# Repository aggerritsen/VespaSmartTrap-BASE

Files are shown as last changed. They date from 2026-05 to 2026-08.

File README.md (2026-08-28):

# VST-BASE

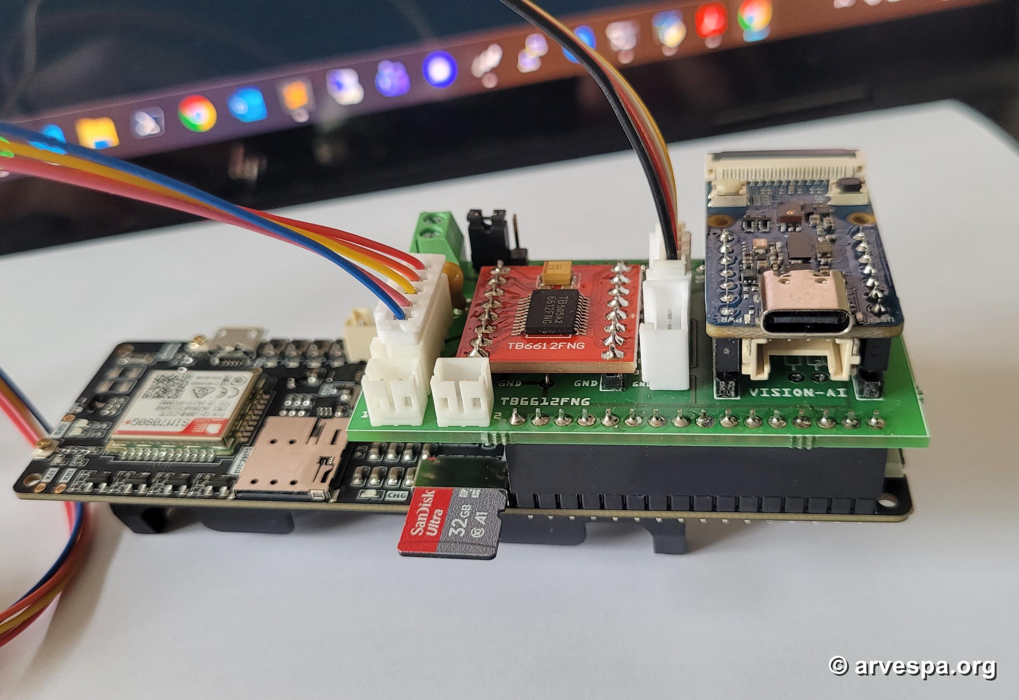
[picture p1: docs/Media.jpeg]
VST-BASE hardware


VST-BASE is the base-unit firmware, hardware integration reference, model tooling, and validation workspace for the Vespa Smart Trap project. The base unit is built around a LilyGO T-SIM7080G-S3 and receives inference metadata and JPEG frames from a Grove Vision AI V2 stick-on module through a custom PCB.

The root project is licensed under the GNU General Public License version 3.0. Keep source, build scripts, technical notes, and hardware references auditable and reproducible so that other developers can inspect, modify, rebuild, and redistribute the work under the repository's GNU license terms.

## Functionality

The current base firmware provides the following operational features:

- Power-on self test (POST) covering CPU, flash, heap, PSRAM, reset reason, SD card, configuration, modem, GNSS command path, UART, power telemetry, and actuator readiness.
- SD-MMC storage for configuration, boot reports, frame logs, power logs, and selected JPEG captures.
- SIM7080 modem initialization using TinyGSM, including AT readiness checks and network-time acquisition.
- Runtime Azure Blob upload of saved positive and configured doubtful detections, with independent cooldown and failure cooldown.
- Runtime SMS notification after positive detections, with provider-aware direct-SMS gating, recipient list, and cooldown.
- GNSS probing through the SIM7080 command interface, with optional GNSS UTC fallback when network time is unavailable and a trusted position is present.
- Binary UART receiver for the Grove Vision AI V2 module using `VSTS` state frames and `VSTJ` JPEG frames with metadata and CRC32 validation.
- Inference filtering by class, positive confidence threshold, doubtful confidence threshold, and occurrence count within a configurable time window before actuation.
- TB6612FNG stepper output for a configurable actuator cycle, including an optional boot-time POST cycle and a detection-triggered cycle.
- Short status LED POST test on GPIO 3 / D0 before runtime health LED policy is applied.
- WiFi web view in access-point or station mode, serving the latest verified frame and inference metadata over HTTP.
- JSON Lines frame logging with timestamp, GNSS data, inference result, bounding box, CRC status, actuator result, SMS/Azure result, saved filename, and firmware identity.
- Power telemetry logging to `/power.log` at a configurable interval.
- Solar auto-optimize mode that forces low-power runtime behavior from config: no WiFi, GNSS sampled once during boot, modem powered down after POST and runtime uploads, longer sleep protection, and reduced optional network checks.
- GV2 power control on the custom PCB: power down before deep sleep, power up after wake, and a short reset cycle before UART receive starts.
- Helper scripts for building and flashing the Grove Vision AI V2 firmware image and model.
- [VSTtool](https://vsttool.org) support for flashing firmware to the MCUs used in the project.
- Desktop image-viewer tooling and sample images for visual validation work.

## System Architecture

```text
T-SIM7080G-S3 base unit
        |
        +-- ESP32-S3 receiver firmware
        +-- SIM7080 modem time and GNSS probe
        +-- SD-MMC configuration, logs, and JPEG storage
        +-- WiFi HTTP image and state view
        +-- TB6612FNG stepper actuator output
        +-- USB serial POST and heartbeat monitor
        |
        +-- custom PCB interconnect
              |
              +-- Grove Vision AI V2 stick-on module
                    +-- camera
                    +-- YOLO11 object-detection model
                    +-- UART inference metadata and JPEG output
```

The T-SIM7080G-S3 is the base controller. The Grove Vision AI V2 is treated as an attached vision module, not as the system broker. The custom PCB provides the electrical and mechanical interface between the base, vision module, and actuator hardware references.

## 3D Housing

The physical camera-trap enclosure is documented in [3D/README.md](3D/README.md). That folder contains the prototype field-test manual, mechanical drawing PDF, STEP assembly, U3D model, DWG drawing views, and prototype photos for the VespaSmartTrap-ONE housing.

| Field prototype | Front/service side | Internal trap path |
| --- | --- | --- |
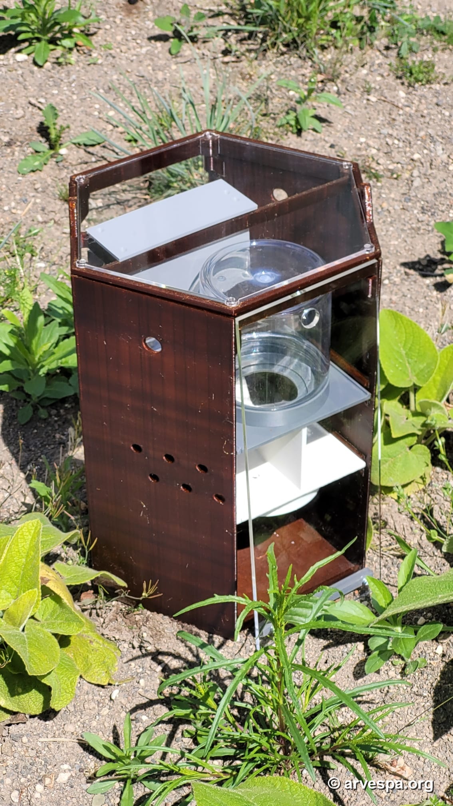
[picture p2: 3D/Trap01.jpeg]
VespaSmartTrap prototype in field conditions
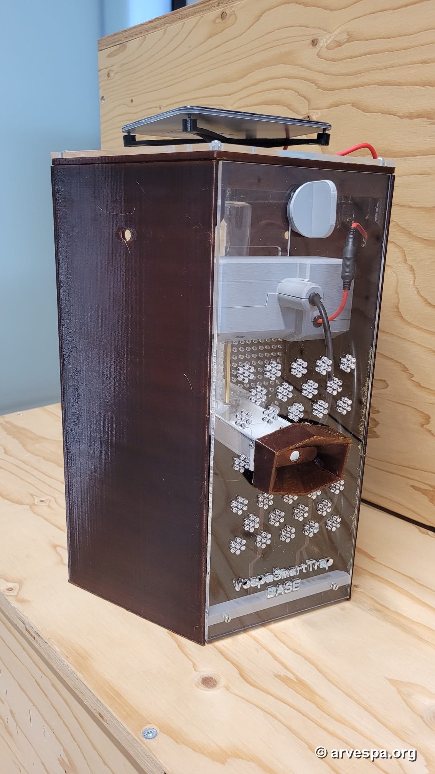
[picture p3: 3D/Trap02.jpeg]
VespaSmartTrap prototype front panel with electronics and actuator housing
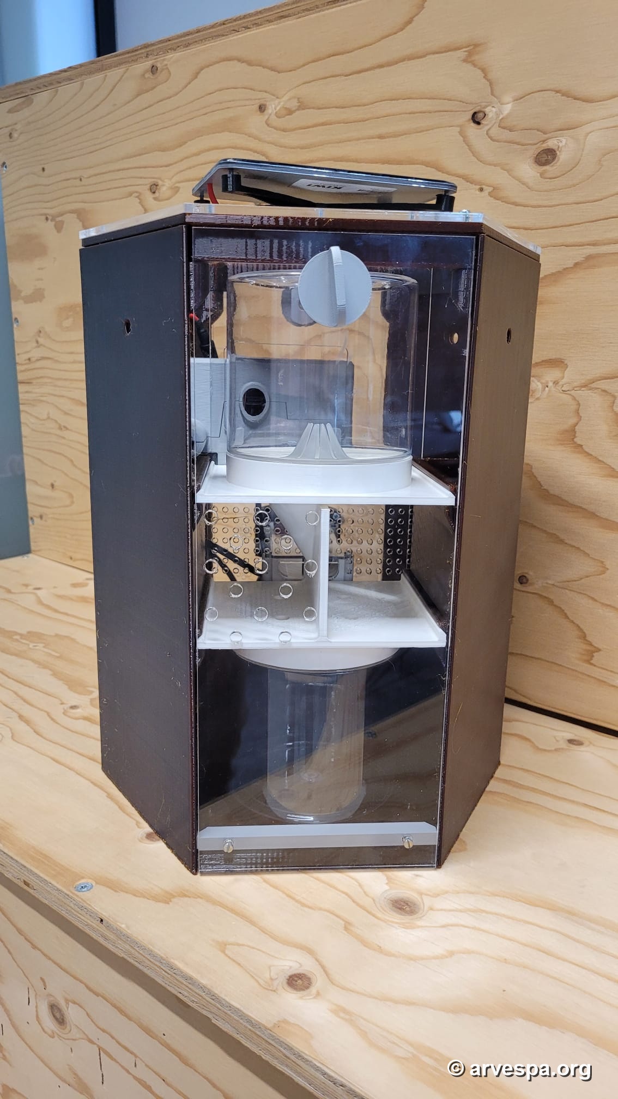
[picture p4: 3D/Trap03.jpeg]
VespaSmartTrap prototype internal funnel and trap jar path
|  |  |  |

## Technical Specifications

| Area | Specification |
| --- | --- |
| Base board | LilyGO T-SIM7080G-S3, built as `esp32-s3-devkitc-1` |
| Framework | PlatformIO, Arduino ESP32 core |
| Firmware version | `0.2.0` in `t-sim/firmware/src/version.h` |
| Flash | 16 MB, `huge_app.csv` partition table |
| PSRAM | Enabled, OPI/QIO memory configuration |
| USB serial | COM5 default, 115200 baud monitor |
| Upload | COM5 default, 921600 baud upload |
| GV2 UART | Serial2, GPIO 16 RX, GPIO 17 TX, 921600 baud default |
| GV2 protocol | `VSTS` state frames, `VSTJ` JPEG frames, CRC32 over JPEG payload |
| GV2 power control | GPIO 43 on the custom PCB, OFF during deep sleep and reset-cycled before UART start |
| Modem UART | Serial1, GPIO 4 RX, GPIO 5 TX |
| Modem power key | GPIO 41 |
| PMU | AXP2101 over I2C, SDA GPIO 15, SCL GPIO 7 |
| SD-MMC | 1-bit mode, CMD GPIO 39, CLK GPIO 38, DATA GPIO 40 |
| Actuator driver | TB6612FNG stepper output |
| Stepper pins | PWMA GPIO 9, AIN2 GPIO 10, AIN1 GPIO 11, BIN2 GPIO 12, BIN1 GPIO 13, PWMB GPIO 14 |
| Status output | Right LED / actuator-active signal on GPIO 3 / D0 |
| Web service | HTTP port 80, endpoints `/`, `/state.json`, `/frame.jpg` |
| Model target | Grove Vision AI V2 |
| Current model path | `gv2/firmware/model_zoo/tflm_yolo11_od/` |
| Current model files | `gv2-yolo11n-vespa-2026-02v1.tflite`, `gv2-yolo11n-vespa-2026-05top.tflite` |
| Model flash offset | `0xB7B000` |
| Model class short names | Configurable, defaults: `amel`, `vcra`, `vesp`, `vvel` |

## Repository Layout

```text
t-sim/firmware/               PlatformIO firmware for the T-SIM7080G-S3 base
t-sim/firmware/src/           Receiver firmware modules
t-sim/firmware/platformio.ini ESP32-S3 build, upload, monitor, and library config
t-sim/firmware/huge_app.csv   16 MB flash partition table
3D/                           Mechanical housing docs, CAD assets, drawing views, and prototype photos
docs/                         Architecture, protocol, hardware, GNSS, SD, and bring-up notes
docs/hardware/                Datasheets, pinouts, photos, and hardware references
gv2/firmware/                 Local isolated Grove Vision AI V2 firmware, image tools, and active model zoo
external/t-sim-motor-shield/  Submodule: custom PCB / motor shield reference
tools/image-viewer/           Desktop random image viewer and sample images
tools/receiver/               Receiver helper scripts
tools/Himax_AI_web_toolkit/   Local copy of the Himax web flashing toolkit
tools/power_uptime_visual.py  Builds the power/autonomy CSV and matplotlib timeline
data/power_uptime_dataset.csv Derived power/autonomy dataset from SD logs
data/power_uptime_plot.png    Power, operating-state, and temperature graph
gv2/build_gv2_image.ps1       GV2 firmware image build helper
gv2/flash_gv2.ps1             GV2 firmware and model flash helper
```

Submodules are intentionally kept under `external/` to make ownership and licensing boundaries clear.

## Firmware Boot Flow

At startup the receiver:

1. Starts USB serial and prints system information.
2. Initializes the SD card, creates `/config.json` when missing, and loads runtime configuration.
3. Enables modem rails and probes SIM7080 AT readiness.
4. Validates LTE-M/APN when modem mode is `2`, using SIM identity profiles first and candidate probing as fallback.
5. Attempts to obtain network time and set system time.
6. Optionally sends a POST SMS probe when `sms.post_test_enabled` is true.
7. Optionally uploads a small POST log probe when `azure.log_post_test_enabled` is true.
8. Powers and probes GNSS, optionally using trusted GNSS UTC as a fallback time source.
9. Powers the modem down after POST unless `modem.keep_alive_after_post` is true.
10. Starts the WiFi web service when enabled.
11. Initializes power telemetry and the stepper actuator.
12. Runs a short status LED POST test on GPIO 3 / D0.
13. Runs the optional stepper POST cycle when `stepper.post_test_enabled` is true.
14. Reset-cycles GV2 power on GPIO 43, starts GV2 UART, writes `/post.log`, and enters receive mode.

## UART Protocol

The base expects binary frames from the current GV2 firmware:

```text
State frame:
VSTS + state_u8

Heartbeat frame:
VSTH + status_u8 + counter_u32_le

JPEG frame:
VSTJ + state_u8 + class_idx_u8 + conf_u8
     + bbox_x_u16_le + bbox_y_u16_le + bbox_w_u16_le + bbox_h_u16_le
     + jpeg_len_u32_le + crc32_u32_le + jpeg_bytes
```

The GV2 heartbeat is an idle keepalive: it is sent after about 10 seconds of no other UART frames from GV2. A state change, JPEG frame, or error frame resets the heartbeat timer.

The JPEG payload length is the trimmed JPEG length through the actual `FFD9` marker. CRC32 is calculated over exactly those JPEG bytes. The receiver only treats a frame as complete after the declared payload has arrived, CRC32 matches, and the JPEG structure is valid.

## Detection And Actuation

The receiver evaluates each valid JPEG frame against the configured inference filter:

- `confidence_threshold`: required confidence as `0.0` to `1.0`.
- `doubtful_confidence_threshold`: lower confidence band used for evidence-only Azure upload.
- `detected_class`: target class index, or `-1` to accept any class.
- `occurrence`: number of matching frames required inside the occurrence window.
- `occurrence_window_seconds`: time window in which the required matches must occur.
- `upload_doubtful_to_azure`: when true, saves and runtime-uploads matching-class frames between the doubtful and positive thresholds.

When the positive threshold and occurrence count are reached inside the configured window, the firmware runs the configured stepper actuator cycle, flushes and resynchronizes the UART receive path after the blocking actuator movement, saves the triggering JPEG when the SD card is available, optionally sends SMS, and attempts runtime Azure upload. The occurrence counter resets after the actuator event.

Doubtful frames do not trigger the stepper and do not send SMS. When enabled, they are saved and sent through the same runtime Azure upload path. With `power.solar_auto_optimize=true`, doubtful-frame upload is disabled at runtime even if the loaded config sets `upload_doubtful_to_azure=true`; positive detections still use runtime photo upload.

## SD Card Files

The firmware creates or writes these files on the SD card:

```text
/config.json                  Runtime configuration, created if missing
/post.log                     Boot POST summary, overwritten each boot
/frames.log                   JSON Lines frame and detection log
/power.log                    JSON Lines power telemetry log
/vvel_0.859_YYYYMMDD_HHMMSS_000123.jpg Saved JPEGs with class short name and confidence
/vvel_0.859_uptime_0000000000_000123.jpg Fallback JPEG naming when time is unavailable
```

`/frames.log` includes device identity, firmware version, GNSS fields, inference state, bounding box, positive/doubtful filter result, CRC result, actuator result, SMS result, Azure result, cooldown status, and saved filename.

The firmware removes legacy Azure queue files (`/azure_queue.log`, `/azure_queue.work`, `/azure_queue.tmp`) on SD mount. New firmware does not use an upload queue.

Log rotation uses the same `logging` settings in VBUS and solar mode. `rotation_interval_minutes` accepts `60`, `360`, `720`, or `1440`, giving one shared rotation cadence for `health`, `power`, and `frames` logs. Closed log files are moved to `/log/archive/YYYYMMDD/` with timestamped names. Existing current logs found after boot are archived as `*_preboot_<timestamp>.jsonl` once valid time is available. Archive day folders older than `retention_days` are removed during rotation.

`upload_interval_minutes`, `upload_max_files_per_run`, and `upload_min_battery_percent` control scheduled upload of rotated log archives. The firmware scans `/log/archive/YYYYMMDD/` for the oldest `.jsonl` files, uploads at most `upload_max_files_per_run` per cycle to the Azure `logs` prefix, and deletes each local archive only after a successful upload. Failed uploads remain on SD and are retried during the next cycle. The upload policy is intentionally separate from `power.solar_auto_optimize`; solar mode must not silently change log retention or upload cadence.

## Power Autonomy Analysis

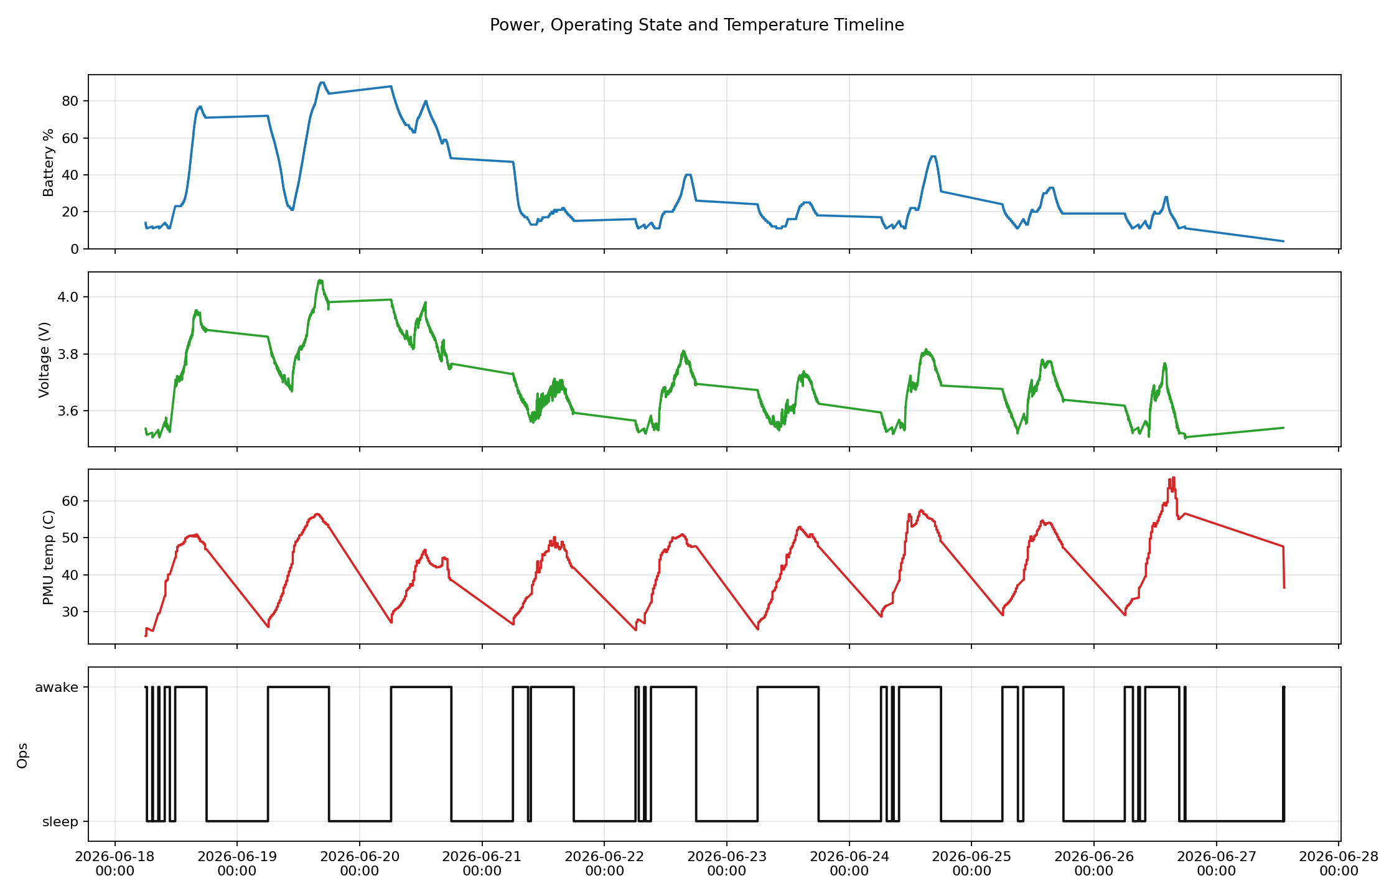
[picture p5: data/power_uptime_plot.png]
Power autonomy graph


The graph above is generated from the SD-card `health.log` and `power.log` files with:

```powershell
python tools\power_uptime_visual.py
```

The derived CSV is written to `data/power_uptime_dataset.csv`. The plotted operating-state line uses `awake` for normal logging/operation and `sleep` for inferred deep-sleep or offline gaps between health records.

From June 18 onward, the logs show a clear low-battery recovery followed by stable solar-supported operation. On June 18, the system clearly entered the 10% battery-protection region: the operating-state line shows repeated sleep/wake behavior, and the battery percentage and voltage start near the low-protection range. Later that day the battery recovers strongly.

On the following sunny days, June 19 and June 20, the system reaches almost full daytime realization, around 99% of the intended active window. The charge and discharge curves are smooth and plausible: the battery charges during sunny periods, discharges under load and overnight, and the PMU temperature follows the expected daytime thermal rise and nighttime cooldown.

This indicates that the 6 W solar panel is likely sufficient for this setup under the measured sunny conditions. The system can recover from low battery, sustain normal daytime operation, and retain enough charge margin across subsequent days.

## Configuration

Configuration is read from `/config.json` on the SD card. If it does not exist, the firmware writes a default file. Key fields include:

```json
{
  "schema_version": 1,
  "device_name": "VST-BASE",
  "uart": {
    "rx_gpio": 16,
    "tx_gpio": 17,
    "baud": 921600
  },
  "logging": {
    "post_log": "/post.log",
    "image_prefix": "/frame_",
    "rotation_interval_minutes": 60,
    "retention_days": 7,
    "upload_enabled": true,
    "upload_interval_minutes": 180,
    "upload_max_files_per_run": 4,
    "upload_min_battery_percent": 35
  },
  "features": {
    "gnss_probe": true,
    "ack_frames": true
  },
  "time": {
    "network_timeout_seconds": 60,
    "allow_gnss_fallback": true
  },
  "modem": {
    "mode": 2,
    "apn": "onomondo",
    "apn_autodetect": true,
    "apn_test_all": false,
    "validate_http_egress": false,
    "operator_auto_select": true,
    "keep_alive_after_post": false,
    "wake_for_runtime_sms": true,
    "apn_candidates": [
      { "supplier": "Onomondo", "apn": "onomondo" },
      { "supplier": "KPNThings", "apn": "internet.m2m" },
      { "supplier": "Wireless Logic Benelux", "apn": "" },
      { "supplier": "ThingsData/Tele2 2G-4G", "apn": "m2m.tele2.com" },
      { "supplier": "ThingsData/Tele2 5G", "apn": "iot.tele2.com" }
    ],
    "sim_profiles": [
      {
        "supplier": "Onomondo",
        "apn": "onomondo",
        "direct_sms": false,
        "imsi_prefixes": ["23450", "23873"],
        "iccid_prefixes": ["894573"]
      },
      {
        "supplier": "Wireless Logic Benelux",
        "apn": "internet.m2m",
        "direct_sms": true,
        "imsi_prefixes": ["20408"],
        "iccid_prefixes": []
      },
      {
        "supplier": "KPNThings",
        "apn": "internet.m2m",
        "direct_sms": true,
        "imsi_prefixes": ["20408"],
        "iccid_prefixes": []
      },
      {
        "supplier": "ThingsData/Tele2 2G-4G",
        "apn": "m2m.tele2.com",
        "direct_sms": true,
        "imsi_prefixes": ["20402", "24007"],
        "iccid_prefixes": ["894620"]
      }
    ],
    "lookup_primary": "1.1.1.1",
    "lookup_secondary": "8.8.8.8"
  },
  "stepper": {
    "speed_steps_per_second": 400,
    "rotation_degrees": 90,
    "steps_per_revolution": 2048,
    "reverse_wait_ms": 1000,
    "start_direction": "cw",
    "post_test_enabled": true
  },
  "inference": {
    "confidence_threshold": 0.80,
    "doubtful_confidence_threshold": 0.70,
    "upload_doubtful_to_azure": true,
    "detected_class": 3,
    "occurrence": 3,
    "occurrence_window_seconds": 30,
    "class_names": [
      { "class": 0, "short": "amel", "name": "Apis mellifera" },
      { "class": 1, "short": "vcra", "name": "Vespa crabro" },
      { "class": 2, "short": "vesp", "name": "Vespula sp." },
      { "class": 3, "short": "vvel", "name": "Vespa velutina" }
    ]
  },
  "power": {
    "log_interval_seconds": 900,
    "solar_auto_optimize": true,
    "deep_sleep": 2,
    "deep_sleep_start_hour": 18,
    "deep_sleep_end_hour": 6,
    "low_battery_sleep_percent": 10,
    "low_battery_wake_interval_minutes": 60,
    "reboot_cron": "",
    "reboot_after_deep_sleep_wakeup": false
  },
  "health": {
    "led": 1
  },
  "azure": {
    "cooldown_minutes": 15,
    "failure_cooldown_seconds": 120,
    "runtime_connect_timeout_seconds": 20,
    "photos_prefix": "photos",
    "logs_prefix": "logs",
    "log_post_test_enabled": true
  },
  "sms": {
    "enabled": false,
    "post_test_enabled": false,
    "runtime_settle_ms": 2000,
    "runtime_delay_after_detection_seconds": 0,
    "runtime_submit_timeout_ms": 60000,
    "cooldown_minutes": 15,
    "failure_cooldown_seconds": 900,
    "recipients": []
  },
  "web": {
    "mode": 2,
    "ssid": "VST-BASE",
    "password": "",
    "append_mac": true
  }
}
```

The default file deliberately keeps ordinary VBUS-friendly values such as `web.mode=2`, `health.led=1`, and `inference.upload_doubtful_to_azure=true`, but `power.solar_auto_optimize` is `true` by default. On boot, that flag converts some loaded configuration values to the lower-power effective runtime settings listed below. Set `power.solar_auto_optimize=false` to use the explicit values as-is, for example in VBUS/debug mode.

### Power Profiles

Use `power.solar_auto_optimize` as the profile switch. When it is `false`, the firmware follows the explicit values in `/config.json`. When it is `true`, the firmware keeps the configured identity, APN, inference class, thresholds, actuator settings, and upload credentials, but applies the lowest-power runtime policy after config parsing.

Solar auto-optimize forces these effective settings at runtime:

```json
{
  "features": {
    "gnss_probe": true
  },
  "time": {
    "network_timeout_seconds": 30,
    "allow_gnss_fallback": true
  },
  "modem": {
    "keep_alive_after_post": false,
    "wake_for_runtime_sms": true,
    "apn_test_all": false,
    "validate_http_egress": false
  },
  "inference": {
    "upload_doubtful_to_azure": false
  },
  "power": {
    "deep_sleep": 2,
    "deep_sleep_start_hour": 18,
    "deep_sleep_end_hour": 8,
    "low_battery_sleep_percent": 25,
    "low_battery_wake_interval_minutes": 120
  },
  "azure": {
    "cooldown_minutes": 60,
    "failure_cooldown_seconds": 1800,
    "runtime_connect_timeout_seconds": 20,
    "photos_prefix": "photos",
    "logs_prefix": "logs",
    "log_post_test_enabled": true
  },
  "sms": {
    "post_test_enabled": false
  },
  "web": {
    "mode": 0
  }
}
```

Recommended Solar profile:

```json
{
  "features": {
    "gnss_probe": true,
    "ack_frames": true
  },
  "time": {
    "network_timeout_seconds": 30,
    "allow_gnss_fallback": true
  },
  "modem": {
    "mode": 2,
    "apn": "onomondo",
    "apn_autodetect": true,
    "apn_test_all": false,
    "validate_http_egress": false,
    "operator_auto_select": true,
    "keep_alive_after_post": false,
    "wake_for_runtime_sms": true
  },
  "inference": {
    "confidence_threshold": 0.80,
    "doubtful_confidence_threshold": 0.70,
    "upload_doubtful_to_azure": false,
    "detected_class": 3,
    "occurrence": 3,
    "occurrence_window_seconds": 30
  },
  "power": {
    "log_interval_seconds": 900,
    "solar_auto_optimize": true,
    "deep_sleep": 2,
    "deep_sleep_start_hour": 18,
    "deep_sleep_end_hour": 8,
    "low_battery_sleep_percent": 25,
    "low_battery_wake_interval_minutes": 120,
    "reboot_cron": "",
    "reboot_after_deep_sleep_wakeup": false
  },
  "health": {
    "led": 1
  },
  "azure": {
    "cooldown_minutes": 60,
    "failure_cooldown_seconds": 1800,
    "runtime_connect_timeout_seconds": 20,
    "photos_prefix": "photos",
    "logs_prefix": "logs",
    "log_post_test_enabled": true
  },
  "sms": {
    "enabled": false,
    "post_test_enabled": false
  },
  "web": {
    "mode": 0
  }
}
```

In this profile GNSS is sampled once during boot with `AT+CGNSPWR=1`, the resulting trusted location/time is kept in memory and logs, and the modem is powered down after POST. Runtime Azure/SMS paths wake LTE only for the transfer window and power it down again. `power.solar_auto_optimize` does not override `health.led`; health-status blinking runs only when `health.led=1` and USB/VBUS power is present. The status LED is also driven on while an actuator cycle is running in any power mode.

The measured solar logs support stopping at `18:00`: it avoids evening discharge and preserves battery for the next boot. Starting at `08:00` is practical, but `09:00` or `10:00` is safer for maximum autonomy. For a harsher winter or cloudy profile, use `deep_sleep_start_hour=17` and `deep_sleep_end_hour=10`.

Recommended VBUS profile:

```json
{
  "features": {
    "gnss_probe": true,
    "ack_frames": true
  },
  "time": {
    "network_timeout_seconds": 60,
    "allow_gnss_fallback": true
  },
  "modem": {
    "mode": 2,
    "apn": "onomondo",
    "apn_autodetect": true,
    "apn_test_all": false,
    "validate_http_egress": false,
    "operator_auto_select": true,
    "keep_alive_after_post": false,
    "wake_for_runtime_sms": true
  },
  "inference": {
    "confidence_threshold": 0.80,
    "doubtful_confidence_threshold": 0.70,
    "upload_doubtful_to_azure": true,
    "detected_class": 3,
    "occurrence": 3,
    "occurrence_window_seconds": 30
  },
  "power": {
    "log_interval_seconds": 900,
    "solar_auto_optimize": false,
    "deep_sleep": 0,
    "deep_sleep_start_hour": 18,
    "deep_sleep_end_hour": 6,
    "low_battery_sleep_percent": 10,
    "low_battery_wake_interval_minutes": 60,
    "reboot_cron": "",
    "reboot_after_deep_sleep_wakeup": false
  },
  "health": {
    "led": 1
  },
  "azure": {
    "cooldown_minutes": 15,
    "failure_cooldown_seconds": 120,
    "runtime_connect_timeout_seconds": 20,
    "photos_prefix": "photos",
    "logs_prefix": "logs",
    "log_post_test_enabled": true
  },
  "web": {
    "mode": 2,
    "ssid": "VST-BASE",
    "password": "",
    "append_mac": true
  }
}
```

VBUS mode can keep the health LED and web AP enabled for field inspection. Keep `modem.keep_alive_after_post=false` unless you are actively debugging LTE behavior; runtime upload and SMS already wake the modem when needed.

`device_name` is suffixed at runtime with the WiFi MAC suffix, matching the web SSID style, for example `VST-BASE-A62E94`. `web.mode` values are `0` for disabled, `1` for WiFi station mode, and `2` for access-point mode. `stepper.start_direction` accepts common clockwise and counter-clockwise forms such as `cw`, `clockwise`, `ccw`, and `anti-clockwise`.

Azure image upload is runtime-only. A saved positive or configured doubtful image is uploaded immediately when the Azure cooldown allows. If cooldown is active the image remains saved on SD but is not queued. If upload fails, the failure cooldown is applied and the image is not queued.

Azure uploads use one configured container and separate blob prefixes inside it. Photos default to `photos/...`; the optional POST log-upload probe defaults to `logs/...`. Set `azure.log_post_test_enabled=true` to write and upload a small JSON Lines test file during POST after LTE-M validation and before the modem is powered down. Rotated log archives upload to `logs/<device_name>/<YYYYMMDD>/<filename>.jsonl` and are removed from SD after successful upload.

SMS is runtime-only unless `sms.post_test_enabled` is explicitly true. `sms.enabled` is authoritative: recipients may be present while SMS remains disabled. SMS is skipped for providers whose selected SIM profile has `direct_sms=false`, such as Onomondo in the default profile set.

The modem APN is selected from SIM identity first (`sim_profiles` by IMSI/ICCID prefixes), then by configured APN candidate probing. Known default profiles cover Onomondo, Wireless Logic Benelux, KPNThings, and ThingsData/Tele2 2G-4G.

`power.reboot_cron` uses a five-field cron-like schedule after valid system time is available. For example, `0 12 * * *` reboots daily at noon. Leave it empty to disable scheduled reboot.

Low-battery protection is separate from the scheduled sleep window. With `power.solar_auto_optimize=true`, a battery-powered unit sleeps when the PMU reports `25%` or lower and wakes every `120` minutes to re-check the battery. If solar has recovered the battery above the configured threshold, normal startup continues; otherwise it returns to deep sleep before modem, web, stepper, or GV2 runtime work starts. If the unit is inside the programmed sleep window, or the next low-battery check would wake inside that window, the firmware sleeps through to the configured wake hour. With `power.solar_auto_optimize=false`, the explicit configured low-battery threshold and wake interval are used.

## Build And Flash The Base Firmware

Install PlatformIO, connect the T-SIM7080G-S3, then run:

```powershell
cd firmware
.\run.ps1
```

The helper uploads to COM5 and opens the serial monitor on COM5 at 115200 baud by default. Override the ports when needed:

```powershell
.\run.ps1 -UploadPort COM5 -MonitorPort COM5
```

The underlying PlatformIO environment is `t-sim7080g-s3`.

[VSTtool](https://vsttool.org) also exists as a dedicated flashing utility for firmware updates on the MCUs used by VST-BASE. Use it when you need a single tool-oriented flashing workflow instead of the board-specific helper scripts above and below.

## Build And Flash The GV2 Firmware

Initialize submodules before building GV2 assets:

```powershell
git submodule update --init --recursive
```

Build the GV2 firmware image:

```powershell
.\gv2\build_gv2_image.ps1
```

Flash the GV2 firmware image and model:

```powershell
.\gv2\flash_gv2.ps1 -Port COM7
```

The flash helper uses `gv2/firmware/xmodem/xmodem_send.py` and expects the generated image at:

```text
gv2/firmware/we2_image_gen_local/output_case1_sec_wlcsp/output.img
```

The active GV2 model binaries are intentionally kept in the local GV2 firmware copy for reproducible release builds.

## Dependencies

Base firmware dependencies are declared in `t-sim/firmware/platformio.ini`:

- Arduino ESP32 core through PlatformIO `espressif32`.
- TinyGSM from `https://github.com/vshymanskyy/TinyGSM.git`.
- XPowersLib by `lewisxhe` for AXP2101 PMU support.
- ArduinoJson `^7.0.0`.
- ESP32 Arduino built-ins such as `SD_MMC`, `WiFi`, and `WebServer`.

GV2 firmware dependencies are isolated inside `gv2/firmware`.

## External Repositories

```text
gv2/firmware
  source: isolated local copy of the Grove Vision AI V2 firmware fork

external/t-sim-motor-shield
  url:    https://github.com/aggerritsen/T-SIMMotorShield.git
  branch: master
```

Clone with submodules:

```powershell
git clone --recurse-submodules <repo-url>
```

Or initialize them after cloning:

```powershell
git submodule update --init --recursive
```

## Public Development And GNU Licensing

This repository is licensed under the GNU General Public License version 3.0. See `LICENSE` for the full license text. For public releases, keep these practices in place:

- Preserve license notices in source files and third-party materials.
- Keep submodules and bundled tools in clearly separated directories so their upstream licenses remain identifiable.
- Document generated firmware, model binaries, and hardware artifacts well enough that users can rebuild or replace them.
- Avoid committing private credentials, SIM/APN secrets, WiFi passwords, certificates, or personal device identifiers.
- Prefer reproducible build commands and versioned configuration over local-only IDE state.

Third-party submodules and bundled tools may have their own licenses. Review those license files before redistributing combined firmware images, model packages, or hardware packages.

## Documentation Index

- `t-sim/firmware/README.md`: detailed receiver firmware behavior, pins, protocol, validation, and source-file map.
- `3D/README.md`: physical housing, CAD assets, mechanical drawing views, and prototype photos.
- `docs/architecture.md`: high-level hardware and firmware architecture.
- `docs/receiver-post.md`: POST behavior.
- `docs/sd-card-layout.md`: SD output notes.
- `docs/gv2-model-flashing.md`: GV2 firmware and model flashing notes.
- `docs/custom-pcb-bringup.md`: custom PCB bring-up guidance.
- `docs/gnss.md`: GNSS notes.
- `docs/hardware/`: pinouts, datasheets, board photos, and hardware references.

## Development Notes

- Keep base application changes in `t-sim/firmware/`.
- Keep GV2 firmware and model work in `gv2/firmware/`.
- Keep custom PCB and motor shield reference work in `external/t-sim-motor-shield/`.
- Update this README and the relevant detailed docs when changing public behavior, binary protocols, default pins, SD file formats, model names, or license posture.

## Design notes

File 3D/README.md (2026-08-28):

# 3D Housing and Mechanical Prototype

This folder contains the mechanical documentation for the physical camera-trap housing used by the Vespa Smart Trap prototype. It covers the enclosure, removable panels, bait/trap access, service checks, and CAD source files for the current prototype body.

## Prototype Photos

| Field prototype | Front/service side | Internal trap path |
| --- | --- | --- |
| VespaSmartTrap prototype in field conditions | VespaSmartTrap prototype front panel with electronics and actuator housing | VespaSmartTrap prototype internal funnel and trap jar path |

The prototype uses a smoked/transparent outer housing with internal printed parts for the bait area, funnel/trap path, service access, and electronics/camera mounting. The photos also show the top-mounted solar panel and external charging/data access.

## Primary Documents

- [Prototype field test manual](Concept_VespaSmartTrap-ONE_InstuctionMAnual_v02.pdf)  
  Field-test user manual for VespaSmartTrap-ONE. It includes setup, startup indicators, panel removal, bait replacement, trapped hornet removal, health checks, charging/data access, and daily test logging.
- [Prototype drawing PDF](ixid00000p5000_proto.pdf)  
  Mechanical drawing pack with front/back views, isometric views, exploded views, removal steps, plug access, and setup check drawings.

## CAD Assets

- [Assembly STEP model](ixid00000p5000_proto_asm.stp)  
  Main CAD interchange file for the prototype assembly. Use this as the source for CAD inspection, modification, and exporting derived print/manufacturing files.
- [U3D model](ixid00000p5000_proto.u3d)  
  3D model asset used for interactive/embedded 3D PDF workflows.
- [DWG drawing views](260622_isoviews_pdf_dwg/)  
  AutoCAD drawing files for each documented view and service step.

## DWG View Set

The `260622_isoviews_pdf_dwg` folder contains the drawing source for the PDF view sequence:

1. [Front/back views](260622_isoviews_pdf_dwg/ixid00000p5000_proto_1_views.dwg)
2. [Isometric view](260622_isoviews_pdf_dwg/ixid00000p5000_proto_2_iso.dwg)
3. [Front exploded view](260622_isoviews_pdf_dwg/ixid00000p5000_proto_3_explode_front.dwg)
4. [Back exploded view](260622_isoviews_pdf_dwg/ixid00000p5000_proto_4_explode_back.dwg)
5. [Explanation view](260622_isoviews_pdf_dwg/ixid00000p5000_proto_5_explain.dwg)
6. [Remove back panel](260622_isoviews_pdf_dwg/ixid00000p5000_proto_6_remove_backpanel.dwg)
7. [Remove trap](260622_isoviews_pdf_dwg/ixid00000p5000_proto_7_remove_trap.dwg)
8. [Remove bait](260622_isoviews_pdf_dwg/ixid00000p5000_proto_8_remove_bait.dwg)
9. [Remove front panel](260622_isoviews_pdf_dwg/ixid00000p5000_proto_9_remove_front_panel.dwg)
10. [Open plug](260622_isoviews_pdf_dwg/ixid00000p5000_proto_10_open_plug.dwg)
11. [Setup check](260622_isoviews_pdf_dwg/ixid00000p5000_proto_11_setup_check.dwg)

## Relationship to the Electronics

The housing is the mechanical counterpart to the VST-BASE electronics and firmware:

- [Project overview](../README.md)
- [System architecture](../docs/architecture.md)
- [T-SIM receiver firmware](../t-sim/README.md)
- [GV2 camera/inference module](../gv2/README.md)
- [Direct GV2 to T-SIM protocol](../docs/direct-gv2-to-t-sim.md)
- [Custom PCB bring-up](../docs/custom-pcb-bringup.md)

The firmware-side actuation cycle is driven by the configured stepper motor behavior after a matching Vespa velutina detection. The mechanical model here documents the trap body and access flow around that actuator-driven path.

## Notes

- No standalone `.stl` files are currently present in this folder. The available manufacturing source is the STEP assembly plus DWG drawing set.
- Print settings, material choice, nozzle size, layer height, supports, and orientation are not specified in the checked-in files yet.
- The field-test manual is the best source for operational handling: cleaning, bait replacement, trap removal, charging, data access, and daily inspection.

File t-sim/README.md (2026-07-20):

# T-SIM7080G-S3 Base Firmware

This PlatformIO project contains the owned receiver firmware for the VST-BASE T-SIM7080G-S3 base unit.

The firmware receives binary inference state and JPEG frames from the Grove Vision AI V2 stick-on module over the custom PCB UART link. It performs boot diagnostics, initializes the modem and SD card, writes POST/frame logs, validates inference/JPEG frames, runs the configured stepper actuator cycle after enough matching detections within the configured occurrence window, and saves matching JPEGs to SD.

## Hardware Role

```text
Grove Vision AI V2 stick-on module
        |
        | T-SIM Serial2, 921600 baud, custom PCB
        v
T-SIM7080G-S3 base firmware
        |
        +-- SIM7080 modem time
        +-- SIM7080 GNSS probe
        +-- SD-MMC image and POST logging
        +-- Optional WiFi HTTP image and inference view
        +-- TB6612FNG stepper actuator output
        +-- USB serial POST/heartbeat monitor
```

## Board Pinout

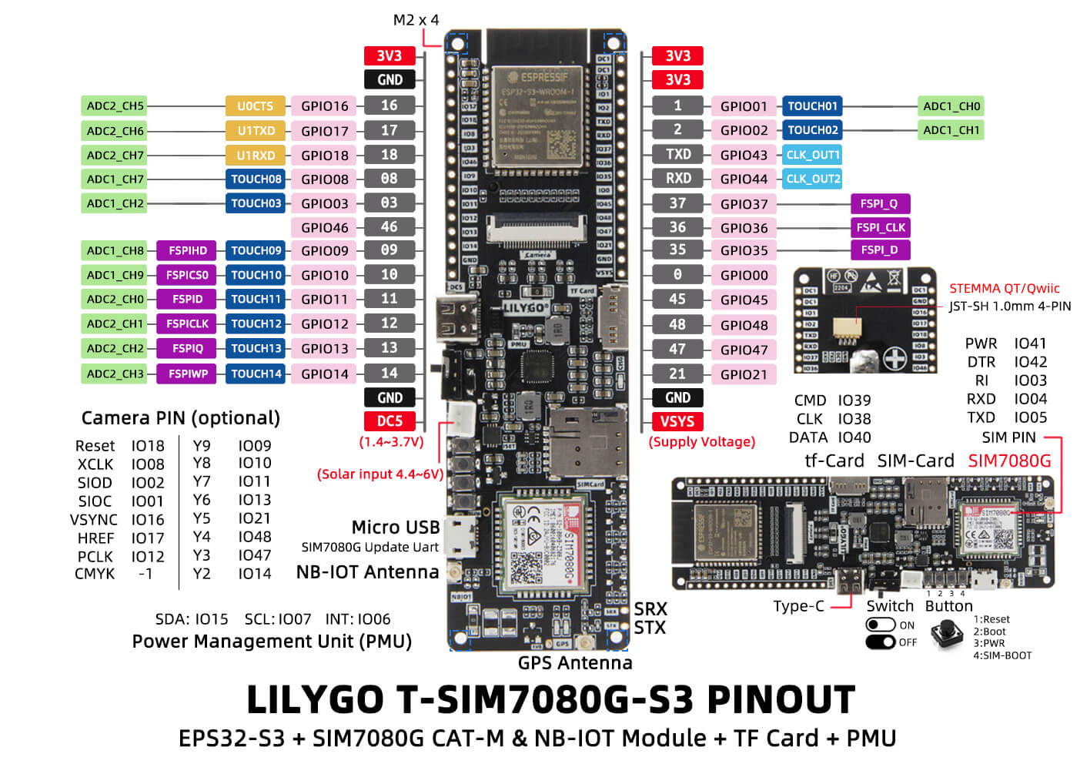
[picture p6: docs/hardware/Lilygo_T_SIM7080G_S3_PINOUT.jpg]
LILYGO T-SIM7080G-S3 Pinout


For more board details, see the [LilyGO T-SIM7080G repository](https://github.com/Xinyuan-LilyGO/LilyGo-T-SIM7080G).

## Pins And Ports

| Function | Pin / Port | Notes |
| --- | --- | --- |
| USB serial monitor | COM5, 115200 baud | POST and heartbeat output |
| PlatformIO monitor | COM5, 115200 baud | Configured in `platformio.ini` |
| GV2 UART RX | GPIO 16 default, Serial2 RX | Configurable via `/config.json` |
| GV2 UART TX | GPIO 17 default, Serial2 TX | Configurable via `/config.json` |
| GV2 UART baud | 921600 | 32 KB RX buffer for larger 4X JPEG bursts |
| GV2 power enable | GPIO 43 default | Drives the external BC337 low-side switch control: HIGH while awake, LOW before deep sleep |
| Modem RX | GPIO 4, Serial1 RX | SIM7080 AT interface |
| Modem TX | GPIO 5, Serial1 TX | SIM7080 AT interface |
| Modem PWRKEY | GPIO 41 | Pulsed if AT does not respond |
| PMU SDA | GPIO 15 | AXP2101 I2C |
| PMU SCL | GPIO 7 | AXP2101 I2C |
| SD CMD | GPIO 39 | SD-MMC 1-bit mode |
| SD CLK | GPIO 38 | SD-MMC 1-bit mode |
| SD DATA | GPIO 40 | SD-MMC 1-bit mode |
| D0 / actuator active | GPIO 3 / D0 | Custom PCB exposed output; HIGH while the configured stepper actuator cycle is in progress, including POST test |
| D1 / reserved input | GPIO 46 / D1 | Custom PCB exposed input-only line; reserved, not usable as a driven output |
| Stepper PWMA | GPIO 9 | TB6612FNG channel A PWM |
| Stepper AIN2 | GPIO 10 | TB6612FNG channel A input |
| Stepper AIN1 | GPIO 11 | TB6612FNG channel A input |
| Stepper BIN2 | GPIO 12 | TB6612FNG channel B input |
| Stepper BIN1 | GPIO 13 | TB6612FNG channel B input |
| Stepper PWMB | GPIO 14 | TB6612FNG channel B PWM |

## Boot Flow

On startup, `setup()` performs:

1. Starts USB serial, prints system information, and flashes the D0/status LED three times to mark POST start.
2. Initializes SD-MMC with custom T-SIM7080G-S3 pins.
3. Ensures `/config.json` exists, adds any missing default fields, and loads config.
4. Enables modem rails through the AXP2101 PMU.
5. Probes the SIM7080 with AT commands.
6. Runs the configured modem mode.
7. Reads `AT+CCLK?` into `YYYYMMDD_HHMMSS` format and sets system time if valid when modem time is enabled.
8. Powers GNSS with `AT+CGNSPWR=1` and samples `AT+CGNSINF` for up to 10 seconds when GNSS probing or fallback is enabled.
9. If configured local time is inside the deep-sleep window, stops the GV2 UART, sets the GV2 UART pins high-Z, drives the GV2 power-enable GPIO LOW, shuts down modem/GNSS rails, and enters ESP32 deep sleep until the configured wake hour.
10. Starts the WiFi web service when enabled in config.
11. Initializes power telemetry.
12. Initializes the TB6612FNG stepper output.
13. Runs one stepper POST test cycle: configured `start_direction`, waits `reverse_wait_ms`, configured return rotation.
14. Initializes `Serial2` for the GV2 link after the blocking POST test, so stale GV2 bytes cannot accumulate in the UART buffer during actuator movement.
15. Writes `/post.log` to the SD card when the card is available.
16. Prints a POST summary.
17. Enters receive mode.

The loop prints a diagnostic heartbeat with heap, modem, time, GNSS, UART, SD, and receive counters at the same cadence as `power.log_interval_seconds`. Power telemetry is queried and appended to `/power.log` only at that same interval. GV2 receive output is event-driven: the important line is printed when a JPEG frame has fully arrived and has been validated, filtered, optionally actuated, and optionally saved.

## UART Protocol

The receiver expects binary frames from the current GV2 firmware.

```text
State frame:
VSTS + state_u8

Heartbeat frame:
VSTH + status_u8 + counter_u32_le

JPEG frame:
VSTJ + state_u8 + class_idx_u8 + conf_u8 + bbox_x_u16_le + bbox_y_u16_le + bbox_w_u16_le + bbox_h_u16_le + jpeg_len_u32_le + crc32_u32_le + jpeg_bytes
```

The heartbeat is expected only as an idle keepalive, about every 10 seconds when GV2 has not sent a state change, JPEG frame, or error frame.

The JPEG header contains the best detection box from the GV2 inference result as `x,y,w,h` coordinates. The length is the trimmed JPEG payload length through the real `FFD9` marker. CRC32 is computed over exactly those JPEG bytes. The receiver prints completion output only after all `jpeg_len_u32_le` payload bytes are received, the CRC matches, and the configured inference filter has been evaluated.

## Receive State Machine

| State | Responsibility |
| --- | --- |
| Magic scan | Wait for `VSTS`, `VSTH`, `VSTE`, or `VSTJ` |
| State frame | Read one state byte and update diagnostics |
| Heartbeat frame | Read status and counter so health checks can distinguish "GV2 alive, no JPEG yet" from a dead camera path |
| JPEG header | Read state, class, confidence, bounding box, payload length, and CRC32 |
| JPEG payload | Read exactly the declared JPEG bytes into RAM, validate CRC32/JPEG structure, update the detection occurrence count, actuate and save only on a configured detection match, and append `/frames.log` |

The parser continuously scans for magic bytes when idle, so it can resynchronize after noise or a discarded invalid frame.

## Validation

Before saving an image, the firmware checks:

- The binary frame has a valid non-zero JPEG length.
- The declared length does not exceed the receiver maximum.
- CRC32 over the received JPEG bytes matches the sender header.
- Inference confidence is equal to or greater than `inference.confidence_threshold`.
- Inference class equals `inference.detected_class`, unless the configured class is `-1`.
- The class/confidence filter has matched for `inference.occurrence` valid frames within `inference.occurrence_window_seconds`.
- SD card availability.

Invalid frames and non-matching detections are logged but not saved. Once the configured occurrence count is reached inside the configured time window, the receiver runs the configured stepper actuator cycle first, flushes and resynchronizes the GV2 UART stream after the blocking actuator cycle, then saves the triggering JPEG. The detection occurrence counter is reset after a completed actuator event so a fresh set of matches is required before the next cycle.

## SD Card Output

The firmware writes:

```text
/config.json
/post.log
/frames.log
/power.log
/health.log
/log/archive/<YYYYMMDD>/*.jsonl
/vvel_0.859_20260716_225523_000004.jpg
```

`/config.json` is created with default future settings if it does not exist yet. `/post.log` is overwritten at boot and includes the software version from `firmware/src/version.h`. `/frames.log`, `/health.log`, and `/power.log` are appended as JSON Lines and rotated into `/log/archive/<YYYYMMDD>/` according to the logging policy. JPEG filenames include the configured class short name, confidence, known system timestamp, and local receive counter. If system time is not available, the firmware falls back to an uptime-based name.

The repository includes `config.example.json` as a clean, human-readable baseline for validating SD card configs. It intentionally contains no comment helper fields and no legacy GV2 reset settings.

Each `/frames.log` line records timestamp, GNSS coordinates, inference state/class/confidence, configured inference filter, occurrence count, detection match result, bounding box, JPEG length, CRC, saved filename, current actuator settings, actuator activation result, device name, CPU make/model, and software version.

The stepper settings currently used are:

```json
{
  "stepper": {
    "speed_steps_per_second": 400,
    "rotation_degrees": 90,
    "steps_per_revolution": 2048,
    "reverse_wait_ms": 1000,
    "start_direction": "cw",
    "post_test_enabled": true
  },
  "inference": {
    "confidence_threshold": 0.745,
    "doubtful_confidence_threshold": 0.70,
    "upload_doubtful_to_azure": true,
    "detected_class": 3,
    "occurrence": 2,
    "occurrence_window_seconds": 5
  }
}
```

UART pins can also be changed without rebuilding:

```json
{
  "uart": {
    "rx_gpio": 16,
    "tx_gpio": 17,
    "baud": 921600
  }
}
```

GV2 power switching is controlled at build time with `GV2_POWER_GPIO_CFG`, defaulting to GPIO 43 in `firmware/platformio.ini`. The pin is driven HIGH during boot/wake before the GV2 UART starts, and driven LOW immediately before deep sleep after the UART is stopped and its RX/TX pins are set to input/high-Z.

The modem mode controls how much of the SIM7080 is required for health:

```json
{
  "modem": {
    "mode": 2,
    "apn": "onomondo",
    "apn_autodetect": true,
    "apn_test_all": false,
    "operator_auto_select": false,
    "apn_candidates": [
      { "supplier": "Onomondo", "apn": "onomondo" },
      { "supplier": "KPNThings", "apn": "internet.m2m" },
      { "supplier": "Wireless Logic Benelux", "apn": "" },
      { "supplier": "ThingsData/Tele2 2G-4G", "apn": "m2m.tele2.com" },
      { "supplier": "ThingsData/Tele2 5G", "apn": "iot.tele2.com" }
    ],
    "lookup_primary": "1.1.1.1",
    "lookup_secondary": "8.8.8.8"
  }
}
```

| `modem.mode` | Behavior |
| --- | --- |
| `0` | No modem/SIM expected. Modem init, modem time, LTE-M validation, and GNSS probing through the modem are skipped. Modem health is ignored. |
| `1` | Time-only modem mode. The modem must answer AT commands, register on the network, provide valid `AT+CCLK?` time, and set system time. LTE-M bearer validation is skipped. |
| `2` | LTE-M validation mode. The modem must answer AT commands, register, attach with the configured APN, and obtain a bearer IP address. Modem time and GNSS probing are also attempted. |

When `apn_autodetect` is `true`, mode `2` tries each non-empty `apn_candidates` entry until LTE-M bearer/IP validation succeeds. By default validation stops at bearer/IP because SIM7080 TLS response timing is too variable for a reliable POST egress check. Set `validate_http_egress` to `true` only during modem diagnostics if a TinyGSM TLS connection to KPN Things should also be attempted. Each APN attempt is printed to serial and appended to `/health.log` as `modem_apn_probe` JSON Lines. The selected APN is kept in RAM as `modem.apn` for later health retries. Leave a supplier APN empty when it is not known yet; the firmware logs that candidate as skipped.

Set `apn_test_all` to `true` during supplier comparison tests to continue through every configured APN even after one APN passes. The first passing APN remains selected for later health retries.

For SIM supplier testing, use a longer `time.network_timeout_seconds` value such as `60` so roaming SIMs have enough time to leave `searching` registration states like `+CEREG: 2,2` before APN attach is declared failed.

When a positive detection match is saved to SD, the firmware can immediately upload that saved JPEG to Azure Blob Storage using the credentials compiled in `firmware/src/config_secrets.h`. During the upload it pauses the GV2 UART, wakes or reconnects the SIM7080 data bearer as needed, performs an HTTPS PUT, then resumes GV2 UART reception and applies `azure.cooldown_minutes`. Failed uploads apply `azure.failure_cooldown_seconds`. Set `azure.cooldown_minutes` high enough to avoid repeated modem wake/upload cycles during dense detections.

Doubtful frames, with confidence between `inference.doubtful_confidence_threshold` and `inference.confidence_threshold`, can also be saved and uploaded when `inference.upload_doubtful_to_azure` is true. They do not trigger the actuator unless they also satisfy the positive detection filter and occurrence count.

`time.allow_gnss_fallback=true` lets mode `1` or `2` try GNSS time when modem network time is unavailable. GNSS time is only trusted from a valid GNSS position fix or from a plausible UTC value that advances during the probe.

The web service is enabled as an access point by default. `mode` is `0` off, `1` WiFi station, or `2` access point:

```json
{
  "web": {
    "mode": 2,
    "ssid": "VST-BASE",
    "password": "",
    "append_mac": true
  }
}
```

Power telemetry is logged to `/power.log`. The interval is configured in seconds and also controls the heartbeat cadence:

```json
{
  "power": {
    "log_interval_seconds": 900,
    "deep_sleep": 2,
    "deep_sleep_start_hour": 18,
    "deep_sleep_end_hour": 6,
    "low_battery_sleep_percent": 10,
    "low_battery_wake_interval_minutes": 60,
    "reboot_cron": "0 12 * * *",
    "reboot_after_deep_sleep_wakeup": false
  },
  "health": {
    "led": 1
  },
  "azure": {
    "cooldown_minutes": 15,
    "failure_cooldown_seconds": 120,
    "runtime_connect_timeout_seconds": 20,
    "photos_prefix": "photos",
    "logs_prefix": "logs",
    "log_post_test_enabled": true
  }
}
```

`health.led` is `1` to blink the status LED with the health state while USB/VBUS power is present, or `0` to keep that runtime health blink off. The same status LED is driven on while the configured actuator cycle is running in any power mode.

`deep_sleep` is a mode value:

| Mode | Behavior |
| --- | --- |
| `0` | Deep sleep disabled |
| `1` | Sleep during the configured local-time window |
| `2` | Sleep during the configured local-time window only when running from battery |

Mode `2` requires the PMU to report that a battery is present, the battery is discharging, and no external VBUS input is detected. This is intended for overnight saving while still keeping the unit awake when 5V or solar input is available. The default window is `18:00-06:00`, so after a valid modem or GNSS time sync, a unit booting during the night can go back to sleep immediately when the mode allows it. Before sleeping, the firmware logs a `deep_sleep_enter` event to `/power.log`, stops the GV2 UART, drives the GV2 power-control signal on GPIO 43 LOW, shuts down GNSS/modem rails where possible, and arms the ESP32 timer wakeup.

Low-battery protection is independent of the night window. When a battery is present, no mains/VBUS input is detected, and `battery_percent` is less than or equal to `power.low_battery_sleep_percent`, the firmware enters deep sleep for `power.low_battery_wake_interval_minutes`. This check runs immediately after SD config and PMU init, before modem, web, stepper, or GV2 startup work, and it also runs during normal runtime. The default policy is to sleep at `10%` or lower and wake every `60` minutes to check whether solar charging has recovered the battery enough to continue. If the unit is already inside the programmed sleep window, or if the next low-battery check would land inside that window, the sleep is extended to the configured wake hour instead of doing hourly wakeups overnight.

`power.reboot_cron` is a five-field cron-like schedule checked once per loop minute after valid system time is available. It supports `*`, single values, comma lists, ranges, and `*/step`. For example, `"0 12 * * *"` reboots daily at noon. Leave it empty to disable scheduled reboot. `power.reboot_after_deep_sleep_wakeup=true` performs one immediate restart after waking from a firmware-entered deep sleep, then clears the RTC marker to avoid a reboot loop.

Rotated log uploads are controlled separately by `logging.upload_enabled`, `logging.upload_interval_minutes`, `logging.upload_max_files_per_run`, and `logging.upload_min_battery_percent`. They use `azure.logs_prefix` and delete local archive files after a successful upload. Each upload run first tries to upload one `frames`, one `health`, and one `power` archive before using remaining slots for the oldest pending archives.

During POST, missing `/config.json` fields are added back to the SD card from `config.example.json` without overwriting existing values. Existing values and extra user fields are preserved.

When enabled, open the IP printed as `WEB: ... ip=...` in the serial monitor. The page polls `/state.json` for inference metadata and fetches `/frame.jpg` only when a new verified frame id arrives, keeping the display path binary JPEG instead of base64. CRC-bad or structurally invalid JPEGs are logged but do not replace the last good web frame.

The default `steps_per_revolution` is `2048` for a 28BYJ-48 in full-step mode. `stepper.start_direction` accepts `clockwise`/`cw` or `anti-clockwise`/`ccw` and controls the first rotation of each POST or detection actuator cycle; the return rotation always runs in the opposite direction by the same amount. `inference.confidence_threshold` is a `0.0` to `1.0` threshold, `inference.detected_class` is the target class index, `inference.occurrence` is the number of matching detections required, and `inference.occurrence_window_seconds` is the time window for those matches. Use `-1` for `detected_class` to accept any class.

## Build And Flash

```powershell
cd firmware
.\run.ps1
```

`run.ps1` uploads to COM5 by default, then opens the serial monitor on COM5 at 115200 baud unless different ports are passed:

```powershell
.\run.ps1 -UploadPort COM5 -MonitorPort COM5
```

## Source Files

| File | Responsibility |
| --- | --- |
| `firmware/src/main.cpp` | POST reporting, setup orchestration, heartbeat |
| `firmware/src/modem.cpp` | AXP2101 rails, SIM7080 AT readiness, network time, GNSS probe |
| `firmware/src/modem.h` | Modem API and GNSS data structure |
| `firmware/src/sdcard.cpp` | SD-MMC custom pin setup, `/config.json`, `/post.log`, JPEG writing |
| `firmware/src/sdcard.h` | SD card API |
| `firmware/src/stepper.cpp` | TB6612FNG full-step actuator drive using config speed/rotation |
| `firmware/src/stepper.h` | Stepper API |
| `firmware/src/uart.cpp` | GV2 power control, Serial2 binary `VSTS`/`VSTJ` receiver, and JPEG streaming |
| `firmware/src/uart.h` | GV2 power/UART API and receive statistics |
| `firmware/src/web.cpp` | WiFi HTTP service serving latest JPEG, overlay page, and inference JSON |
| `firmware/src/web.h` | Web service API and published frame metadata |
| `firmware/src/version.h` | Software name and version used in POST and frame logs |
| `firmware/platformio.ini` | ESP32-S3 build, serial ports, PSRAM, 16 MB flash, dependencies |
| `firmware/huge_app.csv` | Partition table |

## Dependencies

- Arduino ESP32 core
- TinyGSM for SIM7080 AT support
- XPowersLib for AXP2101 PMU control
- SD_MMC from the ESP32 Arduino core
- WiFi and WebServer from the ESP32 Arduino core
- ArduinoJson for `/config.json`
- ESP-IDF helpers through the Arduino build

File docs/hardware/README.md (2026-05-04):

## 📝 README: AXP2101 PMIC Troubleshooting & Final Required Settings (ESP-IDF)

This document summarizes the final, working configuration settings and critical code adjustments needed to reliably initialize the **AXP2101 Power Management IC (PMIC)** on the **LILYGO T-SIM7080G-S3** board, enabling both the SD card and the Camera.

The minimal working code successfully loads the model from the SD card, unmounts it, and then initializes the camera for capture.

---

## 📌 1. Required ESP32-S3 GPIO Pin Definitions

The following GPIOs are required for I2C communication with the AXP2101 PMIC and the standard 1-bit SDMMC interface.

| Peripheral | Function | GPIO Pin | Constant | Notes |
| :--- | :--- | :--- | :--- | :--- |
| **PMIC (AXP2101)** | I2C Data (SDA) | **GPIO15** | `I2C_MASTER_SDA_IO` | Used for configuring AXP2101. |
| | I2C Clock (SCL) | **GPIO7** | `I2C_MASTER_SCL_IO` | Used for configuring AXP2101. |
| **SD Card** | Command (CMD) | **GPIO39** | `SDMMC_CMD_GPIO` | **Shared with Camera D5.** Requires unmount/reset before camera init. |
| | Clock (CLK) | **GPIO38** | `SDMMC_CLK_GPIO` | |
| | Data 0 (D0) | **GPIO40** | `SDMMC_D0_GPIO` | |

---

## ⚡ 2. AXP2101 PMIC Rail Settings (AXP2101 Register Map)

The following table details the necessary voltage and control register values programmed into the AXP2101 to support the ESP32-S3, SD card, and OV Camera.

| Rail | Purpose | Voltage Setting | AXP2101 Register | Value Written | Register Address (Hex) |
| :--- | :--- | :--- | :--- | :--- | :--- |
| **DCDC1** | **System/VBUS ($3.3\text{V}$)** | **$3.30\text{V}$** | `DCDC1_VSET` | `0x39` | `0x80` |
| **DCDC3** | **SD Card VCC** | **$3.40\text{V}$** | `DCDC3_VSET` | `0x2A` | `0x82` |
| **ALDO1** | **Camera Core** | **$1.80\text{V}$** | `ALDO1_VSET` | `0x0D` | `0x92` |
| **ALDO2** | **Camera I/O** | **$2.80\text{V}$** | `ALDO2_VSET` | `0x17` | `0x93` |
| **ALDO4** | **Camera Analog** | **$3.00\text{V}$** | `ALDO4_VSET` | `0x19` | `0x95` |
| **Enable All** | Global Control | N/A | `LDO_EN_CTRL` | **`0xFF`** | `0x90` |
| **DCDC Enable** | DCDC Control | N/A | `DCDC_EN_CTRL` | **`0x07`** (DCDC1,2,3 ON) | `0x21` |

### Key Voltage Differences (The Fixes)

* **SD Card (DCDC3):** Explicitly set to **$3.4\text{V}$** (`0x2A`) to ensure the SD card receives stable operating voltage, preventing the previous issue where it ran at the default, non-functional $0.9\text{V}$.
* **Camera Rails (ALDOs):** Explicitly set to $1.8\text{V}$, $2.8\text{V}$, and $3.0\text{V}$ to provide the exact voltage levels required by the OV camera sensor (e.g., OV2640).

---

## ⏱️ 3. Required Timing and Delay Settings

Proper timing is crucial for I2C stability and power rail stabilization.

| Action | Delay Value (ms) | Code Context | Rationale |
| :--- | :--- | :--- | :--- |
| **Post-Register Write** | **$5\text{ms}$** | `vTaskDelay(pdMS_TO_TICKS(5));` inside `axp2101_write_reg()` | Prevents I2C transaction errors and gives the PMIC internal logic time to execute the command. |
| **Post-Rail Setup** | **$100\text{ms}$** | `vTaskDelay(pdMS_TO_TICKS(100));` | Allows the DCDC3/SD card power rail to fully stabilize before SDMMC initialization begins. |
| **After SD Unmount** | **$100\text{ms}$** | `vTaskDelay(pdMS_TO_TICKS(100));` | Allows the system to release the SDMMC peripherals, including the shared GPIO39, before camera initialization. |

---

## 🧠 4. Summary of Lessons Learned

| Key Lesson | Description |
| :--- | :--- |
| **Register Map:** | Must use the **correct AXP2101 datasheet register addresses** (e.g., DCDC1 voltage is `0x80`), as they differ from derived or older PMIC libraries. |
| **I2C Stability:** | An aggressive **$5\text{ms}$ delay after every I2C write** is mandatory for stability on this hardware platform. |
| **Explicit Enable:** | Voltage registers must be written **first**, followed by explicit writes to the LDO Enable (`0x90`) and DCDC Enable (`0x21`) registers to bring the rails online. |
| **Hardware Conflict:** | The program successfully loads the model from the SD card and then uses the camera. If GPIO39 is shared (CMD/D5), the **SD card must be explicitly unmounted and its GPIO reset** before the camera is initialized. |

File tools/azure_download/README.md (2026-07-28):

# T-SIM Azure Downloader

Downloads T-SIM uploads from Azure Blob Storage using AzCopy and the local
firmware secrets in `t-sim/firmware/src/config_secrets.h`.

By default it downloads the active firmware prefixes:

- `photos`
- `logs`

Already downloaded files are not fetched again unless the Azure blob has a newer
timestamp. This is handled by AzCopy with `--overwrite=ifSourceNewer`.

## Usage

From the repo root:

```powershell
python .\tools\azure_download\download_azure_blobs.py
```

Dry run:

```powershell
python .\tools\azure_download\download_azure_blobs.py --dry-run
```

Download only one prefix:

```powershell
python .\tools\azure_download\download_azure_blobs.py --prefix photos
```

Download everything in the container:

```powershell
python .\tools\azure_download\download_azure_blobs.py --all
```

The default local output folder is `tools/azure_download/downloads/`.

## Analyze

Summarize downloaded logs and photos:

```powershell
python .\tools\azure_download\analyze_downloads.py
```

Plot confidence over time with simulated detection events:

```powershell
python .\tools\azure_download\plot_detection_timeline.py --threshold 0.70 --occurrence 2 --window-seconds 5
```

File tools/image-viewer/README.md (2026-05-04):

# Image Viewer Tool

Random desktop image viewer for quick visual checks of datasets and field captures.

By default it scans `tools/image-viewer/images`.

```powershell
pip install -r requirements.txt
.\run.ps1
```

Custom base folder:

```powershell
python .\random_viewer.py --base C:\path\to\images --seconds 5
```

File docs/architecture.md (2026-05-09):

# Architecture

VST-BASE is organized around the T-SIM7080G-S3 base unit. Grove Vision AI V2 is a stick-on vision module connected through the custom PCB.

```text
T-SIM7080G-S3
  - UART receive path
  - SD logging
  - modem network time
  - GNSS
  - future uplink

Custom PCB
  - T-SIM7080G-S3 interface
  - GV2 XIAO-slot style connector
  - D0 / GPIO03 exposed as the actuator-active output
  - D1 / GPIO46 exposed as a reserved input-only line
  - optional motor / actuator hardware references

Grove Vision AI V2 stick-on module
  - camera
  - YOLO11 model
  - inference metadata / image output
```

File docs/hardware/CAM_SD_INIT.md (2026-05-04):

## Camera + SD Card Initialization (ESP32-S3 / LILYGO T-SIM7080G-S3)

### Camera (OV2640) – Critical Settings
- **Peripheral**: I2S_CAM (independent from SDMMC)
- **Pixel format**: JPEG  
- **Frame size**: QVGA (320×240)  
- **JPEG quality**: 10  
- **Frame buffers**: 1 (prevents DMA/PSRAM pressure)
- **Frame buffer location**: PSRAM  
- **XCLK**: 20 MHz  
- **Grab mode**: `CAMERA_GRAB_WHEN_EMPTY`
- **I2C (SCCB)**: Port 1
- **Reset sequence**:
  - Hardware reset via RESET pin
  - Software reset / wakeup (OV2640 DSP PWDN toggle)
- **Power rails (AXP2101)**:
  - ALDO1: 1.8 V (core)
  - ALDO2: 2.8 V (I/O)
  - ALDO4: 3.0 V (analog)

### SD Card – Critical Settings
- **Interface**: SDMMC (native, not SPI)
- **Bus width**: 1-bit (maximum pin compatibility)
- **Pins**:
  - CMD → GPIO39
  - CLK → GPIO38
  - D0  → GPIO40
- **Slot flags**: `SDMMC_SLOT_FLAG_INTERNAL_PULLUP`
- **Host flags**: `SDMMC_HOST_FLAG_1BIT` (OR’ed with defaults)
- **Mount point**: `/sdcard`
- **Filesystem**: FATFS
- **Long File Names (LFN)**: Enabled (heap-based, max 255)
- **External RAM**: Preferred for FATFS buffers

### Concurrency Model
- **Camera capture**: Dedicated FreeRTOS task
- **SD writes**: Separate FreeRTOS task
- **Buffer handoff**: Queue of `camera_fb_t*`
- **DMA isolation**:
  - Camera → I2S_CAM → PSRAM
  - SD → SDMMC → separate DMA engine

### Key Design Constraints (Why This Works)
- No GPIO overlap between camera and SD
- ESP32-S3 allows GPIO39 as SD CMD (not input-only)
- SDMMC + Camera use independent peripherals
- PSRAM prevents internal RAM exhaustion
- 1-bit SD avoids pin and timing conflicts

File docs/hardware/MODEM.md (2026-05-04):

# Modem Power-Up, Initialization & Timestamp Collection

This document describes, step by step, how the cellular modem is powered, initialized, brought online, and used to obtain a reliable timestamp in this project.  
It is intended as a concise technical reference for maintainers and reviewers.

---

## 1. Modem Power-Up (PMIC stage)

The modem is powered **before any UART or AT communication** via the **AXP2101 PMIC**.

Key points:

- Power rails for the modem and GPS are enabled by the PMIC:
  - `DCDC3` → Modem / GNSS (3.0 V)
  - `BLDO2` → Modem I/O (3.3 V)
- All voltages are explicitly verified by reading back PMIC registers.
- Power-good is confirmed *before* continuing.

This ensures:
- The modem never sees UART traffic while unpowered
- Brown-out and partial boot states are avoided

---

## 2. UART Initialization (`modem_init_uart()`)

Once power is stable, the modem UART is initialized.

Configuration:
- UART: `UART_NUM_1`
- Baud rate: `115200`
- Data format: `8N1`
- Flow control: disabled
- RX/TX pins: fixed board wiring

The UART driver is installed with sufficiently large RX/TX buffers to handle bursty AT responses.

No AT commands are sent at this stage.

---

## 3. Modem Readiness Check (`wait_for_modem()`)

The system waits until the modem is responsive at the AT level.

Process:
1. Periodically send `AT`
2. Wait for a clean `OK` response
3. Retry until timeout (30 s)

Once the modem responds:
- Network time updates are enabled:
  - `AT+CLTS=1` (network time sync)
  - `AT+CTZR=1` (timezone reporting)

This confirms:
- The modem firmware is running
- UART communication is reliable

---

## 4. Network Registration Wait

After AT readiness, the modem is **not yet trusted for time**.

The system explicitly waits for cellular registration:

- `AT+CEREG?` (LTE registration)
- `AT+CREG?`  (CS fallback)

Accepted states:
- `,1` → Registered (home)
- `,5` → Registered (roaming)

This step is critical because:
- Network time (NITZ) is only provided after registration
- The modem RTC often contains invalid default dates at boot

---

## 5. Timestamp Collection (`modem_get_timestamp()`)

The modem clock is queried using:

```text
AT+CCLK?

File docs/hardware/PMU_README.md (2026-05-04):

# ⚡ AXP2101 PMIC Configuration for LILYGO_ESP32S3_CAM_SIM7080G (Updated)

This document details the critical register settings, voltage configurations, and sequencing logic for the AXP2101 Power Management IC (PMIC) used on the LilyGO T-Camera S3/SIM7080G platform.

The primary goal is to provide the correct power rails for the ESP32-S3, the OV2640 camera module, and the SIM7080G cellular/GPS modem.

## 1. ⚙️ Hardware & I2C Interface

| Parameter | Value | Notes |
| :--- | :--- | :--- |
| **PMIC Chip** | AXP2101 (X-Powers) | Used for multi-rail power management. |
| **I2C Address** | `0x34` (7-bit) | Standard slave address for AXP2101. |
| **I2C Port** | `I2C_NUM_0` | ESP32-S3 I2C peripheral port. |
| **SDA Pin** | `GPIO_15` | I2C Data line. |
| **SCL Pin** | `GPIO_7` | I2C Clock line. |
| **Clock Freq** | `400 kHz` | Standard Fast-mode I2C frequency. |
| **Timing** | `vTaskDelay(pdMS_TO_TICKS(5));` | Mandatory 5ms delay after I2C write for PMIC stability. |
| **Stabilization** | `vTaskDelay(pdMS_TO_TICKS(100));` | 100ms delay after all rails enabled for system stability. |

## 2. ⚡ Power Rail Requirements & Settings

This table maps the required voltages to their corresponding AXP2101 register addresses and the final hexadecimal write value (`VSET`). **These settings are validated by the diagnostic log.**

| Rail Name | Register (Addr) | Target Voltage | Type | Description / Load | **VSET Value (Hex)** | VSET (Decimal) |
| :--- | :---: | :---: | :---: | :--- | :---: | :---: |
| **DCDC1** | `0x82` | **3.30V** | DCDC | ESP32-S3 Core/Main Power | `0x12` | 18 |
| **DCDC3** | `0x84` | **3.00V** | DCDC | **SIM7080G Modem/GPS VCC** (Verified working) | `0x66` | 102 |
| **ALDO1** | `0x92` | **1.80V** | LDO | Camera (OV2640) DVDD Core | `0x0D` | 13 |
| **ALDO2** | `0x93` | **2.80V** | LDO | Camera (OV2640) I/O | `0x17` | 23 |
| **ALDO3** | `0x94` | **3.30V** | LDO | SD Card Power | `0x1C` | 28 |
| **ALDO4** | `0x95` | **3.00V** | LDO | Camera (OV2640) AVDD Analog | `0x19` | 25 |
| **BLDO1** | `0x96` | **1.80V** | LDO | Level Shifter/External IO | `0x0D` | 13 |
| **BLDO2** | `0x97` | **3.30V** | LDO | **Modem/GPS Peripherals** (Verified working) | `0x1C` | 28 |
| **DLDO1** | `0x99` | **3.30V** | LDO | General Purpose LDO 1 | `0x1C` | 28 |
| **DLDO2** | `0x9A` | **2.30V** | LDO | General Purpose LDO 2 | `0x12` | 18 |

### 3. 📐 Voltage Step Configuration

The register values are calculated based on the following step configurations:

| Rail Type | Voltage Range | Step Size (mV) | Base Voltage | Calculation Formula |
| :--- | :--- | :---: | :---: | :--- |
| **DCDC1** | 1.5V to 3.4V | 100 mV | 1.5V | $(V_{target} - 1.5\text{V}) / 0.1\text{V}$ |
| **DCDC3** | 1.6V to 3.4V | 100 mV | 1.6V | $(V_{target} - 1.6\text{V}) / 0.1\text{V} + \mathbf{0\text{x}58}$ |
| **LDOs** | 0.5V to 3.5V | 100 mV | 0.5V | $(V_{target} - 0.5\text{V}) / 0.1\text{V}$ |

### 4. 🛑 Master Enablement Registers

These registers control the on/off state of the power rails. Proper sequencing is crucial.

| Register (Addr) | Control | Required Value (Hex) | Enabled Outputs | Notes |
| :--- | :--- | :---: | :--- | :--- |
| `0x80` | **DCDC Enable/Status** | `0x05` | DCDC1, DCDC3 | **CRITICAL FIX:** Correct control register for DCDC Enable. **DCDC3 is Modem Power.** |
| `0x90` | **LDO (ALDO/BLDO) Enable** | `0xFF` | ALDO1-4, BLDO1-2 | Enables all ALDO/BLDO outputs. |
| `0x98` | **DLDO Enable** | `0x03` | DLDO1, DLDO2 | Only enables the two DLDOs used. |
| `0x01`, `0x48`| **Fault Clear** | `0xFF` | N/A | Clears latched faults before attempting to enable DCDCs. |

### 5. 🧑‍💻 Operational Sequence (`axp2101_init_pmic`)

The initialization function executes in a specific order to ensure stable power delivery and clear any potential latched fault conditions.

1.  **Fault Clearance:** Clear all general, power-off, and DCDC overcurrent faults (`0x01` and `0x48`).
2.  **Voltage Configuration:** Write the specific **VSET** values (from Section 2) to all 10 voltage registers (`0x82`, `0x84`, `0x92` through `0x9A`).
3.  **LDO Enable:** Enable all necessary LDO/ALDO/BLDO/DLDO outputs (`0x90` and `0x98`).
4.  **DCDC Enable (Critical Step):** Enable DCDC outputs by writing `0x05` to the master control register `0x80`. This activates DCDC1 (ESP) and DCDC3 (Modem).
5.  **Stabilization:** Wait 100ms for all rails to stabilize before the application proceeds.

### 6. ✅ Verification (`axp2101_verify_settings`)

The verification function reads back all configured registers to confirm the desired settings successfully stick.

| Check | Register (Addr) | Success Condition | Failure Implication |
| :--- | :---: | :--- | :--- |
| **Fault Status** | `0x48` (DCDC OC) | Read value must be `0x00`. | Indicates a hardware short or sustained over-current on a DCDC rail. |
| **DCDC Master** | `0x80` | Read value must be `0x05`. | Critical failure; DCDC3 (Modem) will be off, leading to "Modem failed to respond." |
| **LDO Master** | `0x90` | Read value must be `0xFF`. | Failure to enable ALDO/BLDO rails (e.g., Camera power). |
| **DLDO Master** | `0x98` | Read value must be `0x03`. | Failure to enable specific DLDO rails. |
| **Voltage Config** | `0x82`, `0x84`, `0x92-0x9A` | Read value must match the expected VSET (Hex) and calculated voltage (Volts). | Incorrect component voltage, leading to component malfunction. |

# Modem Initialization & Timestamp Retrieval  
**SIM7070 / SIM7080 / SIM7090 on ESP32-S3 with AXP2101 (Auto-Boot Design)**

This document serves as a **definitive reference** for how modem initialization and timestamp retrieval are implemented in this project, **why** it is done this way, and **what assumptions are intentionally made**.

It is written both for **future you** and for **future me**, so decisions, trade-offs, and SIMCom quirks are explicitly documented.

---

# Modem Initialization & Timestamp Retrieval  
**ESP32-S3 + SIM7070 / SIM7080 / SIM7090 (AXP2101 auto-boot boards)**

### Board Characteristics
- **ESP32-S3**
- **SIM7070 / SIM7080 / SIM7090 modem**
- **AXP2101 PMIC**
- Modem power rails:
  - `DCDC3` (3.0 V) → modem core
  - `BLDO2` (3.3 V) → modem I/O

### Critical Hardware Property
> **The modem auto-boots when power rails are enabled.**

This means:
- No manual `PWRKEY` pulse is required
- No GPIO-based modem power sequencing should be performed

### Flow

**PMIC powers modem → UART initialized → AT wake-up & autobaud → Enable network time sync → Modem ready → Timestamp retrieval**

| Step | AT Command | Purpose | Expected Response | Notes |
|-----:|---|---|---|---|
| 1 | `AT` | Wake AT parser and lock autobaud | `AT` → `OK` | Echo is normal; first successful `OK` marks modem ready |
| 2 | `AT+CLTS=1` | Enable network-provided local time (NITZ) | `AT+CLTS=1` → `OK` | Persistent setting; required for `AT+CCLK?` to work |
| 3 | `AT+CTZR=1` | Enable timezone offset reporting | `AT+CTZR=1` → `OK` | Allows `+CCLK:` to include `±ZZ` timezone |
| 4 | `AT+CCLK?` | Query modem real-time clock | `+CCLK: "YY/MM/DD,HH:MM:SS±ZZ"` → `OK` | May initially return only `OK` until RTC is synced |
| 5 | *(retry)* | Allow time for network registration | `+CCLK:` appears | Retried several times with delay if time not yet available |

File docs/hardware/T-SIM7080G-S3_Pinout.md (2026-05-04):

# T-SIM7080G-S3 Pin Layout (ESP32-S3)

| Header | Pin | GPIO | Function | Additional Notes |
|---:|----:|---|---|---|
| P1.1 | 3V3 | | Power | |
| P1.2 | GND | | Ground | |
| P1.3 | SDA | GPIO16  | U0CTS | ADC2_CH5 |
| P1.4 | SCL | GPIO17  | U1TXD | ADC2_CH6 |
| P1.5 | | GPIO18  | U1RXD | ADC2_CH7 |
| P1.6 | | GPIO08  | TOUCH08 | ADC1_CH7 |
| P1.7 | | GPIO03  | TOUCH03 | ADC1_CH2 |
| P1.8 | | GPIO46  | | |
| P1.9 |  A1 | GPIO09  | TOUCH09 / FSPIHD | ADC1_CH8 |
| P1.10  |  A2 | GPIO10  | TOUCH10 / FSPICS0| ADC1_CH9 |
| P1.11  |  A3 | GPIO11  | TOUCH11 / FSPID  | ADC1_CH10 |
| P1.12  |  A4 | GPIO12  | TOUCH12 / FSPICLK| ADC1_CH1 |
| P1.13  |  A5 | GPIO13  | TOUCH13 / FSPIQ  | ADC1_CH2 |
| P1.14  |  A6 | GPIO14  | TOUCH14 / FSPIWP | ADC1_CH3 |
| P1.15  | GND | | Ground | |
| P1.16  | DC5 | | 1.4–3.7V Input | |

| Header | Pin | GPIO | Function | Additional Notes |
|---:|----:|---|---|---|
| P2.1 | 3V3 | | Power | |
| P2.2 | 3V3 | | Power | |
| P2.3 | | GPIO01  | TOUCH01 | ADC1_CH0 |
| P2.4 | | GPIO02  | TOUCH02 | ADC1_CH1 |
| P2.5 | CLK | GPIO43  | CLK_OUT1 | |
| P2.6 | | GPIO44  | CLK_OUT2 | |
| P2.7 | | GPIO37  | FSPI_Q | |
| P2.8 | | GPIO36  | FSPI_CLK | |
| P2.9 | | GPIO35  | FSPI_D | |
| P2.10  | | GPIO00  | | |
| P2.11  | | GPIO45  | | |
| P2.12  | | GPIO48  | | |
| P2.13  | | GPIO47  | | |
| P2.14  | | GPIO21  | | |
| P2.15  | GND | | Ground | |
| P2.16  | VSYS| | 5V 0.5A Output | |

## SPI (FSPI) Mapping
| Signal | GPIO |
|---|---|
| MOSI (FSPID) | GPIO11 |
| MISO (FSPIQ) | GPIO13 |
| SCK  (FSPICLK) | GPIO12 |
| CS (FSPICS0) | GPIO10 |

## PMU (Power Management Unit)
| Signal | GPIO |
|-----|---|
| SDA | GPIO15 |
| SCL | GPIO07 |
| INT | GPIO06 |

## Camera
| Signal | GPIO |
|---|---|
| Reset | GPIO18 |
| XCLK  | GPIO08 |
| SIOD  | GPIO02 |
| SIOC  | GPIO01 |
| VSYNC | GPIO16 |
| HREF  | GPIO17 |
| PCLK  | GPIO12 |
| CMYK  | -1 |
|  Y9 | GPIO09 |
|  Y8 | GPIO10 |
|  Y7 | GPIO11 |
|  Y6 | GPIO13 |
|  Y5 | GPIO21 |
|  Y4 | GPIO48 |
|  Y3 | GPIO47 |
|  Y2 | GPIO14 |

## Modem
| Signal |  GPIO  |
|---|---|
|  PWR  | GPIO41 |
|  DTR  | GPIO42 |
|  RI | GPIO03 |
|  RXD  | GPIO04 |
|  TXD  | GPIO05 |

## SD Card
| Signal |  GPIO  |
|---|---|
|  CMD  | GPIO39 |
|  CLK  | GPIO38 |
|  DATA | GPIO40 |

## 6️⃣ Power domain

| Modem | Camera | ESP32S3 | SDCard | Level conversion |
| --- | --- | --- | --- | --- |
| DC3/BLDO2(GPS) | ALDO1/ALDO2/ALDO4 | DC1 | ALDO3  | BLDO1 |

#define PMU_I2C_SDA_GPIO GPIO_NUM_7
#define PMU_I2C_SCL_GPIO GPIO_NUM_6

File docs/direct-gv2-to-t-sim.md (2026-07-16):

# Direct GV2 To T-SIM

This project no longer uses a XIAO broker. The T-SIM7080G-S3 is the base unit, and Grove Vision AI V2 attaches as a stick-on module through the custom PCB documented in:

```text
external/t-sim-motor-shield/
```

The firmware-side receive path belongs in:

```text
t-sim/firmware/src/
```

## UART Framing

GV2 sends framed messages over UART1 to the T-SIM receiver:

```text
VSTS + state
VSTH + status + counter_u32_le
VSTJ + inference metadata + jpeg length + crc32 + jpeg payload
VSTE + error_code + detail + counter_u32_le
```

`VSTH` is an idle keepalive. The GV2 firmware sends it after roughly 10 seconds without any other GV2 UART frame.

Error frames currently use:

```text
code=3 detail=1  camera missing / sensor init failed
code=3 detail=2  camera datapath init failed
```

The T-SIM logs these as `GV2: error ...` on serial and appends a `gv2_error` JSON event to `/frames.log`.

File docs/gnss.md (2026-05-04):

# GNSS

The receiver enables GNSS with:

```text
AT+CGNSPWR=1
```

and samples position data with:

```text
AT+CGNSINF
```

POST samples for up to 10 seconds and exits early when a fix is available. No fix is a warning, not a boot failure.

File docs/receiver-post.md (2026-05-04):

# Receiver POST

The T-SIM7080G-S3 firmware performs a Power-On Self Test covering:

- CPU, flash, heap and PSRAM dimensions
- SIM7080 AT readiness
- network timestamp
- system time setup
- GNSS command path and optional position fix
- broker/GV2 UART configuration
- SD card mount
- `/post.log` overwrite on boot

The serial monitor prints one delayed POST copy so COM5 can attach after flashing.

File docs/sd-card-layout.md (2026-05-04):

# SD Card Layout

Current receiver output:

```text
/post.log              overwritten at boot
/frame_000001.jpg      future received image frames
```

`/post.log` contains the latest boot summary, modem time, GNSS status, memory dimensions and SD status.

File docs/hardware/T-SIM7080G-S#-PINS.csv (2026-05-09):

GPIO | Header | Primary Function / Label | Status | Notes
0 | P2.10 | BOOT / RESET | RESERVED | Boot/strapping pin – do not use
1 | P2.3 | TOUCH01 / ADC1_CH0 | FREE_OUTPUT | Safe GPIO output
2 | P2.4 | TOUCH02 / ADC1_CH1 | FREE_OUTPUT | Safe GPIO output
3 | P1.7 | D0 / ACTUATOR_ACTIVE | USED | Actuator active output exposed on custom PCB
4 |  | MODEM_RXD | USED | Modem UART RX
5 |  | MODEM_TXD | USED | Modem UART TX
7 |  | PMU_I2C_SCL | USED | PMU I2C
8 | P1.6 | I2C SCL (Vision AI) | USED | Locked I2C bus
9 | P1.9 | TOUCH09 / FSPIHD | FREE_OUTPUT | Safe if not used for SPI
10 | P1.10 | TOUCH10 / FSPICS0 | FREE_OUTPUT | Safe if not used for SPI
11 | P1.11 | TOUCH11 / FSPID | FREE_OUTPUT | Safe if not used for SPI
12 | P1.12 | TOUCH12 / FSPICLK | FREE_OUTPUT | Safe if not used for SPI
13 | P1.13 | TOUCH13 / FSPIQ | FREE_OUTPUT | Safe if not used for SPI
14 | P1.14 | TOUCH14 / FSPIWP | FREE_OUTPUT | Safe if not used for SPI
15 |  | PMU_I2C_SDA | USED | PMU I2C
16 | P1.3 | U0CTS / ADC2_CH5 | FREE_OUTPUT | Safe GPIO output
17 | P1.4 | BROKER_TX (UART2) | USED | High-speed UART
18 | P1.5 | BROKER_RX (UART2) | USED | High-speed UART
21 | P2.14 | GPIO | FREE_OUTPUT | Safe GPIO output
35 | P2.9 | FSPI_D | CONDITIONAL | Only if FSPI unused
36 | P2.8 | FSPI_CLK | CONDITIONAL | Only if FSPI unused
37 | P2.7 | FSPI_Q | CONDITIONAL | Only if FSPI unused
38 |  | SD_CLK | USED | SD_MMC
39 |  | SD_CMD | USED | SD_MMC
40 |  | SD_DATA | USED | SD_MMC
41 |  | MODEM_PWR | USED | Modem power control
43 | P2.5 | CLK_OUT1 | CONDITIONAL | Clock output capable
44 | P2.6 | CLK_OUT2 | CONDITIONAL | Clock output capable
45 | P2.11 | STRAP_PIN | AVOID | Strapping pin – risky for output
46 | P1.8 | D1 / INPUT_ONLY | RESERVED_INPUT | Input-only on ESP32-S3; exposed on custom PCB but not usable as driven output
47 | P2.13 | GPIO | FREE_OUTPUT | Safe GPIO output
48 | P2.12 | GPIO | FREE_OUTPUT | Safe GPIO output

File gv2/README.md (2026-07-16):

# Himax yolo11n examples for Seeed Grove Vision AI Module V2

2026-04-27: image with uart1 communication of class, conf and jpg

## VST-BASE local layout

This folder is the VST-BASE-local GV2 package. The upstream firmware tree and image generator live under `firmware/`, while the helper scripts live next to this README:

```text
build_gv2_image.ps1
flash_gv2.ps1
firmware/
```

From the VST-BASE repository root, build and flash with:

```powershell
.\gv2\build_gv2_image.ps1
.\gv2\flash_gv2.ps1 -Port COM7
```

## In short

This repo helps you get YOLO11 object detection running on the board: you can flash a ready-made image that detects hornets or build and flash your own. The [Grove Vision AI Module V2 (GV2)](https://www.kiwi-electronics.com/nl/grove-vision-ai-module-v2-20039) is a tiny onboard computer (MCU) connected to a [small camera](https://www.tinytronics.nl/en/sensors/optical/cameras-and-scanners/raspberry-pi-compatible-camera-5mp-v1.3), and it runs AI on the device; **output.img** is a ready-made software image for it that detects Yellow-legged hornets, European hornets, wasps and bees. It can be **flashed** (= copying that image onto the board) so it runs the hornet detection AI.

## Contents

- [Quick start: flash the ready-made image](#quick-start-flash-the-ready-made-image)
- [Build and flash your own YOLO11 image](#build-and-flash-your-own-yolo11-image)
- [Outline](#outline) (detailed build, flash, restore, and more)

---

## Quick start: flash the ready-made image

Use this path if you want to flash the device with a pre-built YOLO11 image and do not need to build from source.

1. **Clone this repository** and switch to the branch that provides the image:
  ```
  git clone --recursive --branch yolo11-vespa https://github.com/marcory-hub/Seeed_Grove_Vision_AI_Module_V2.git
  cd Seeed_Grove_Vision_AI_Module_V2
  ```
2. **Get the ready-made image.**
  If `we2_image_gen_local/output_case1_sec_wlcsp/output.img` is not in your clone, download it and place it there:
  - [output.img](https://github.com/marcory-hub/Seeed_Grove_Vision_AI_Module_V2/raw/yolo11-vespa/we2_image_gen_local/output_case1_sec_wlcsp/output.img)
3. **Prepare your system.**
  If the device is not recognised, install the driver (see [System Requirement](#system-requirement) below. Connect the Grove Vision AI Module V2 via USB. Install the xmodem helper (as in the original [Flash Image Update by python code](#flash-image-update-at-linux-environment-by-python-code) section):
4. **Flash the image.**
  Use the COM port assigned to your device (e.g. `/dev/ttyACM0` on Linux or `COM3` on Windows). Example (Linux/macOS):
   On Windows, use `python` and backslashes, e.g. `--file=we2_image_gen_local\output_case1_sec_wlcsp\output.img`.  
   When prompted, press the **reset** button on the module (as in the original flash section). More options (serial setup, COM port tips, minicom/teraterm) are under [How to flash the firmware?](#how-to-flash-the-firmware) and [System Requirement](#system-requirement) below.

---

## Build and flash your own YOLO11 image

If you have trained, quantized, and converted your own YOLO11n model (see instructions and Colab notebooks [here](https://github.com/marcory-hub/yolo11n-on-grove-vision-ai-v2)), ensure your `.tflite` file meets the following specifications:
- **Model Input Shape:** Use Netron to open the YOLO11n model file and check that the structure matches the following:
  YOLO11n Vespa Model (224x224, int8, Vela, no-post)
 
1. **Put your model in the model zoo.**
  Place your `.tflite` file in the appropriate folder under `model_zoo` (same path convention as in the original; see scenario [tflm_yolo11_od](https://github.com/HimaxWiseEyePlus/Seeed_Grove_Vision_AI_Module_V2/blob/main/EPII_CM55M_APP_S/app/scenario_app/tflm_yolo11_od/README.md) in the Outline table below).
2. **Build and flash.**
  Follow [How to build the firmware?](#how-to-build-the-firmware) (original section below) for your OS, then [How to flash the firmware?](#how-to-flash-the-firmware). The flash section describes the optional `--model` argument (model path and flash addresses) when burning a custom model (see original lines 247–253 Linux, 280–286 Windows).

---

# Himax examples for Seeed Grove Vision AI Module V2

## Outline

This is a repository which step by step teaches you how to build your own examples and run on Seeed Grove Vision AI Module V2.
Finally, teach you how to restore to the original factory settings and run [SenseCraft AI](https://wiki.seeedstudio.com/grove_vision_ai_v2_software_support/#-no-code-getting-started-with-sensecraft-ai-) from [Seeed Studio](https://wiki.seeedstudio.com/grove_vision_ai_v2/).

# Himax examples for Seeed Grove Vision AI Module V2

## Outline

- How to build the firmware?
  - [Build the firmware at Linux environment](https://github.com/HimaxWiseEyePlus/Seeed_Grove_Vision_AI_Module_V2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)
  - [Build the firmware at MacOS environment](https://github.com/HimaxWiseEyePlus/Seeed_Grove_Vision_AI_Module_V2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)
  - [Build the firmware at Windows environment](https://github.com/HimaxWiseEyePlus/Seeed_Grove_Vision_AI_Module_V2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)
- How to flash the firmware?
  - [System Requirement](https://github.com/HimaxWiseEyePlus/Seeed_Grove_Vision_AI_Module_V2?tab=readme-ov-file#system-requirement)
  - [Flash Image Update at Linux Environment by python code](https://github.com/HimaxWiseEyePlus/Seeed_Grove_Vision_AI_Module_V2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)
  - [Flash Image Update at Windows Environment by python code](https://github.com/HimaxWiseEyePlus/Seeed_Grove_Vision_AI_Module_V2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)
  - [Flash Image Update at Linux Environment](https://github.com/HimaxWiseEyePlus/Seeed_Grove_Vision_AI_Module_V2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)
  - [Flash Image Update at Windows Environment](https://github.com/HimaxWiseEyePlus/Seeed_Grove_Vision_AI_Module_V2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)
  - [Flash using Edge Impulse CLI tools](https://github.com/HimaxWiseEyePlus/Seeed_Grove_Vision_AI_Module_V2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)
- How to restore to the original factory settings?
  - [Linux Environment](https://github.com/HimaxWiseEyePlus/Seeed_Grove_Vision_AI_Module_V2?tab=readme-ov-file#linux-environment)
  - [Windows Environment](https://github.com/HimaxWiseEyePlus/Seeed_Grove_Vision_AI_Module_V2?tab=readme-ov-file#windows-environment)

| scenario_app | project name |
| --- | --- |
| face mesh | [tflm_fd_fm](https://github.com/HimaxWiseEyePlus/Seeed_Grove_Vision_AI_Module_V2/blob/main/EPII_CM55M_APP_S/app/scenario_app/tflm_fd_fm/README.md) |
| yolov8n object detection | [tflm_yolov8_od](https://github.com/HimaxWiseEyePlus/Seeed_Grove_Vision_AI_Module_V2/blob/main/EPII_CM55M_APP_S/app/scenario_app/tflm_yolov8_od/README.md) |
| yolov8n pose | [tflm_yolov8_pose](https://github.com/HimaxWiseEyePlus/Seeed_Grove_Vision_AI_Module_V2/blob/main/EPII_CM55M_APP_S/app/scenario_app/tflm_yolov8_pose/README.md) |
| yolov8n gender classification | [tflm_yolov8_gender_cls](https://github.com/HimaxWiseEyePlus/Seeed_Grove_Vision_AI_Module_V2/blob/main/EPII_CM55M_APP_S/app/scenario_app/tflm_yolov8_gender_cls/README.md) |
| pdm mic record | [pdm_record](https://github.com/HimaxWiseEyePlus/Seeed_Grove_Vision_AI_Module_V2/blob/main/EPII_CM55M_APP_S/app/scenario_app/pdm_record/README.md) |
| KeyWord Spotting using Transformers | [kws_pdm_record](https://github.com/HimaxWiseEyePlus/Seeed_Grove_Vision_AI_Module_V2/blob/main/EPII_CM55M_APP_S/app/scenario_app/kws_pdm_record/README.md) |
| imu read | [imu_read](https://github.com/HimaxWiseEyePlus/Seeed_Grove_Vision_AI_Module_V2/blob/main/EPII_CM55M_APP_S/app/scenario_app/imu_read/README.md) |
| peoplenet from TAO | [tflm_peoplenet](https://github.com/HimaxWiseEyePlus/Seeed_Grove_Vision_AI_Module_V2/blob/main/EPII_CM55M_APP_S/app/scenario_app/tflm_peoplenet/README.md) |
| yolo11n object detection | [tflm_yolo11_od](https://github.com/HimaxWiseEyePlus/Seeed_Grove_Vision_AI_Module_V2/blob/main/EPII_CM55M_APP_S/app/scenario_app/tflm_yolo11_od/README.md) |
| mobilenet classification converted by TinyNN | [tflm_mb_cls](https://github.com/HimaxWiseEyePlus/Seeed_Grove_Vision_AI_Module_V2/blob/main/EPII_CM55M_APP_S/app/scenario_app/tflm_mb_cls/README.md) |
| mobilenetV2 classification using ExecuTorch  | [torch_mb_cls](https://github.com/HimaxWiseEyePlus/Seeed_Grove_Vision_AI_Module_V2/blob/main/EPII_CM55M_APP_S/app/scenario_app/torch_mb_cls/README.md) |

- [How to add support for raspberry pi camera?](https://github.com/HimaxWiseEyePlus/Seeed_Grove_Vision_AI_Module_V2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)
- [How to use CMSIS-NN at the project?](https://github.com/HimaxWiseEyePlus/Seeed_Grove_Vision_AI_Module_V2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)
- [How to use CMSIS-DSP at the project?](https://github.com/HimaxWiseEyePlus/Seeed_Grove_Vision_AI_Module_V2/blob/main/EPII_CM55M_APP_S/app/scenario_app/hello_world_cmsis_dsp/README.md)
- [How to use CMSIS-CV at the project?](https://github.com/HimaxWiseEyePlus/Seeed_Grove_Vision_AI_Module_V2/blob/main/EPII_CM55M_APP_S/app/scenario_app/hello_world_cmsis_cv/README.md)
  - please clone the project by following command to download CMSIS-CV library
- How to run Edge Impulse Example: standalone inferencing using Grove Vision AI Module V2 (Himax WiseEye2)? 
  - [ei_standalone_inferencing](https://github.com/HimaxWiseEyePlus/Seeed_Grove_Vision_AI_Module_V2/tree/main/EPII_CM55M_APP_S/app/scenario_app/ei_standalone_inferencing)
  - [ei_standalone_inferencing_camera](https://github.com/HimaxWiseEyePlus/Seeed_Grove_Vision_AI_Module_V2/tree/main/EPII_CM55M_APP_S/app/scenario_app/ei_standalone_inferencing_camera)
- [FAQ](https://github.com/HimaxWiseEyePlus/Seeed_Grove_Vision_AI_Module_V2/blob/main/FAQ.md)

## How to build the firmware?

This part explains how you can build the firmware for Grove Vision AI Module V2.

### Build the firmware at Linux environment

Note: The following has been tested to work on Ubuntu 20.04 PC

- Step 1: Install the following prerequisites
- Step 2: Download Arm GNU Toolchain (arm-gnu-toolchain-13.2.rel1-x86_64-arm-none-eabi.tar.xz)
- Step 3: Extract the file
- Step 4: Add arm-gnu-toolchain-13.2.Rel1-x86_64-arm-none-eabi/bin/: to PATH  
  (hint: the path about [$HOME/arm-gnu-toolchain-13.2.Rel1-x86_64-arm-none-eabi/bin/] should set your own path, you can not just copy and paste)
- Step 5: Clone the following repository and go into Seeed_Grove_Vision_AI_Module_V2 folder
- Step 6: Compile the firmware
- Output elf file: `./obj_epii_evb_icv30_bdv10/gnu_epii_evb_WLCSP65/EPII_CM55M_gnu_epii_evb_WLCSP65_s.elf`
  alt text
- Step 7: Generate firmware image file
- Output firmware image: `./output_case1_sec_wlcsp/output.img`
  alt text

[Back to Outline](https://github.com/HimaxWiseEyePlus/Seeed_Grove_Vision_AI_Module_V2?tab=readme-ov-file#outline)

### Build the firmware at MacOS environment

Note: The steps are almost the same as the [Linux environment](https://github.com/HimaxWiseEyePlus/Seeed_Grove_Vision_AI_Module_V2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) except `Step 1` and `Step 7`.

- Step 1: 
  - You should make sure your `make` is using `GNU version make` not `BSD version make`.
      
  - If it is not `GNU make` , you should download it by following command.
  - After installation, you can access it with the command gmake to avoid conflicts with the default make.
  - So, you should create an alias in your shell configuration file (like .bash_profile or .zshrc):
- Step 7: Generate firmware image file (using `./we2_local_image_gen_macOS_arm64` for MacOS)
  [Back to Outline](https://github.com/HimaxWiseEyePlus/Seeed_Grove_Vision_AI_Module_V2?tab=readme-ov-file#outline)

### Build the firmware at Windows environment

- Step 1: Install the `make` command for prerequisites , you can reference [here](https://github.com/xpack-dev-tools/windows-build-tools-xpack/releases)
- Step 2: Download Arm GNU Toolchain [arm-gnu-toolchain-13.2.rel1-mingw-w64-i686-arm-none-eabi.zip](https://developer.arm.com/-/media/Files/downloads/gnu/13.2.rel1/binrel/arm-gnu-toolchain-13.2.rel1-mingw-w64-i686-arm-none-eabi.zip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)
- Step 3: Extract the file
- Step 4: Add arm-gnu-toolchain-13.2.rel1-mingw-w64-i686-arm-none-eabi/bin/ to your environment variables 
  - option1: add the gnu-toolchain to your environment variables manually
  - option2: add the gnu-toolchain by command
  (hint: the path about [location of your gnu-toolchain-13.2 ROOT] should set your own path, you can not just copy and paste)
- Step 5: Clone the following repository and go into Seeed_Grove_Vision_AI_Module_V2 folder
- Step 6: Compile the firmware
- Output elf file: `./obj_epii_evb_icv30_bdv10/gnu_epii_evb_WLCSP65/EPII_CM55M_gnu_epii_evb_WLCSP65_s.elf`
  alt text
- Step 7: Generate firmware image file
- Output firmware image: `./output_case1_sec_wlcsp/output.img`
  alt text

[Back to Outline](https://github.com/HimaxWiseEyePlus/Seeed_Grove_Vision_AI_Module_V2?tab=readme-ov-file#outline)

## How to flash the firmware?

This part explains how you can flash the firmware to Grove Vision AI Module V2.

### System Requirement

- Driver
  - If you find that the Grove Vision AI V2 is not recognised after connecting it to your computer, you should install the driver which can reference [here](https://wiki.seeedstudio.com/grove_vision_ai_v2/#driver).

1. Grove Vision AI Module V2
2. Connection cable
  - Micro usb cable: connect to EVB (as Power/UART)
3. Software Tools
  Serial terminal emulation application
  - In the following description, `TeraTerm` and `Minicom` will be used.
    - Serial terminal emulation application Setting
      - Baud Rate 921600 bps
      - Data        8 bit
      - Parity        none
      - Stop        1 bit
      - Flow control    none
      - please check xmodem protocol is supported.
    - Minicom (for Linux PC)
      - Install minicom command
      - Burn application to flash by using xmodem send application binary.
        - Minicom will extra install "lrzsz" package to support xmodem protocol
          alt text
        - If you did not have “lrzsz” instruction, please install by following instruction.
      - Open the permissions to access the device
          
      - Open minicom
          
      - Setup serial port and COM Port name
        alt text
        - Tips for finding the COM Port name.
          - You can use google chrome to connect to [Seeed SenseCraft AI](https://seeed-studio.github.io/SenseCraft-Web-Toolkit/#/setup/process), select `Grove Vision(V2)` and press `Connect`.
          alt text
          - Then, you would get the COM Port name.
          alt text
    - TeraTerm (for Windows PC)
      - Setup serial port 
        alt text
        alt text

[Back to Outline](https://github.com/HimaxWiseEyePlus/Seeed_Grove_Vision_AI_Module_V2?tab=readme-ov-file#outline)

### Flash Image Update at Linux Environment by python code

- Prerequisites for xmodem
  - Please install the package at [xmodem/requirements.txt](https://github.com/HimaxWiseEyePlus/Seeed_Grove_Vision_AI_Module_V2/tree/main/xmodem/requirements.txt) 
- Disconnect `Minicom`
- Make sure your `Seeed Grove Vision AI Module V2` is connect to PC.
- Open the permissions to acceess the deivce

```
sudo setfacl -m u:[USERNAME]:rw /dev/ttyUSB0
# in my case
# sudo setfacl -m u:kris:rw /dev/ttyACM0
```

alt text

- Open `Terminal` and key-in following command
- port: the COM number of your `Seeed Grove Vision AI Module V2`, for example,`/dev/ttyACM0`
- baudrate: 921600
- file: your firmware image [maximum size is 1MB]
- model(optional): you can burn multiple models "[model tflite] [position of model on flash] [offset]"
  - Position of model on flash is defined at the code [~/tflm_yolov8_od/common_config.h](https://github.com/HimaxWiseEyePlus/Seeed_Grove_Vision_AI_Module_V2/blob/main/EPII_CM55M_APP_S/app/scenario_app/tflm_yolov8_od/common_config.h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) (take [tflm_yolov8_od](https://github.com/HimaxWiseEyePlus/Seeed_Grove_Vision_AI_Module_V2/blob/main/EPII_CM55M_APP_S/app/scenario_app/tflm_yolov8_od/README.md) for example)
- It will start to burn firmware image.
  alt text
- Please press `reset` buttun on `Seeed Grove Vision AI Module V2`.
  alt text
- It will success to run the algorithm.

[Back to Outline](https://github.com/HimaxWiseEyePlus/Seeed_Grove_Vision_AI_Module_V2?tab=readme-ov-file#outline)

### Flash Image Update at Windows Environment by python code

- Prerequisites for xmodem
  - Please install the package at [xmodem/requirements.txt](https://github.com/HimaxWiseEyePlus/Seeed_Grove_Vision_AI_Module_V2/tree/main/xmodem/requirements.txt) 
- Disconnect `Tera Term`
- Make sure your `Seeed Grove Vision AI Module V2` is connect to PC.
- Open `CMD` and key-in following command
- port: the COM number of your `Seeed Grove Vision AI Module V2` 
- baudrate: 921600
- file: your firmware image [maximum size is 1MB]
- model: you can burn multiple models "[model tflite] [position of model on flash] [offset]"
  - Position of model on flash is defined at the code [~/tflm_yolov8_od/common_config.h](https://github.com/HimaxWiseEyePlus/Seeed_Grove_Vision_AI_Module_V2/blob/main/EPII_CM55M_APP_S/app/scenario_app/tflm_yolov8_od/common_config.h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) (take [tflm_yolov8_od](https://github.com/HimaxWiseEyePlus/Seeed_Grove_Vision_AI_Module_V2/blob/main/EPII_CM55M_APP_S/app/scenario_app/tflm_yolov8_od/README.md) for example)
- It will start to burn firmware image automatically.
  alt text
- Please press `reset` buttun on `Seeed Grove Vision AI Module V2`.
alt text  
- It will success to run the algorithm.

[Back to Outline](https://github.com/HimaxWiseEyePlus/Seeed_Grove_Vision_AI_Module_V2?tab=readme-ov-file#outline)

### Flash Image Update at Linux Environment

Following steps update application in the flash.

- Step 1: Open `Minicom`, setup serial port and COM Port name-> connect to Grove Vision AI Module V2. (Please reference the minicom part of [System Requirement](https://github.com/HimaxWiseEyePlus/Seeed_Grove_Vision_AI_Module_V2?tab=readme-ov-file#system-requirement))
  alt text
- Step 2: Hold down any key on the keyboard (except the Enter key) and press the reset button to reset Grove Vision AI Module V2 and the startup options will be displayed.
  alt text
- Step 3: Press button “1” and Grove Vision AI Module V2 will enter receiving mode after then.  
  alt text
- Step 4: Press `Ctrl+A` on keyboard to enter minicom menu, and then press `s` on keyboard to upload file and select `xmodem`. 
  alt text
- Step 5: Select the firmware image at `Seeed_Grove_Vision_AI_Module_V2\we2_image_gen_local\output_case1_sec_wlcsp\output.img` and press `enter` to burn. 
  alt text
- Step 6: After burning is compelete, press any key to be continue. 
  alt text
- Step 7: Then, you will see the message "Do you want to end file transmission and reboot system? (y)" is displayed. Press button `y` to restart.
  alt text
- Step 8: You will see the uart on `minicom` which is runing your algorithm.
  alt text

[Back to Outline](https://github.com/HimaxWiseEyePlus/Seeed_Grove_Vision_AI_Module_V2?tab=readme-ov-file#outline)

### Flash Image Update at Windows Environment

Following steps update application in the flash.

- Step 1: Open `TeraTerm` and select File -> New connection, connect to Grove Vision AI Module V2.
  alt text
- Step 2: Hold down any key on the keyboard (except the Enter key) and press the reset button to reset Grove Vision AI Module V2 and the startup options will be displayed.
  alt text
- Step 3: Press button “1” and Grove Vision AI Module V2 will enter receiving mode after then. Select target flash image(output.img) by File->Transfer->XMODEM->Send. 
  alt text
- Step 4: After the firmware image burning is completed, the message "Do you want to end file transmission and reboot system? (y)" is displayed. Press button `y` to restart.
  alt text
- Step 5: You will see the uart on `TeraTerm` which is runing your algorithm.
  alt text

[Back to Outline](https://github.com/HimaxWiseEyePlus/Seeed_Grove_Vision_AI_Module_V2?tab=readme-ov-file#outline)

### Flash using Edge Impulse CLI tools

This method works on all supported operating systems (Windows/Linux/MacOS...)

- Step 1: [Install the Edge Impulse CLI tools](https://docs.edgeimpulse.com/docs/tools/edge-impulse-cli/cli-installation)
- Step 2: Open any system terminal and run the following command
  ```
  himax-flash-tool -d WiseEye2 -f <path_to_four_firmware_img_file>
  ```
- Step 3: Wait until you see the following message:
  ```
  [HMX] Press **RESET** to start the application...
  [HMX] Firmware update completed
  ```

Note: if the flashing process hangs, just cancel it (Ctrl+C) and start once again.

[Back to Outline](#outline)

## How to restore to the original factory settings

### Linux Environment

- Update the flash image `Seeed_SenseCraft_AI*.img` to Grove Vision AI Module V2 and press `reset` buttun.
  alt text
- Disconnect the `Minicom`:
  - Please press `Ctrl+A` on keyboard and press `z` on keyboard to go to the menu of `minicom`.
    alt text
  - Then, press `q` on keyboard to quit with no reset `minicom`, and press `yes` to leave.
    alt text
- Open the permissions to acceess the deivce
  ```
  sudo setfacl -m u:[USERNAME]:rw /dev/ttyUSB0
  # in my case
  # sudo setfacl -m u:kris:rw /dev/ttyACM0
  ```
  
- After doing the above steps, you can run the [SenseCraft AI](https://wiki.seeedstudio.com/grove_vision_ai_v2_software_support/#-no-code-getting-started-with-sensecraft-ai-) on Grove Vision AI Module V2.
  1. Introduction : [https://wiki.seeedstudio.com/grove_vision_ai_v2/](https://wiki.seeedstudio.com/grove_vision_ai_v2/)
  2. Connect Grove Vision AI Module to NB USB port
  3. Open "Google Chrome" browser
  4. Open [SenseCraft Homepage](https://seeed-studio.github.io/SenseCraft-Web-Toolkit/#/setup/process)
  5. Select "Grove Vision AI(WE2)" and connect (serial port)
    alt text
    alt text
    alt text

[Back to Outline](https://github.com/HimaxWiseEyePlus/Seeed_Grove_Vision_AI_Module_V2?tab=readme-ov-file#outline)

### Windows Environment

- Update the flash image `Seeed_SenseCraft AI*.img` to Grove Vision AI Module V2 and press `reset` buttun.
  alt text
- Disconnect the `TeraTerm`.
  alt text
- After doing the above steps, you can run the [SenseCraft AI](https://wiki.seeedstudio.com/grove_vision_ai_v2_software_support/#-no-code-getting-started-with-sensecraft-ai-) on Grove Vision AI Module V2.
  1. Introduction : [https://wiki.seeedstudio.com/grove_vision_ai_v2/](https://wiki.seeedstudio.com/grove_vision_ai_v2/)
  2. Install CH343 UART driver (CH343SER.ZIP) (Optional)
  3. Connect Grove Vision AI Module to NB USB port
  4. Open "Microsoft Edge" browser
  5. Open [SenseCraft Homepage](https://seeed-studio.github.io/SenseCraft-Web-Toolkit/#/setup/process)
  6. Select "Grove Vision AI(WE2)" and connect (serial port)

[Back to Outline](https://github.com/HimaxWiseEyePlus/Seeed_Grove_Vision_AI_Module_V2?tab=readme-ov-file#outline)

## How to add support for raspberry pi camera?

You can reference the scenario app [allon_sensor_tflm](https://github.com/HimaxWiseEyePlus/Seeed_Grove_Vision_AI_Module_V2/tree/main/EPII_CM55M_APP_S/app/scenario_app/allon_sensor_tflm) , [allon_sensor_tflm_freertos](https://github.com/HimaxWiseEyePlus/Seeed_Grove_Vision_AI_Module_V2/tree/main/EPII_CM55M_APP_S/app/scenario_app/allon_sensor_tflm_freertos) and [tflm_fd_fm](https://github.com/HimaxWiseEyePlus/Seeed_Grove_Vision_AI_Module_V2/tree/main/EPII_CM55M_APP_S/app/scenario_app/tflm_fd_fm).
Take allon_sensor_tflm for example, you should only modify the [allon_sensor_tflm.mk](https://github.com/HimaxWiseEyePlus/Seeed_Grove_Vision_AI_Module_V2/blob/main/EPII_CM55M_APP_S/app/scenario_app/allon_sensor_tflm/allon_sensor_tflm.mk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) from cis_ov5647 to cis_imx219 or cis_imx477.

```
#CIS_SUPPORT_INAPP_MODEL = cis_ov5647
CIS_SUPPORT_INAPP_MODEL = cis_imx219
#CIS_SUPPORT_INAPP_MODEL = cis_imx477
```

So that, it can support cis_imx219 or cis_imx477 camera.

[Back to Outline](https://github.com/HimaxWiseEyePlus/Seeed_Grove_Vision_AI_Module_V2?tab=readme-ov-file#outline)

## How to use CMSIS-NN at the project?

- Modify the setting at the [makefile](https://github.com/HimaxWiseEyePlus/Seeed_Grove_Vision_AI_Module_V2/blob/main/EPII_CM55M_APP_S/makefile)
  - Enable the flag `LIB_CMSIS_NN_ENALBE` to build CMSIS-NN library 
  - You can reference the scenario app example about [allon_sensor_tflm_cmsis_nn](https://github.com/HimaxWiseEyePlus/Seeed_Grove_Vision_AI_Module_V2/tree/main/EPII_CM55M_APP_S/app/scenario_app/allon_sensor_tflm_cmsis_nn) which is the example running the model without passing vela and using the CMSIS-NN library.
    - Change the `APP_TYPE` to `allon_sensor_tflm_cmsis_nn` at the [makefile](https://github.com/HimaxWiseEyePlus/Seeed_Grove_Vision_AI_Module_V2/blob/main/EPII_CM55M_APP_S/makefile)

**YOLO11n Model Specifications:**  
- Input resolution: 224x224  
- Quantization: Vela, no_post-activation quantization applied

[Back to Outline](https://github.com/HimaxWiseEyePlus/Seeed_Grove_Vision_AI_Module_V2?tab=readme-ov-file#outline)

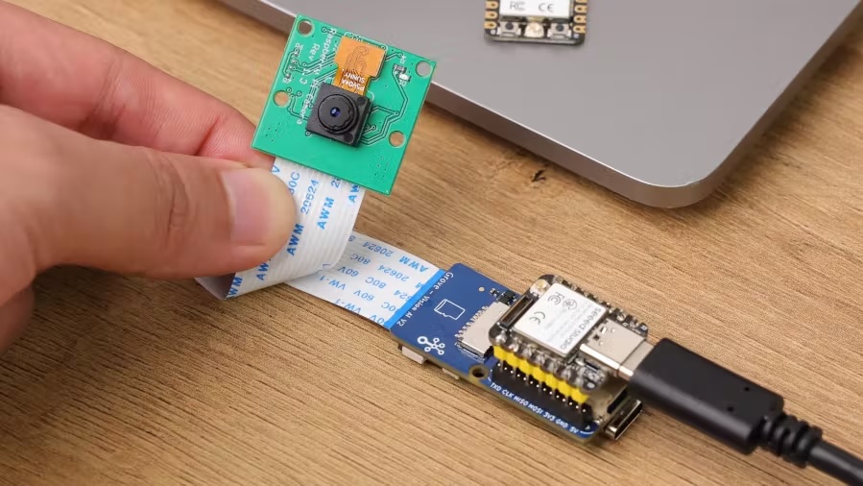
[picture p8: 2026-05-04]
docs/hardware/Grove-Vision-AI-Module-V2.jpg

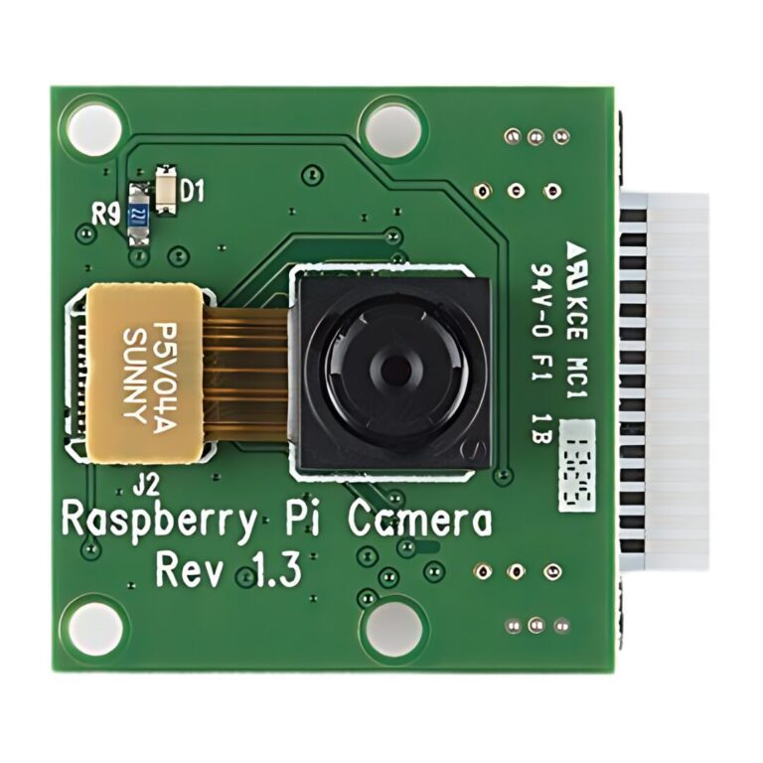
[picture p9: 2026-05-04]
docs/hardware/raspberry-pi-camera-rev-1.3.jpg

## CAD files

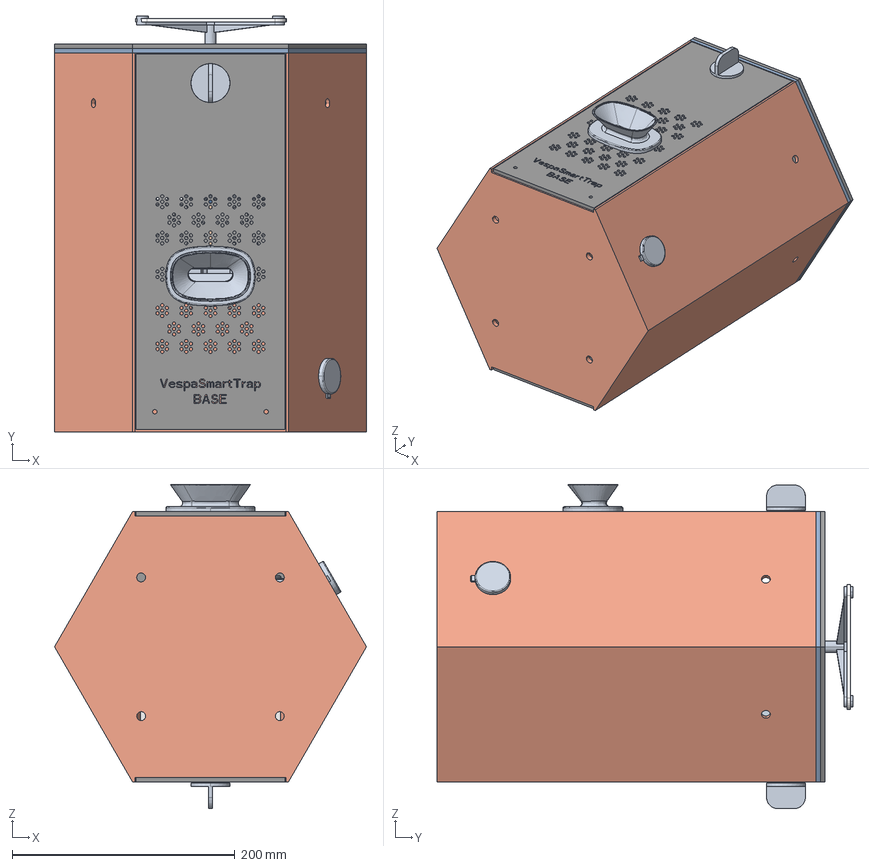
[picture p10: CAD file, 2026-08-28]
3D/ixid00000p5000_proto_asm.stp
280.0 x 373.0 x 291.0 mm
IXID00000P5011_PROTO_PANEL1
IXID00000P5013_PROTO_LOCK x 2
IXID00000P5012_PROTO_LOCK x 2
2026-06-22_CONE-ENTRANCE
IXID00000P5025_PROTO_PANEL5
IXID00000P5041_PROTO_BAIT_PANEL
SP-100-400-BOTTLE x 2
COTTON_STICK x 4
IXID00000P5041_PROTO_TRAP_PANEL
CONE_RETURN
IXID00000P5011_PROTO_PANEL3
IXID00000P5014_PROTO_PANELRIDGE
IXID00000P5021_PROTO_TOP
IXID00000P5011_PROTO_BTMFRAME
IXID00000P5012_PROTO_TOPFRAME
IXID00000P5001_PROTO_ENTRANCE
RPI_CAM_REV_1_3
MOTOR
IXID00000P5052_CASE_TOP
IXID00000P5053_CASE_BTM
MOTORADAPTER_
VERPAS_AFDICHTDOP-24-5-X-17-X-6
TULE_HV1201B-PVC-BK-N1 x 3
IXID00000P5001_PROTO_ENT_COVER
IXID00000P5001_PROTO_DOOR x 2
IXID00000P5013_PROTO_SOLARFRAME
KW-3001_SOLAR_PANEL
ROD
SWITCHPLUG
WATERPROOF_CAP

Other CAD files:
3D/260622_isoviews_pdf_dwg/ixid00000p5000_proto_1_views.dwg
3D/260622_isoviews_pdf_dwg/ixid00000p5000_proto_9_remove_front_panel.dwg
3D/260622_isoviews_pdf_dwg/ixid00000p5000_proto_6_remove_backpanel.dwg
3D/260622_isoviews_pdf_dwg/ixid00000p5000_proto_2_iso.dwg
3D/260622_isoviews_pdf_dwg/ixid00000p5000_proto_3_explode_front.dwg
3D/260622_isoviews_pdf_dwg/ixid00000p5000_proto_10_open_plug.dwg
3D/260622_isoviews_pdf_dwg/ixid00000p5000_proto_5_explain.dwg
3D/260622_isoviews_pdf_dwg/ixid00000p5000_proto_8_remove_bait.dwg
3D/260622_isoviews_pdf_dwg/ixid00000p5000_proto_7_remove_trap.dwg
3D/260622_isoviews_pdf_dwg/ixid00000p5000_proto_11_setup_check.dwg
3D/260622_isoviews_pdf_dwg/ixid00000p5000_proto_4_explode_back.dwg

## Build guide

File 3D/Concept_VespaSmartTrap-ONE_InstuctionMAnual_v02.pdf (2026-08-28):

# VespaSmartTrap-ONE

# Prototype Field Test Manual

# PLUG & PLAY AI DETECTION SYSTEM FOR VESPA VELUTINA HORNETS

Thank you for being part of the first VespaSmartTrap-ONE test group.

This prototype is an important step toward a selective, affordable and open-source smart trap for the Asian hornet. Your role is not only to test whether the device works, but also to help us understand how it behaves in real conditions: near hives, in gardens, in changing light, with changing bait, and with real insects passing through the trap.

The VST-ONE is not yet the final product. It is a test platform. Some parts may still feel technical.
Some procedures may still require manual steps. That is exactly why this test matters.

Version: Prototype Test Edition

Status: Working proof of concept

For: Selected test users, project partners and early field evaluators

Project: Vespa Smart Trap

Contact: ah-val@imkersleiden.nl

Repository: github.com/aggerritsen/ VespaSmartTrap-ONE

Copyright © 2026 Accenture & Imkers Leiden. All rights reserved.

# Manual Index

00 / Cover
VespaSmartTrap-ONE — Prototype Field Test Manual | 01

01 / Welcome to the field test
Why you are testing this prototype and how your feedback will be used | 04

02 / How the trap works
Attract / Detect / Actuate : explained with the expanded view | 04

03 / Before you start
Box contents, tools needed and safety notes | 06

04 / Setup overview
Field intelligence built into the trap — complete setup, cleaning and reset flow | 07

04.1 / Startup sequence indicators
LED behaviour, door movement and first startup check | 08

04.2 / Remove back panel
How to unlock and remove the back panel safely | 08

04.3 / Replacing the bait
Removing the bait jar, replacing cotton sticks and refilling bait fluid | 09

04.4 / Removing a trapped hornet
How to remove and inspect the trap jar safely | 10

04.5 / Remove front panel for health check
How to open the front panel for visibility and cleaning access | 10

04.6/ Setup / health check
Daily system check, reset plug procedure and door movement confirmation | 11

04.7 / Charging and data connection
Charging, firmware log access and camera/video connection | 12

04.8 / Daily test log
Daily inspection tasks and how to complete the test log sheet | 12

04.8 / Test log sheet
Daily checklist table for device status, bait, trap contents, hornets and comments | 13

04.9 / Field Notes
General observations, conditions and things noticed during testing | 14

04.10 / Feedback & ideas
User experiences, improvement ideas and suggestions for future versions | 15

05/ Questions, issues or test feedback
Contact email and GitHub repository | 16
2 | Copyright © 2026 Accenture & Imkers Leiden. All rights reserved. | Copyright © 2026 Accenture & Imkers Leiden. All rights reserved.

3

PROTOTYPE FIELD TEST MANUAL | PLUG & PLAY AI DETECTION SYSTEM FOR ASIAN HORNETS

Vespa VespaSmartTrap-ONE SmartTrap-ONE

# 01 | Welcome to the field test

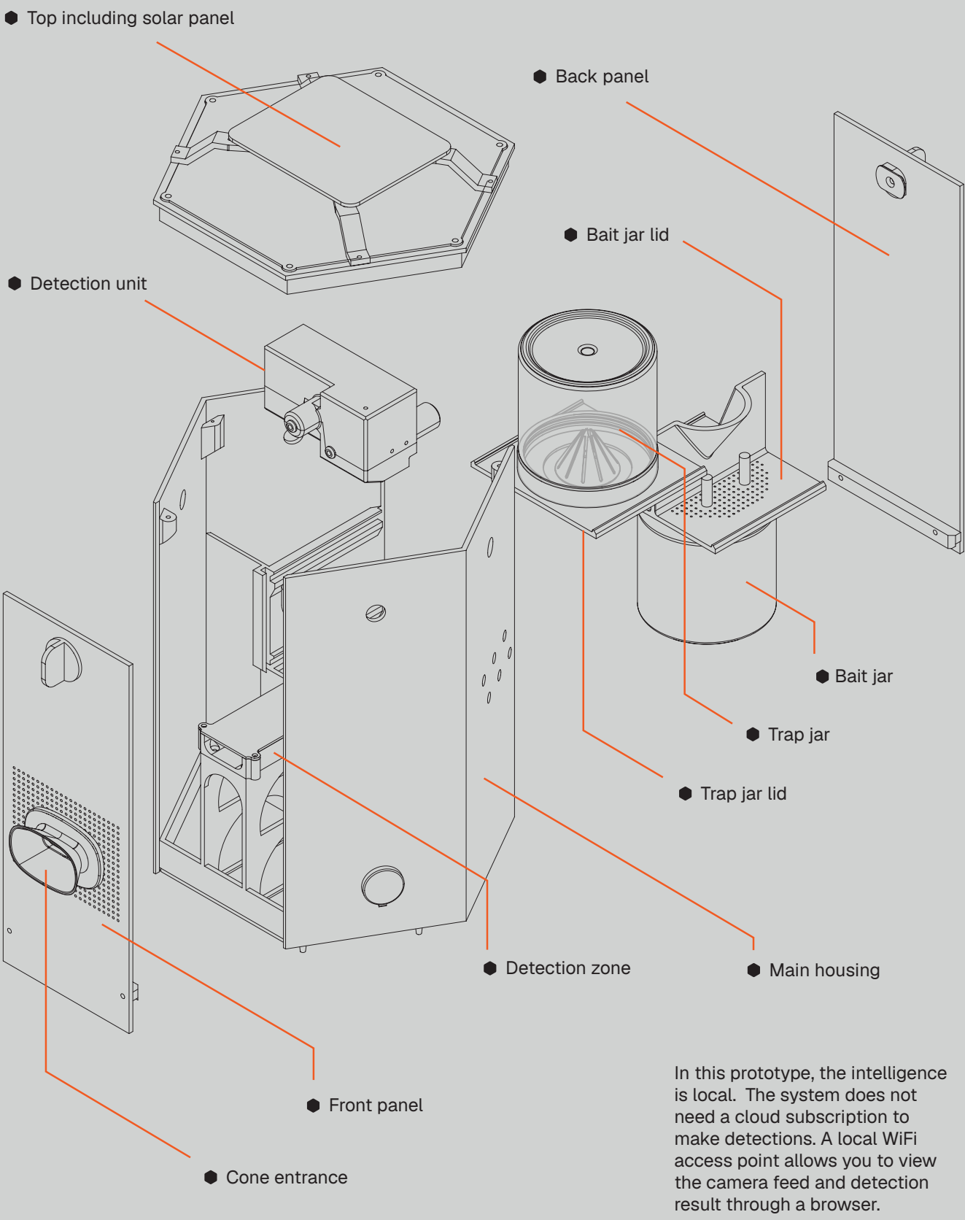
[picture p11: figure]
In this prototype, the intelligence is local. The system does not need a cloud subscription to make detections. A local WiFi access point allows you to view the camera feed and detection result through a browser.; Detection unit; Back panel; Top including solar panel; Detection zone; Main housing; Front panel; Cone entrance; Trap jar; Trap jar lid; Bait jar; Bait jar lid

# 02 | How the trap works

# Attract

# Detect

# Actuate

### Your observations will help improve:

### - the reliability of the AI detection - the physical trap design - the reset and maintenance procedure - the user instructions - the safety and usability of future versions - the open-source documentation

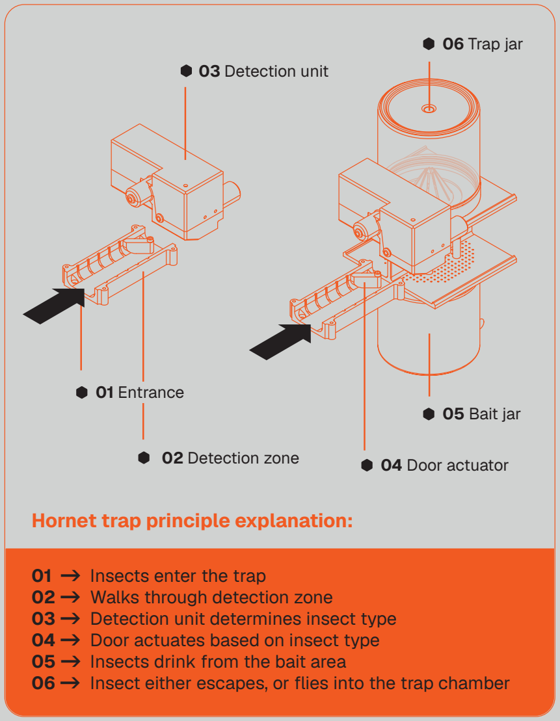
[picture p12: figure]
01 -> Insects enter the trap 02 -> Walks through detection zone; 05 -> Insects drink from the bait area; Hornet trap principle explanation:; 01 Entrance; 02 Detection zone; 03 Detection unit; 06 Trap jar; 05 Bait jar; 04 Door actuator

03 -> Detection unit determines insect type
04 -> Door actuates based on insect type

06 -> Insect either escapes, or flies into the trap chamber

The bait area attracts insects into the observation zone.

A camera observes the insect. The AI module compares the image with its trained model.

If the system recognizes the target species above the
configured confidence threshold, the controller sends a signal to the connected output.

### Three main functions:

### Main elements:

4 | Copyright © 2026 Accenture & Imkers Leiden. All rights reserved. | Copyright © 2026 Accenture & Imkers Leiden. All rights reserved. | 5

03 | Before you start | 04 | Set up overview

Field intelligence,
built into the trap.

### In the box you will find:

- VespaSmartTrap-BASE prototype trap
- USB-C power cable
- USB-C reset plug
- Premixed bait
- Test log sheet

### You will need:

- A stable outdoor location

## IMPORTANT

Do not modify wiring, firmware, or mechanical parts unless the project team asks you to. This prototype is intended to be tested as supplied.

## VespaSmartTrap-ONE uses local AI vision to recognize target species before the mechanism

responds.

## The next steps will guide you through the full process: setting up the trap, cleaning it, and

resetting it for the next use.

6 | Copyright © 2026 Accenture & Imkers Leiden. All rights reserved. | Copyright © 2026 Accenture & Imkers Leiden. All rights reserved. | 7

Slide the bait jar and lod holder outward by grabbing the plastic part (highlighted orange).

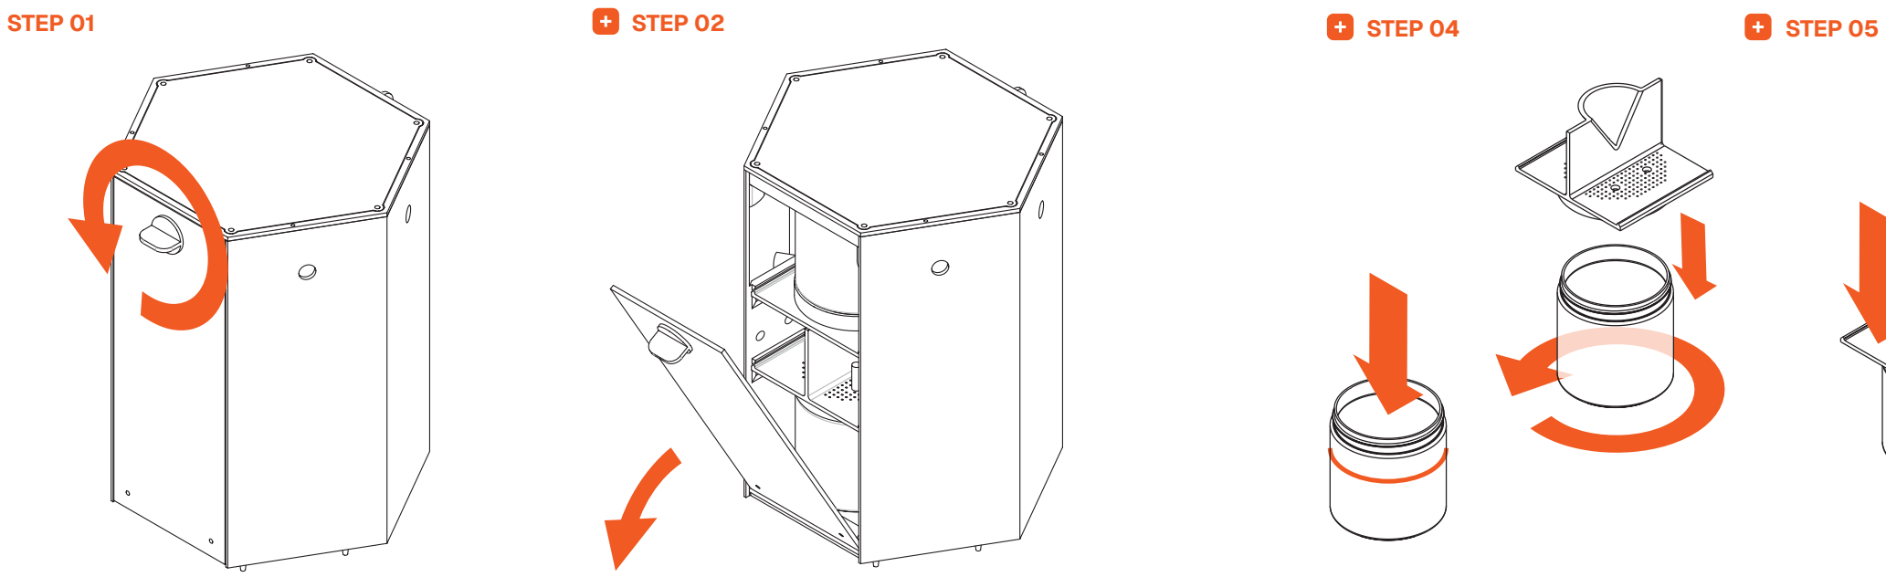
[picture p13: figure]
STEP 01 STEP 04; STEP 02 STEP 05

Fill the bait jar with provided bait fluid. Don’t exceed fill line. Twist the bait jar lid back onto the holder.

Remove the cotton sticks (4x) by sliding them upward.

Put new cotton sticks (4x) in the bait jar by sliding them through the holes.

Twist the bait jar to loosen and remove it from the holder.

Slide bait holder back into the product and close the backpanel again.

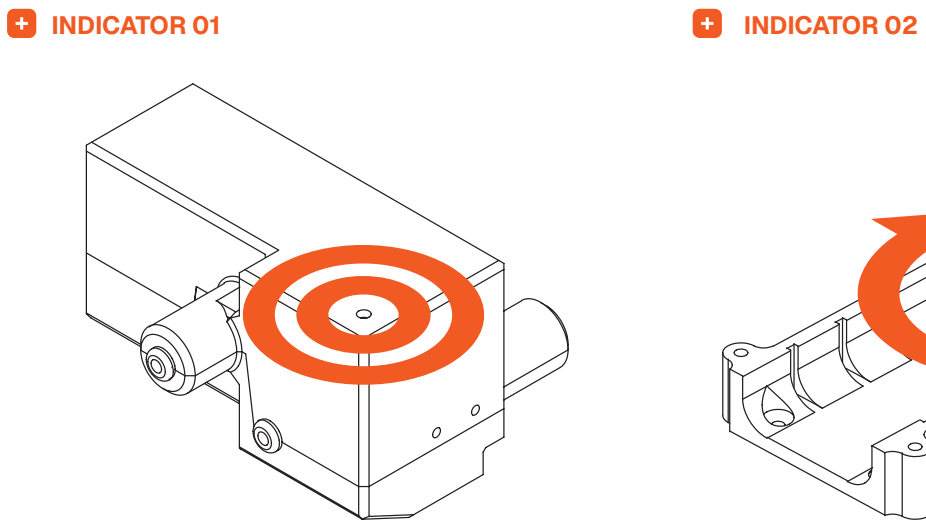
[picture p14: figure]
INDICATOR 01; INDICATOR 02

## 02 | Remove backpanel

## 03 | Replacing the bait

STEP 01

4x

4x

STEP 06
STEP 02 STEP 03
Twist the button counter clockwise to unlock the back panel. | Hinge the panel outward, then remove it.

## 01 | Startup sequence indicators

A green LED on top of the detection unit should illuminate.

These indicate that the startup sequence has been completed successfully.. if not please reach out to ...

The door should automatically open and close once.

8 | Copyright © 2026 Accenture & Imkers Leiden. All rights reserved. | Copyright © 2026 Accenture & Imkers Leiden. All rights reserved. | 9

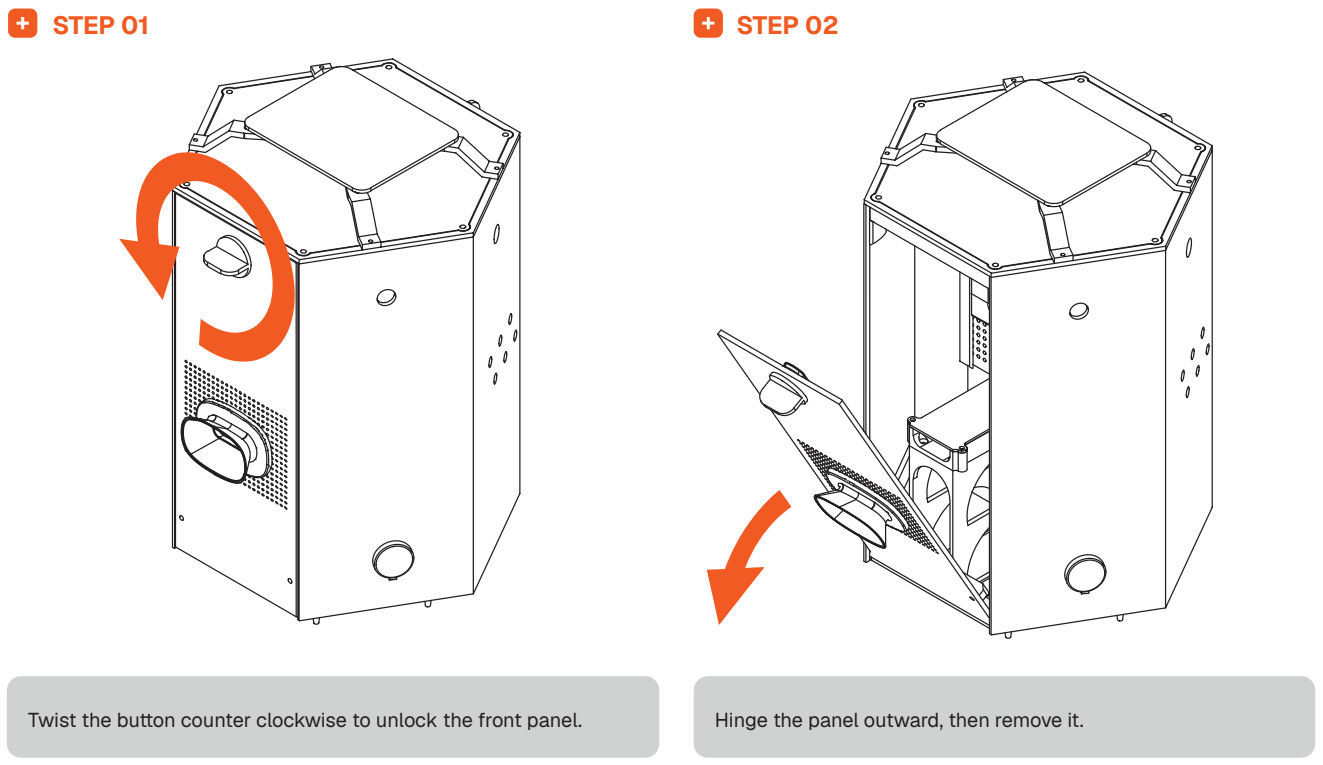
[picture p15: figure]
STEP 01; STEP 02

The health check can be performed without opening the product, by looking through the clear panels. If desired, the front panel can be removed to increase visibility, or for cleaning purposes

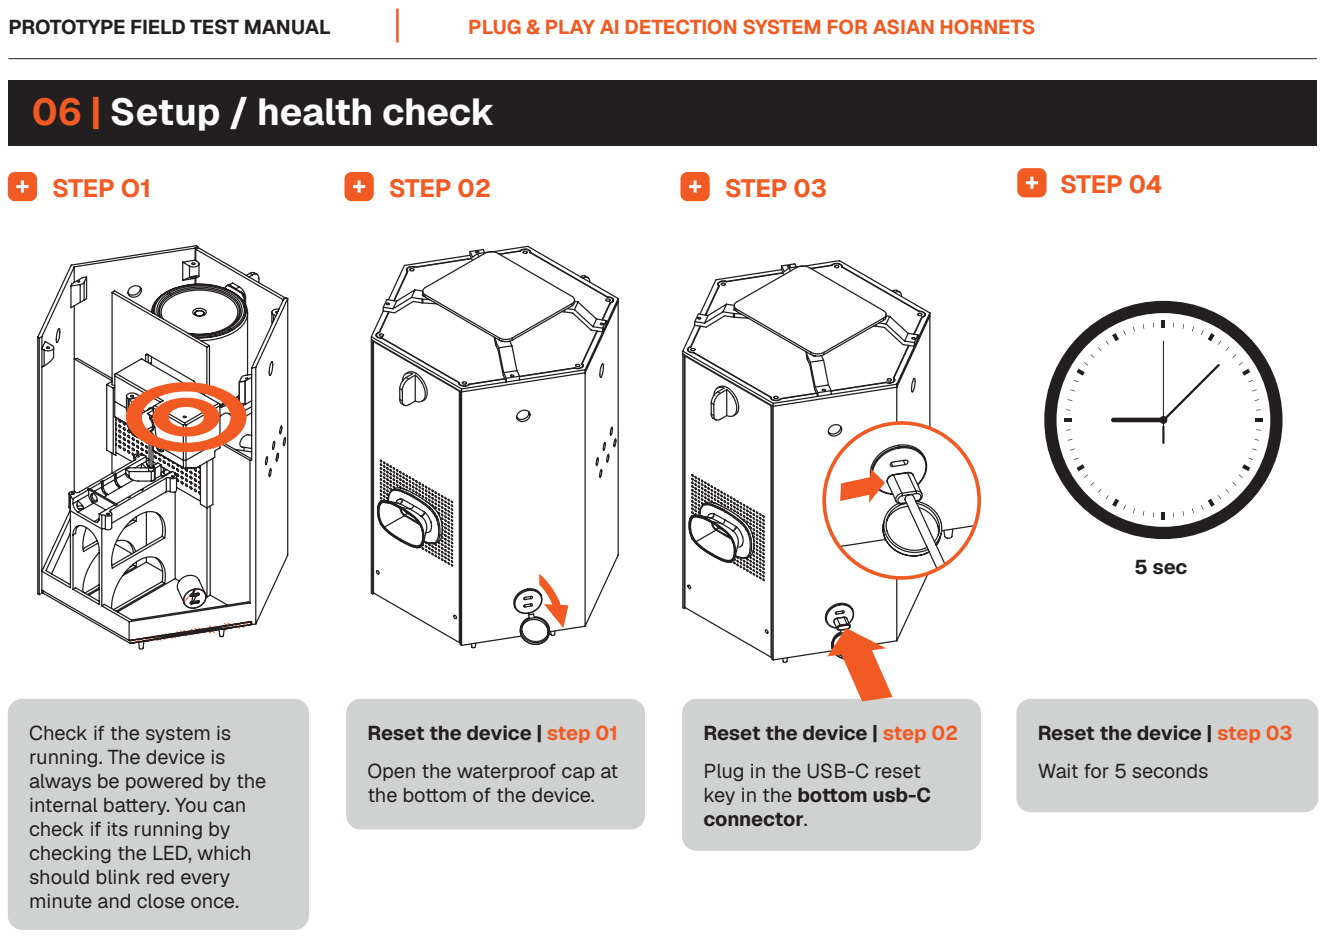
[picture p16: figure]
06 | Setup / health check; Check if the system is running. The device is always be powered by the internal battery. You can check if its running by checking the LED, which should blink red every minute and close once.; Reset the device | step 01 Open the waterproof cap at the bottom of the device.; Reset the device | step 03 Wait for 5 seconds; Reset the device | step 02 Plug in the USB-C reset key in the bottom usb-C connector.; STEP O1; STEP 02; STEP 03; STEP 04; 5 sec

Reset the device | step 04
Remove the USB-C reset
key from the bottom usb-C
connector

## 05 | Remove front panel for healh check

STEP 05 | STEP 06 | STEP 07 | STEP 08
Twist the button counter clockwise to unlock the front panel. | Hinge the panel outward, then remove it.
Reset the device | step 05
2 seconds after removing
the connector from step 4, LED should blink red.
Reset the device | step 06
The door should switch
position, Then, after another 10 seconds, the door should switch back
Reset the device | step 07
Fix the waterproof cap back onto the connection plug
2 sec | 10 sec

Slide the trap jar holder outward by grabbing the trap jar lid and pulling it out (highlighted orange).

## 04 | Removing a trapped hornet

STEP 01 | STEP 02 | STEP 03
Twist the trap jar to loosen. | Remove it from the trap jar lid.
10 | Copyright © 2026 Accenture & Imkers Leiden. All rights reserved. | Copyright © 2026 Accenture & Imkers Leiden. All rights reserved. | 11

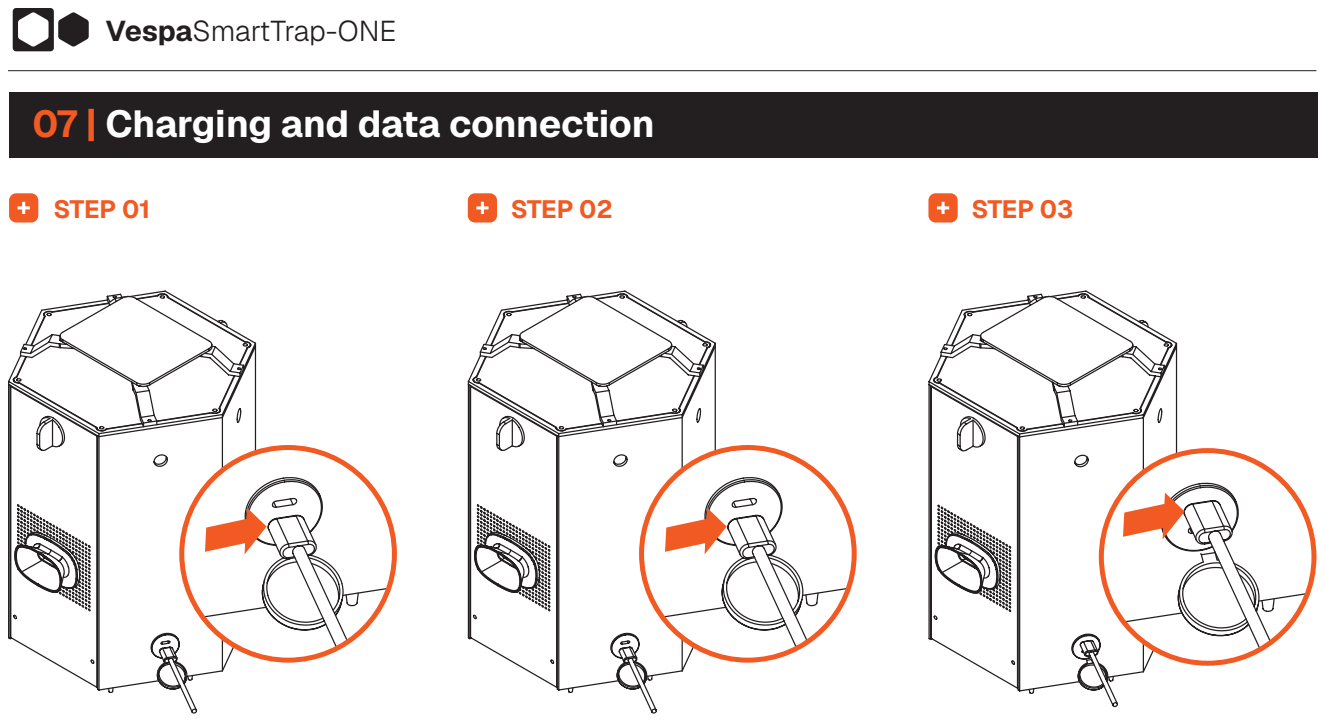
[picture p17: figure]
07 | Charging and data connection; STEP 01; STEP 02; STEP 03

### In order to get the right insights from the test, the following tasks need to be

performed daily. Use the provided sheet to log.
01 -> Check wether the device is running
02 -> Perform a health check (refer to page x)
03 -> Inspect the bait area; is there still plenty of bait in the pot?
If there is less than 30% inside, please refill the bait according to instructions on page x 04 -> Inspect the trap container
If a hornet is present in the chamber, you can let it stay there until it dies?
Are there othere animals present inside the chamber
05 -> Inspect the cotton sticks
Are they still sticking out into the chamber?
If not, replace the cotton sticks

## 08 | Daily test log

To charge the device, plug the provided USB-C cable in the bottom connector and connect it to a power sourceunit should illuminate.

To read out the firmware log,
or flash new firmware, plug the provided USB-C cable in the bottom connector and connect it to a laptop.

To read out the Groove vision video directly, plug the provided USB-C cable in the top connector and connect it to a laptop.

To get reliable insights from the test,
complete the tasks in the table on the next page every day.

### -> Use one row per day: tick each task once done, note how many hornets you saw, and add

anything notable in the comments.

### What each column means:

01 -> DEVICE RUNNING: Check whether the device is running.
02 -> HEALTH CHECK: Perform a health check (see manual).
03 -> BAIT >30% : Inspect bait area : tick if pot is still over 30% full.
04 -> BAIT REFILLED: If bait is below 30%, refill it (see manual) and tick.
05 -> TRAP CHECKED: Inspect the trap container : tick when checked.
A trapped hornet may be left until it dies; note other findings under Comments.
06 -> OTHER ANIMALS:Tick if other (non-hornet) animals were present in the chamber.
07 -> COTTON STICKS OK?: Cotton sticks still poking into the chamber? Tick if OK; if not, replace them. (see manual)
Date | 01 | 02 | 03 | 04 | 05 | 06 | 07 | Hornets | Comments
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
12 | Copyright © 2026 Accenture & Imkers Leiden. All rights reserved. | Copyright © 2026 Accenture & Imkers Leiden. All rights reserved. | 13

09 | Field notes | 10 | Feedback & ideas
Use this space to write down anything you notice during testing: trap location, weather condi- tions, insect behaviour, bait condition, or changes around the trap. Small observations can be useful later when comparing test results. | Use this space to share your experience with the prototype. Note what worked well, what was unclear, what could be improved, and any ideas that may help make the next version better.
14 | Copyright © 2026 Accenture & Imkers Leiden. All rights reserved. | Copyright © 2026 Accenture & Imkers Leiden. All rights reserved. | 15

### QUESTIONS, ISSUES OR TEST FEEDBACK?

### Email ah-val@imkersleiden.nl

### GitHub repository github.com/aggerritsen/VespaSmartTrap-ONE

16 | Copyright © 2026 Accenture & Imkers Leiden. All rights reserved.

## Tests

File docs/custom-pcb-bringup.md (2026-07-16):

# Custom PCB Bring-Up

The custom PCB provides the mechanical and electrical attachment between the T-SIM7080G-S3 base and the Grove Vision AI V2 stick-on module. Its source is included as an external submodule:

```text
external/t-sim-motor-shield/
```

Use that repo for PCB source, documentation, and motor shield validation firmware. Keep base application firmware in `t-sim/firmware/`.

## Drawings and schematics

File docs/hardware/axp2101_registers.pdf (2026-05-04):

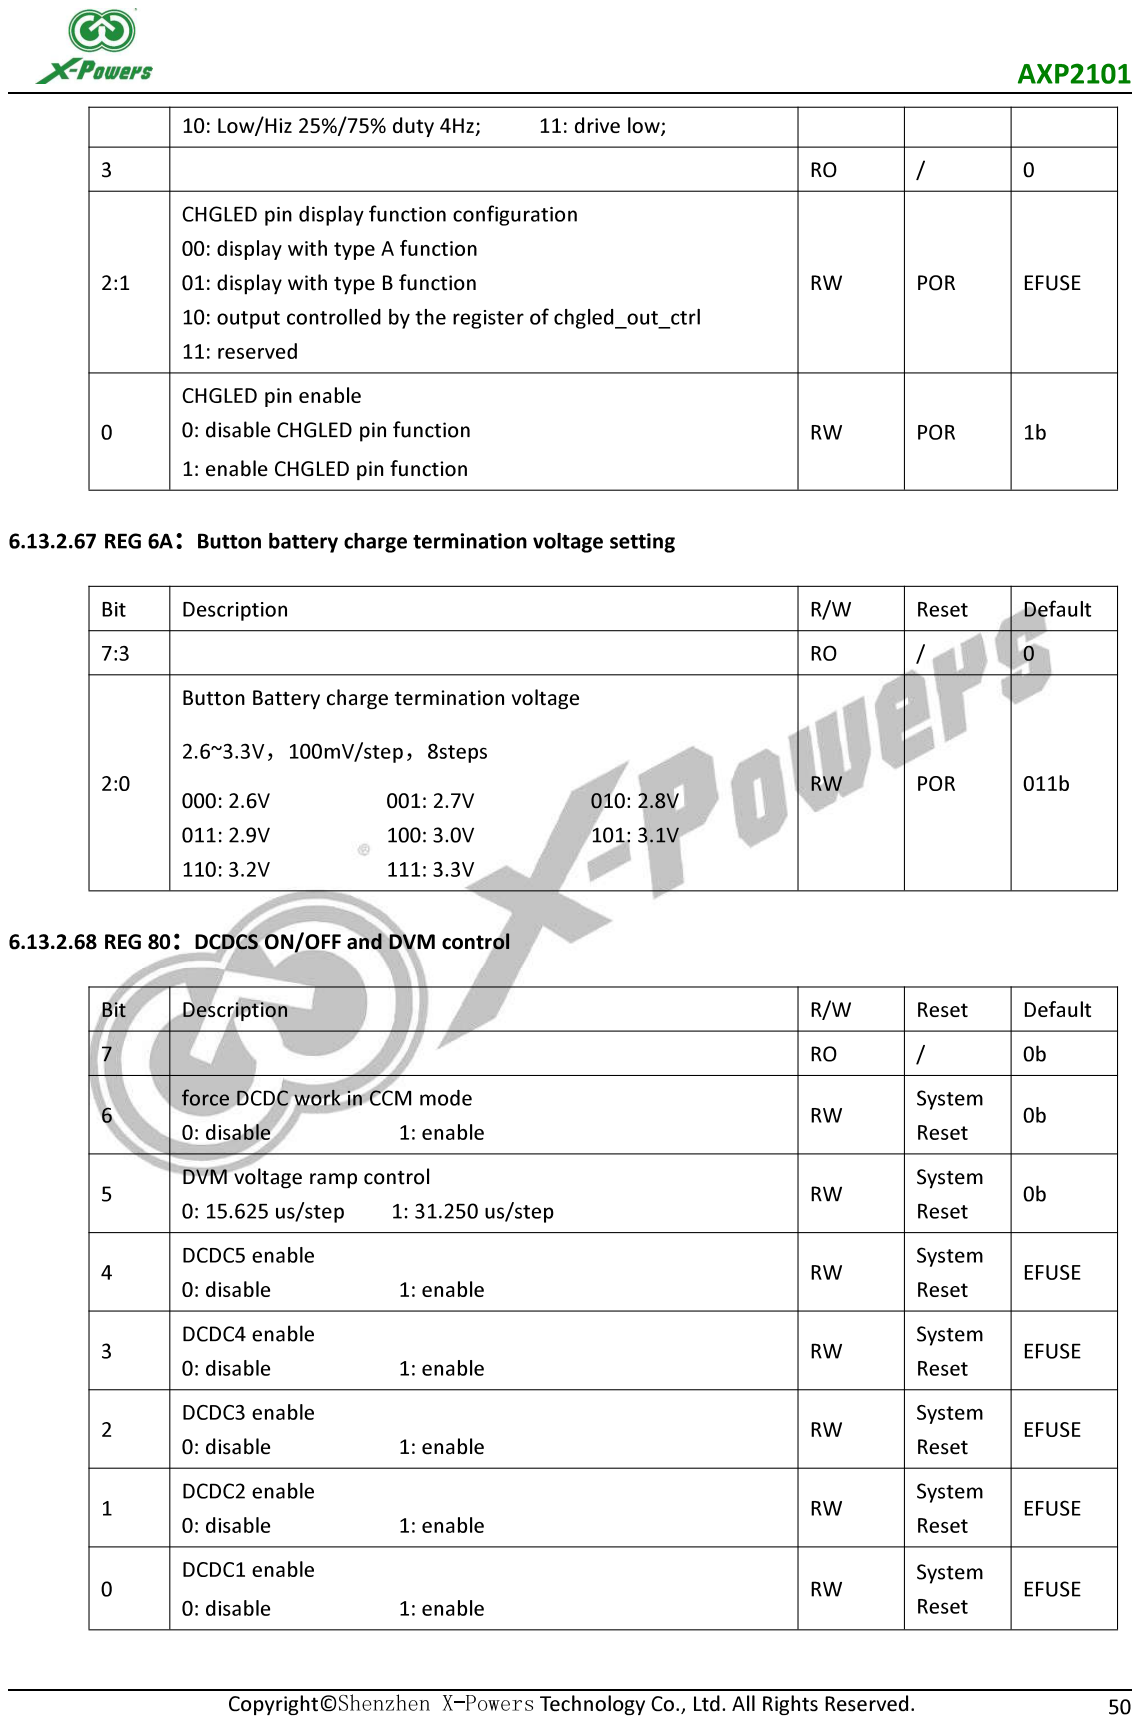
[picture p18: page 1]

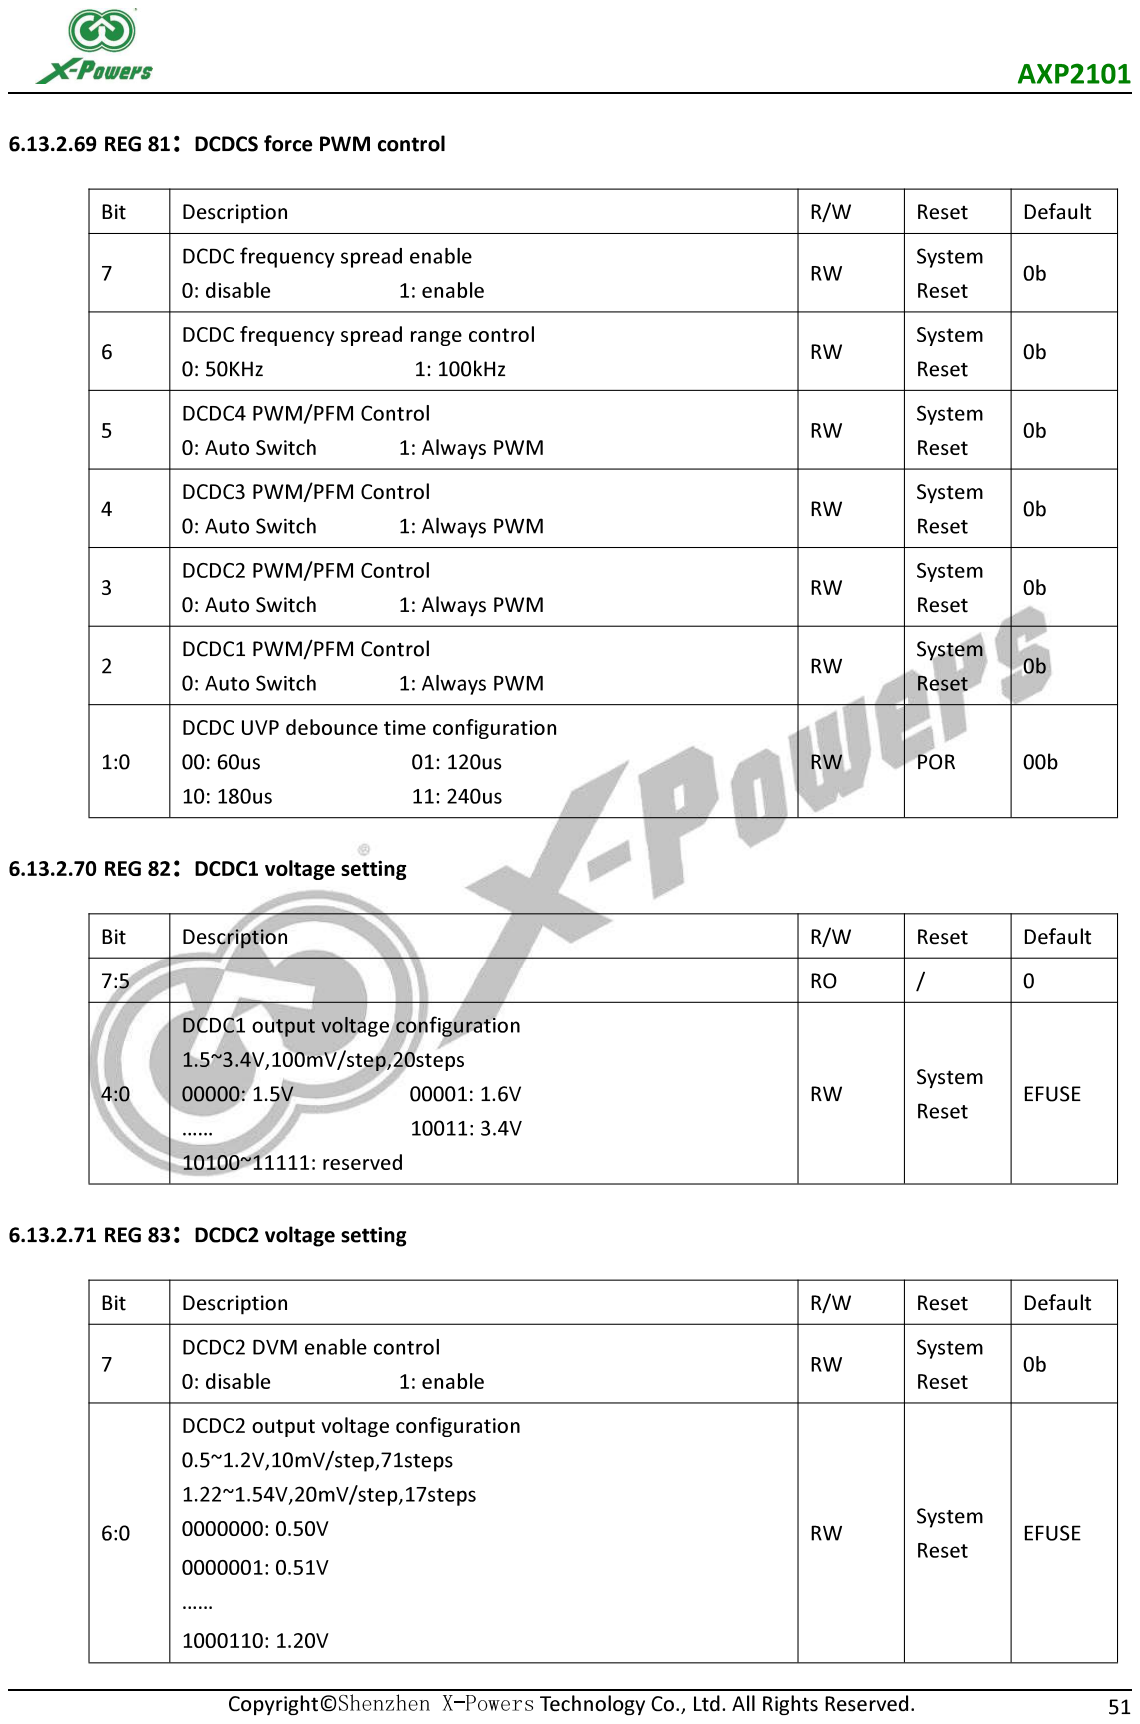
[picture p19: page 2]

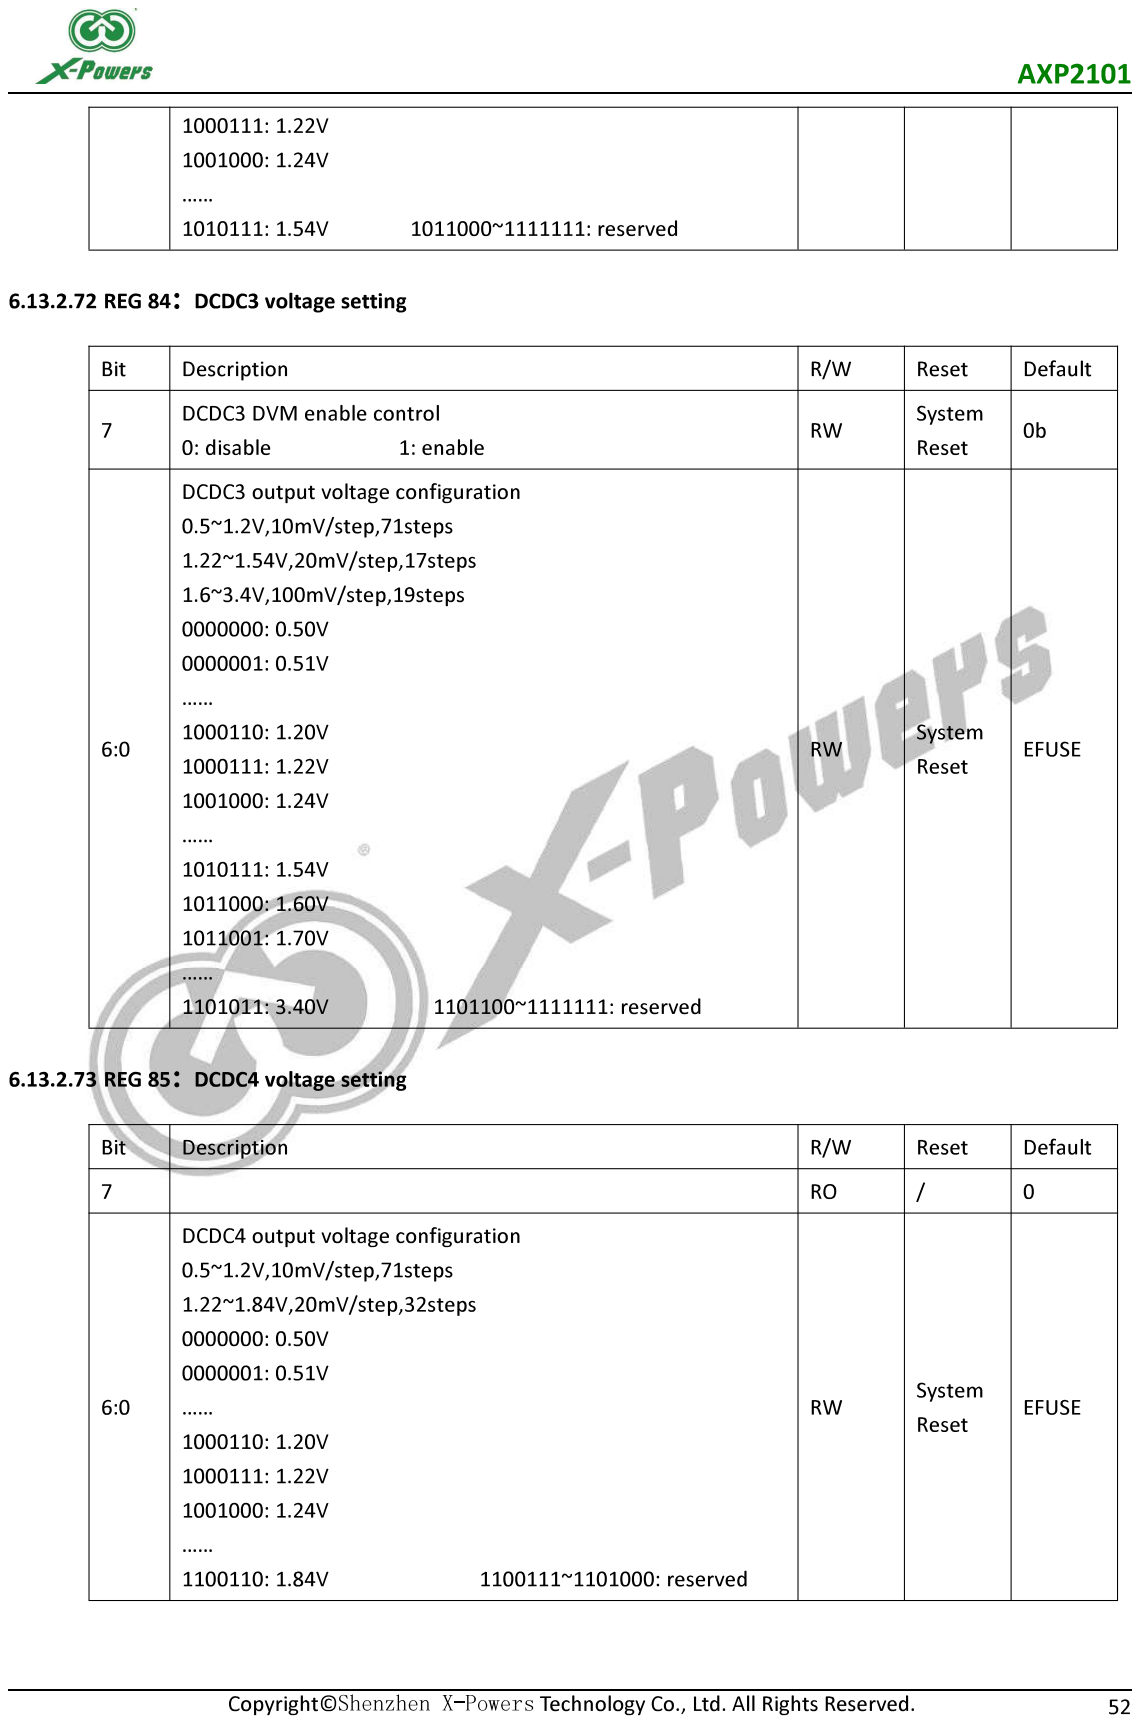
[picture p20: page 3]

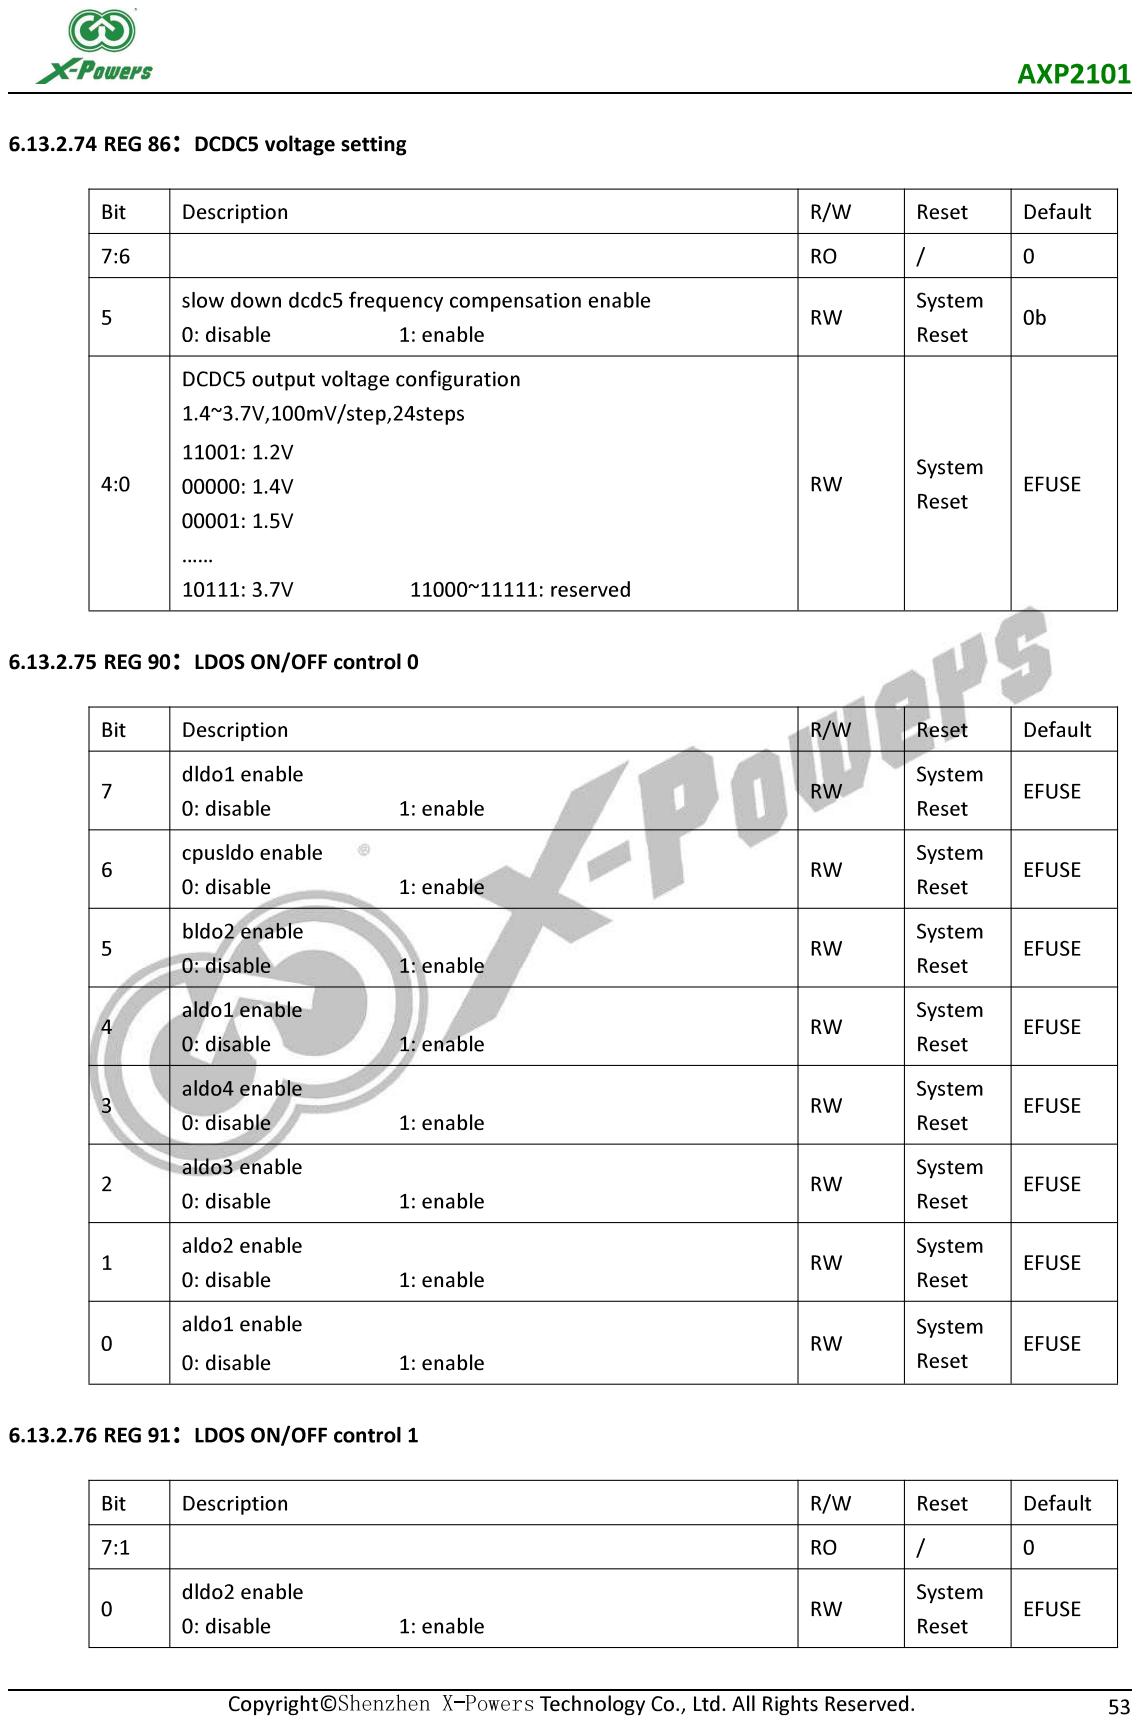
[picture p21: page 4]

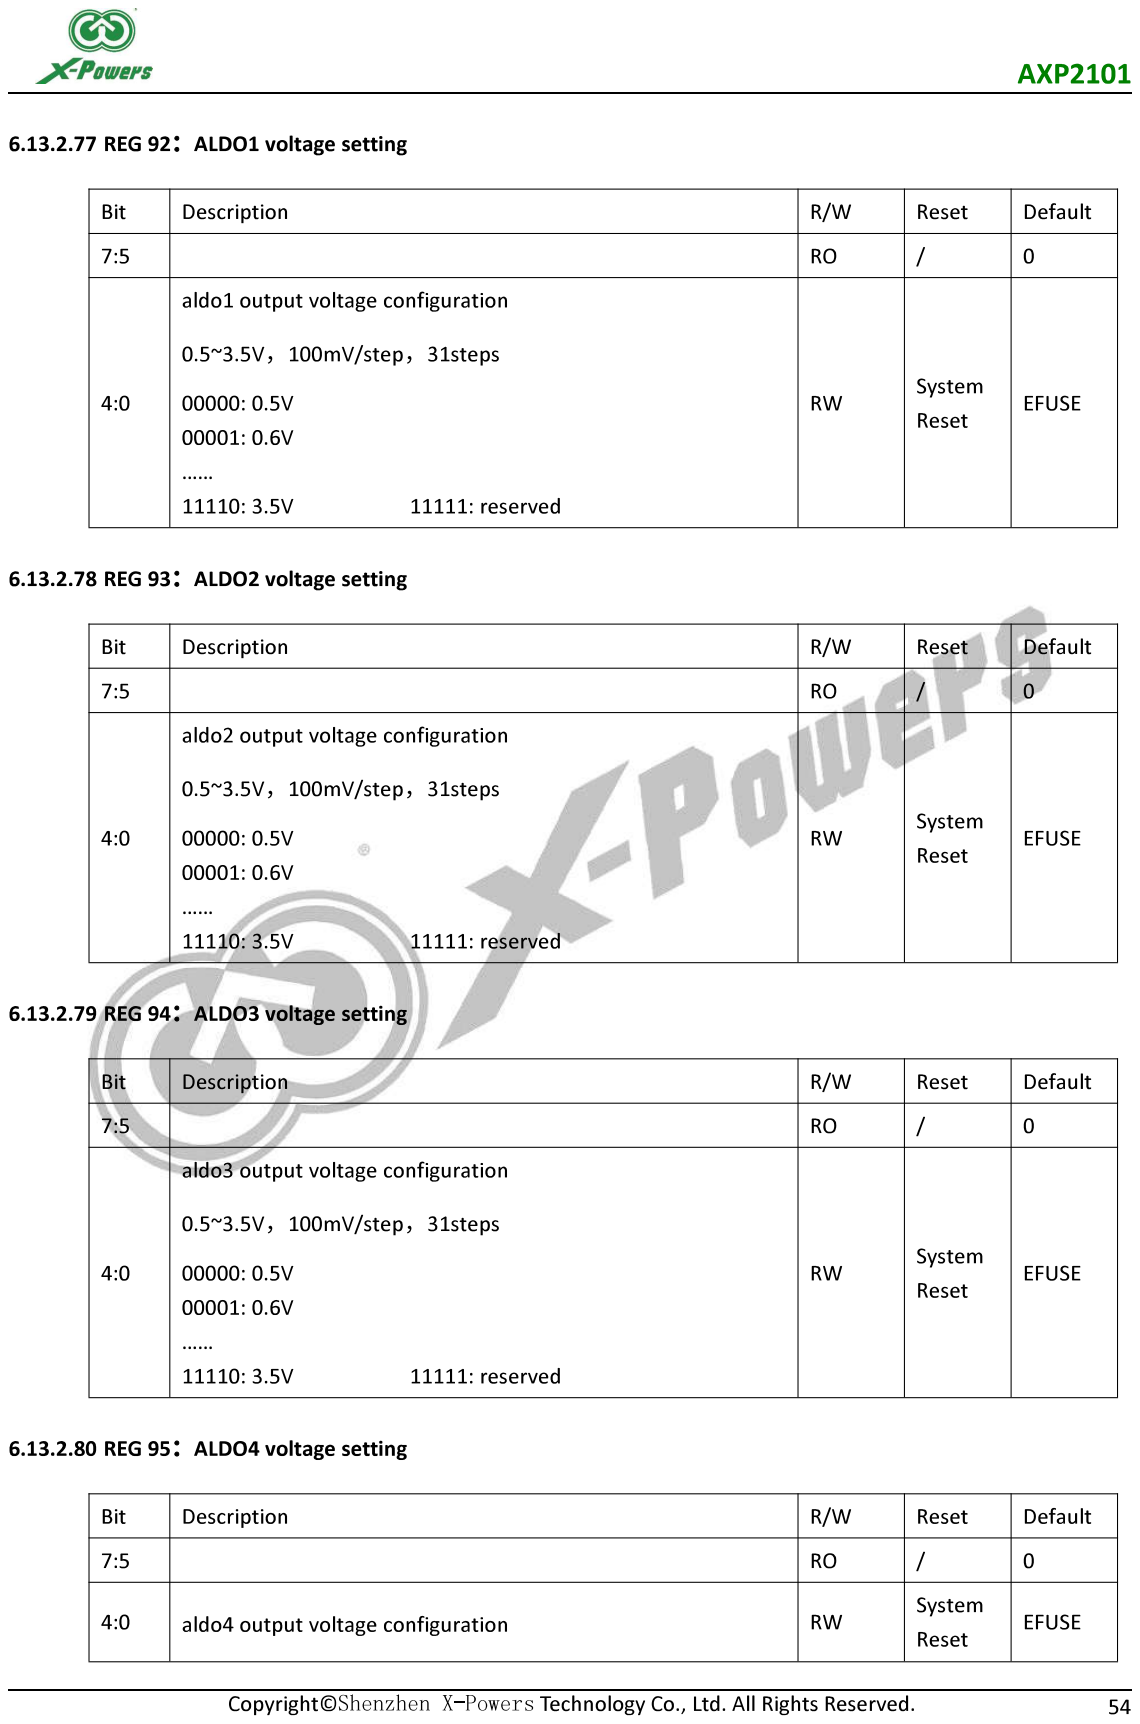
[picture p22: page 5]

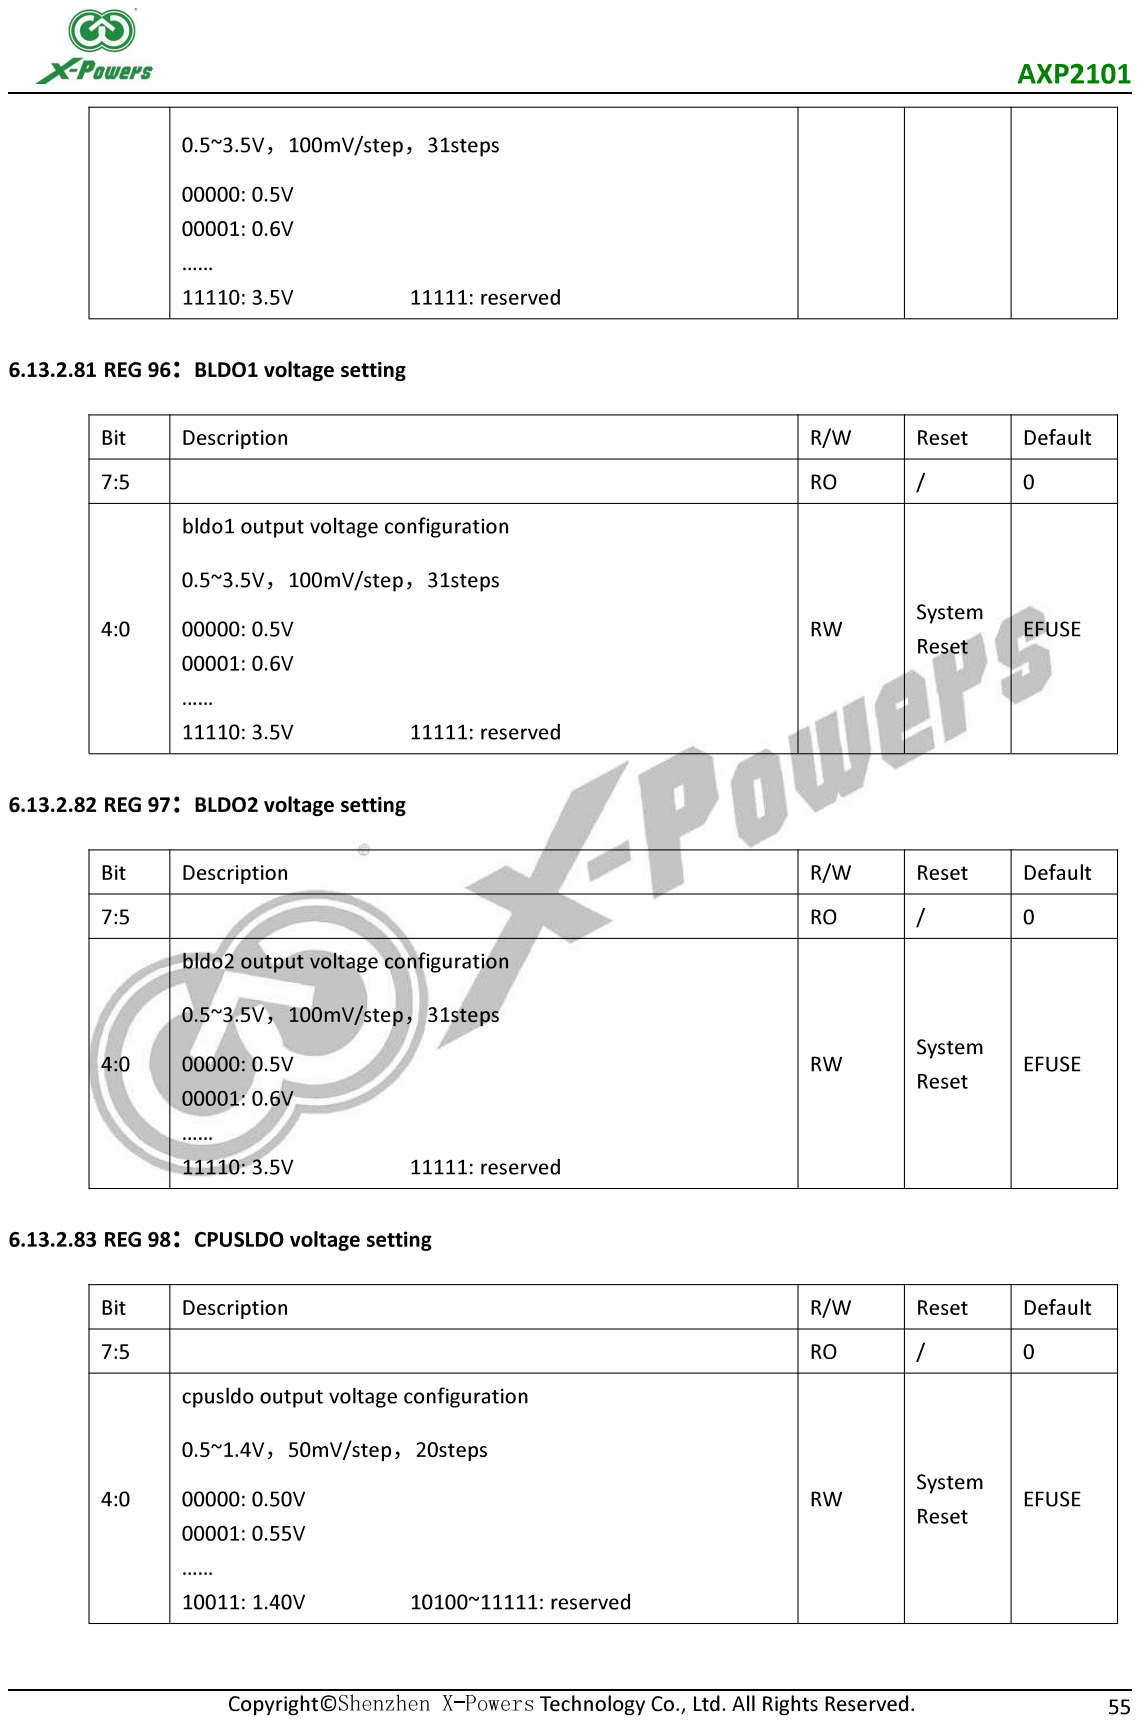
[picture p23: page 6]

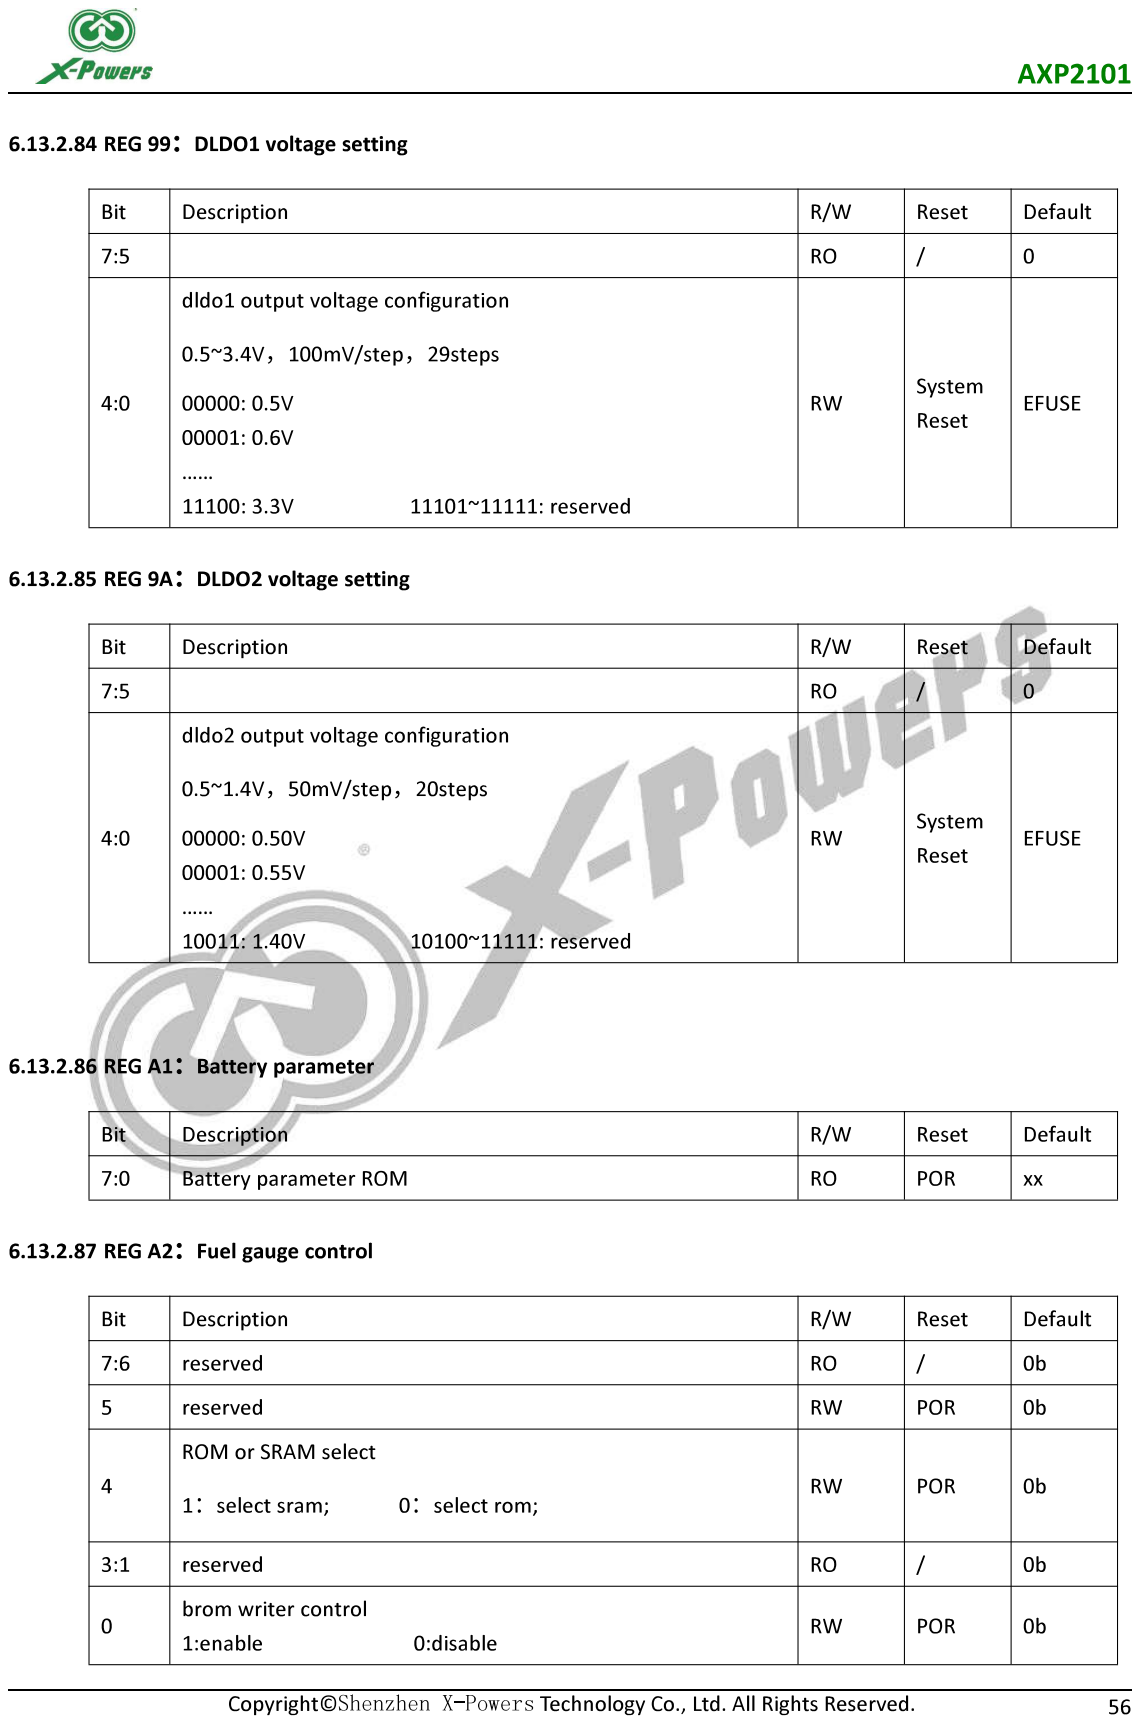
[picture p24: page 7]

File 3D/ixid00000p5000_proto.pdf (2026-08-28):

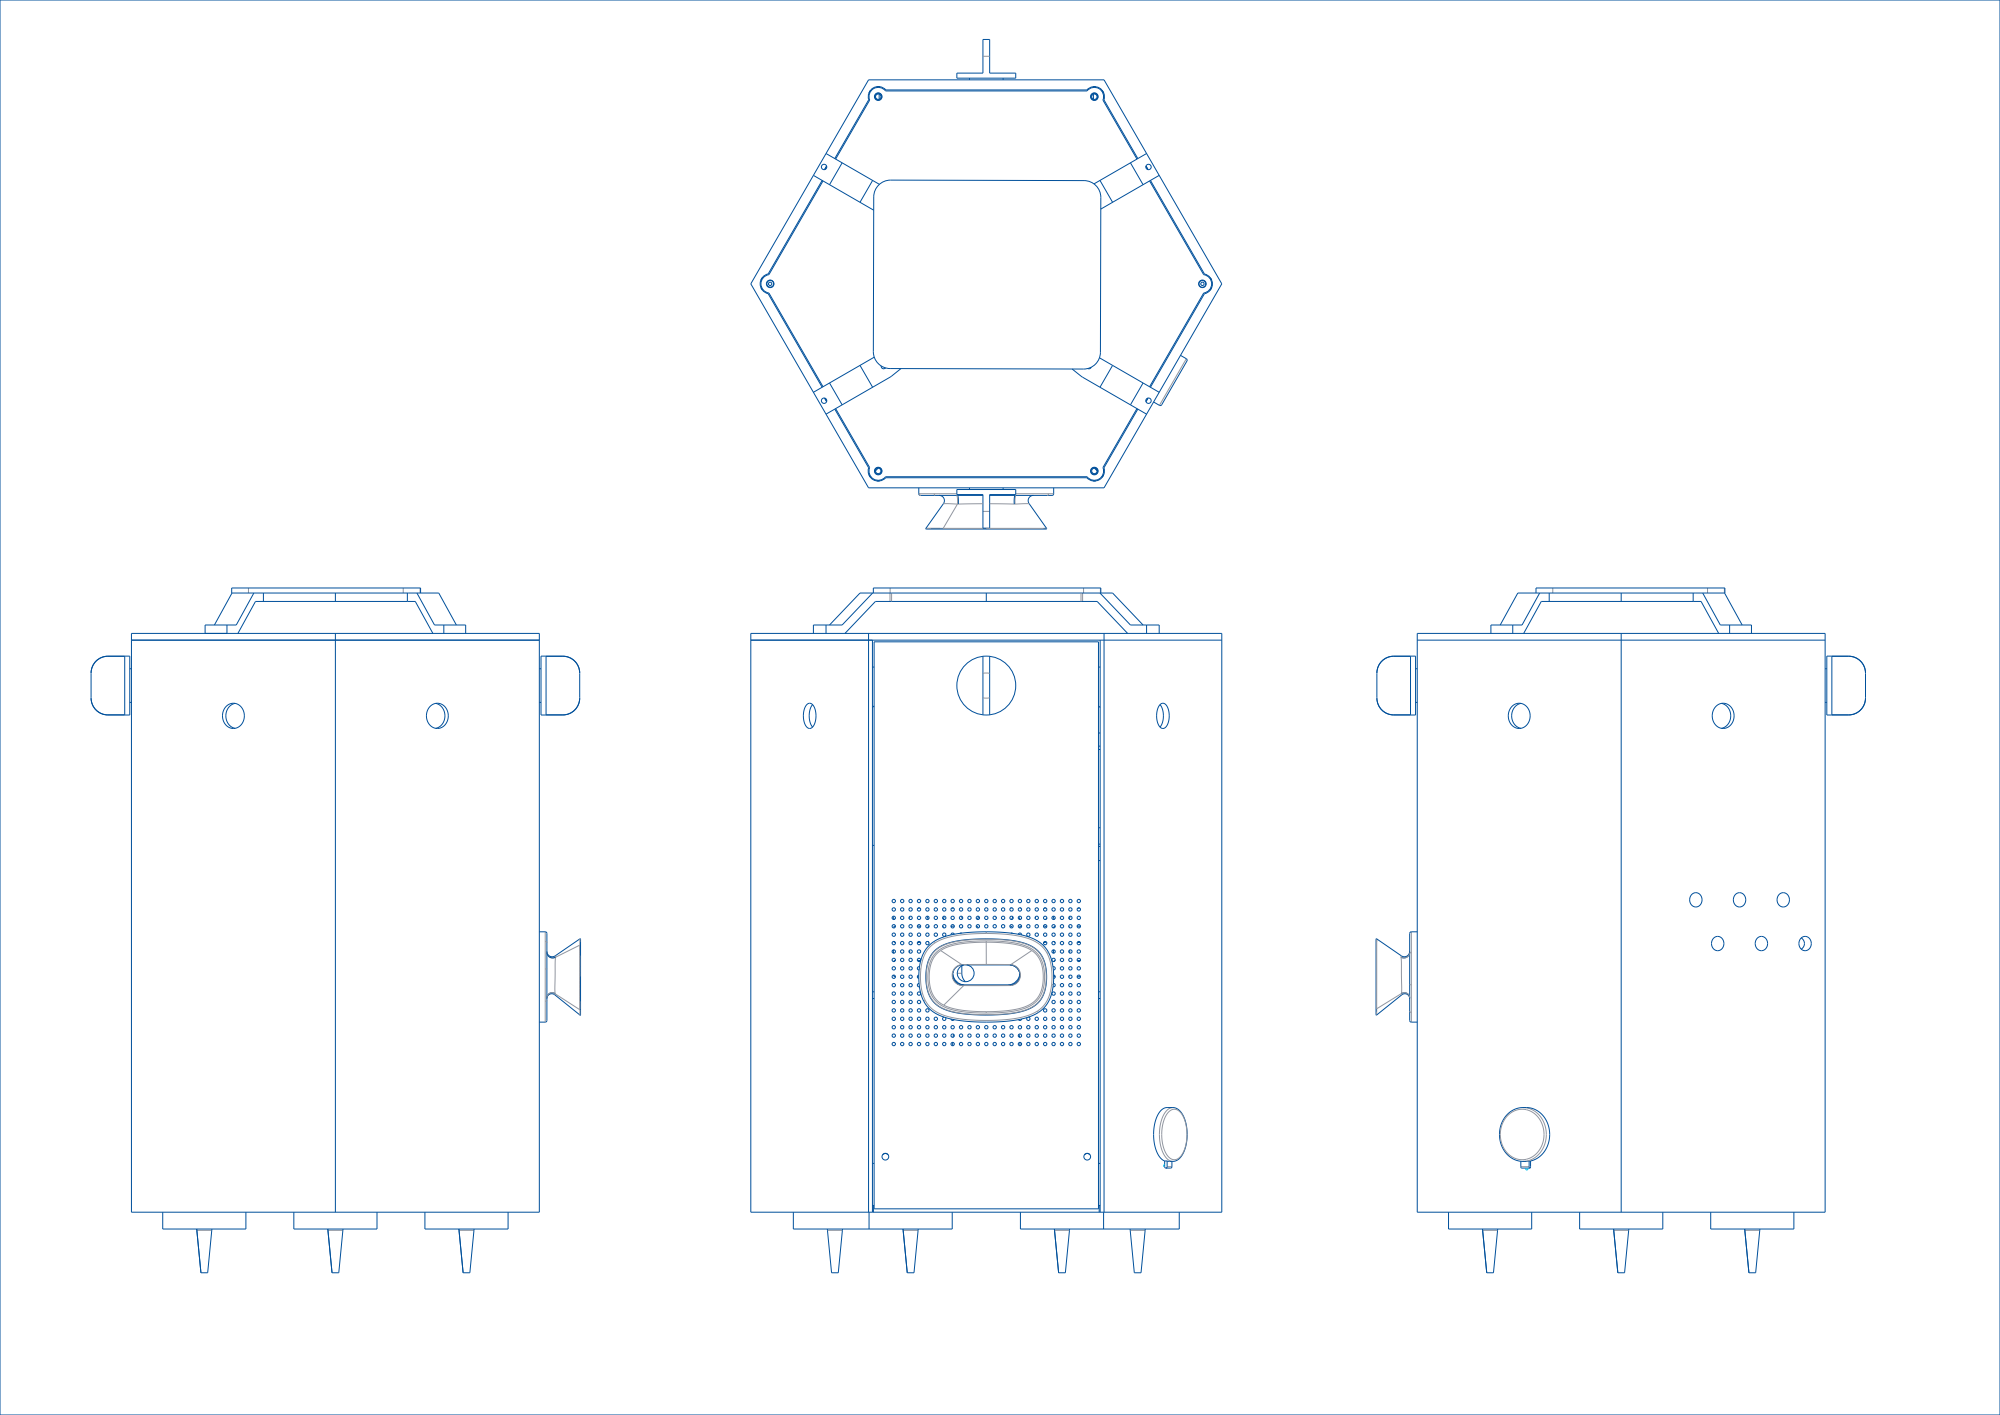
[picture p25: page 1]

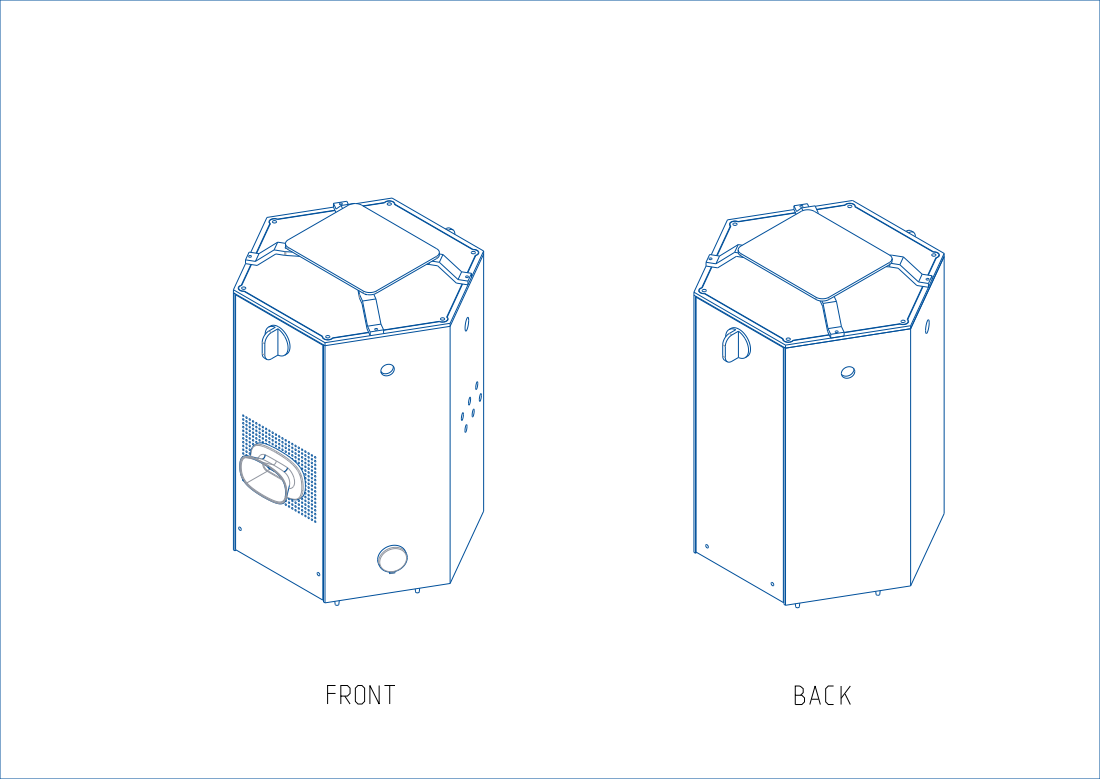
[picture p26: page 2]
FRONT; BACK

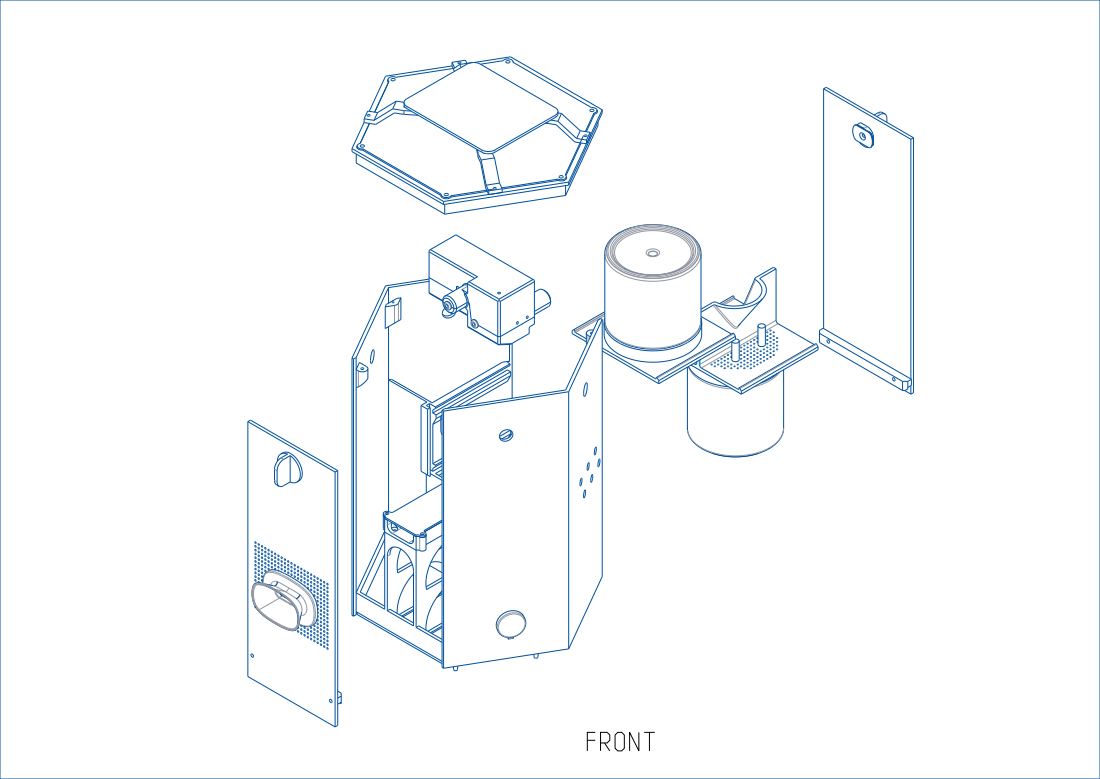
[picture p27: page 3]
FRONT

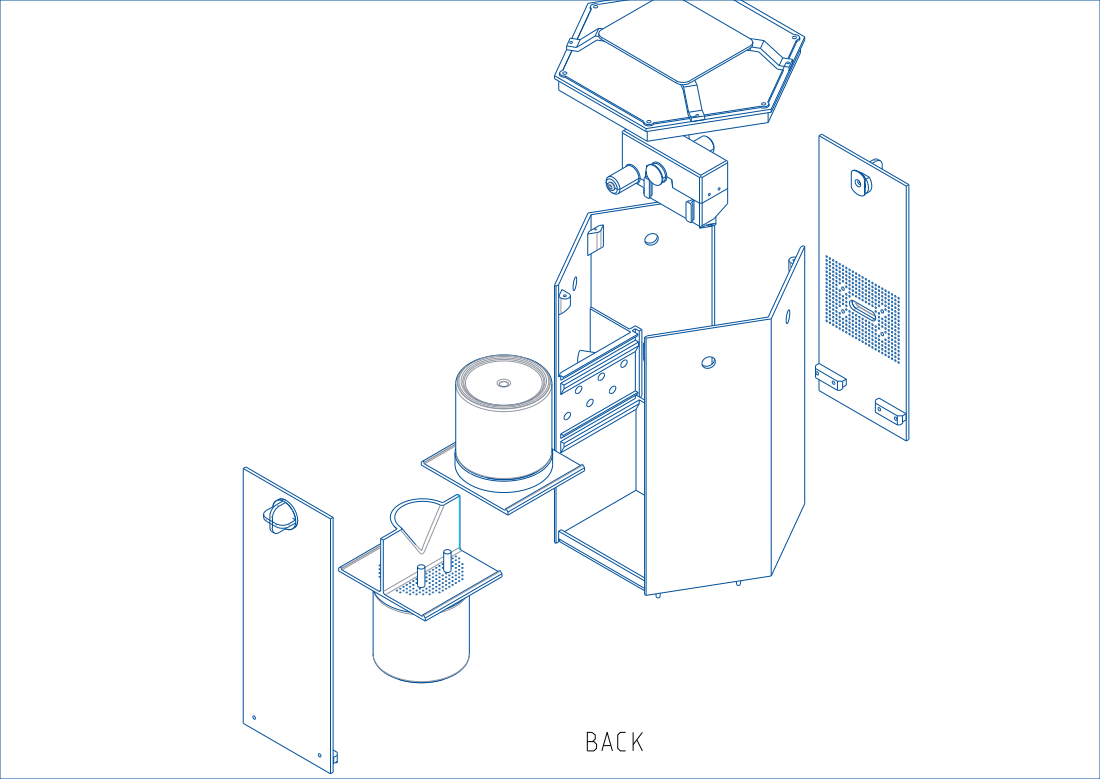
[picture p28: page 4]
BACK

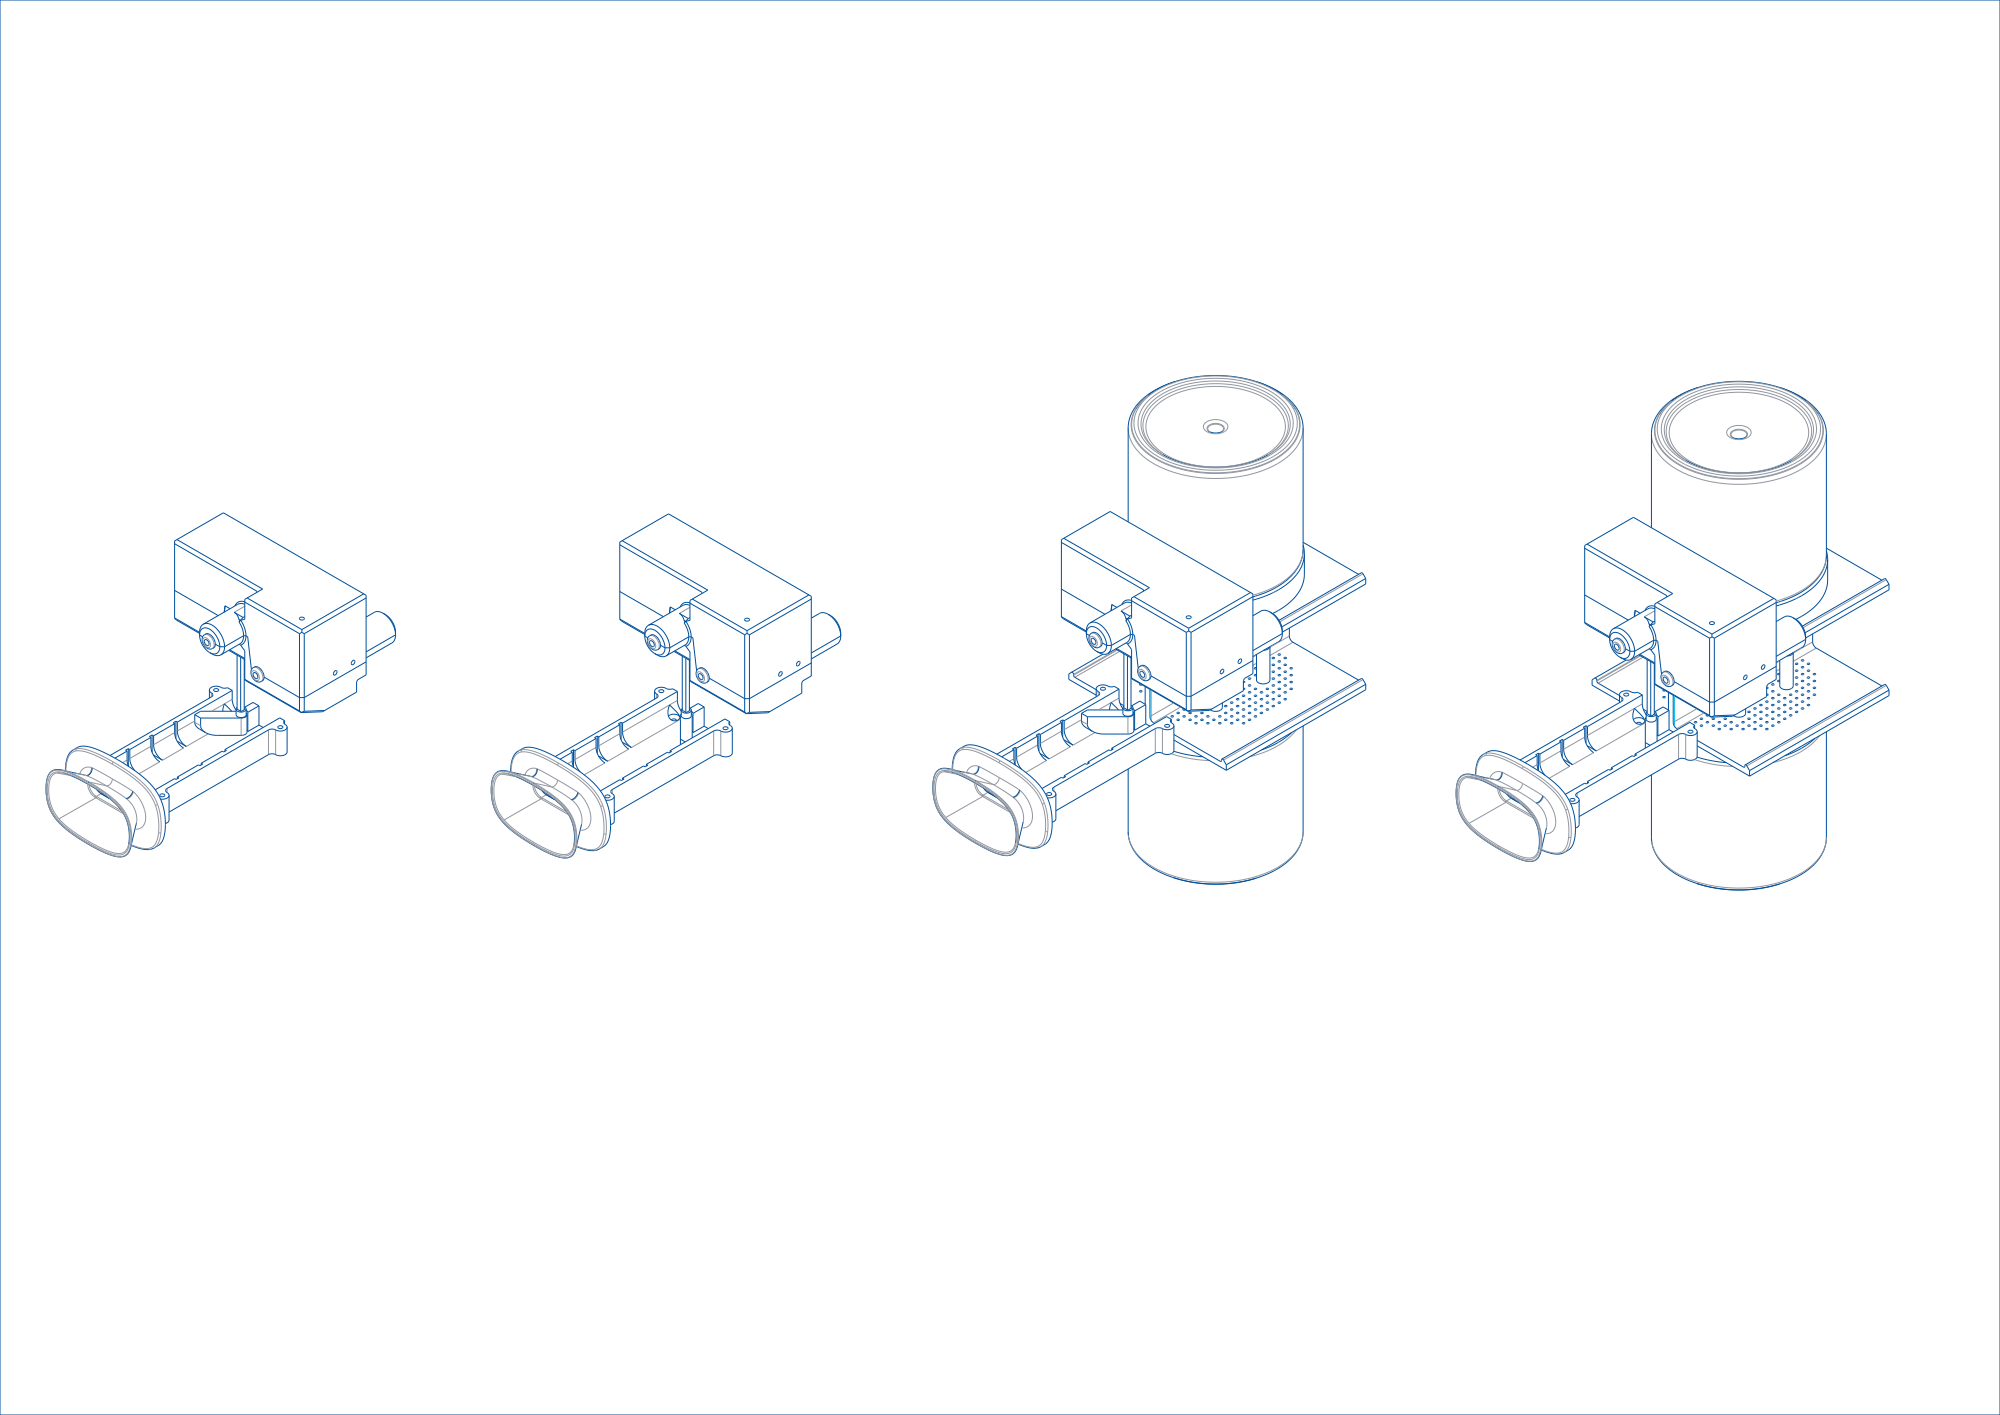
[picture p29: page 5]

BACK

BACK

BACK

FRONT



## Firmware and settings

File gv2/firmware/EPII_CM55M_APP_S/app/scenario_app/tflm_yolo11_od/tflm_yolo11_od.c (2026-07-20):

// version 2026-04-28 I2C disabled to avoid conflicts on those pin

#include <assert.h>
#include <stdbool.h>
#include <stdint.h>
#include <string.h>
#include <stdlib.h>
#include "powermode_export.h"




// #define WATCH_DOG_TIMEOUT_TH	(20000) //ms
#define WATCH_DOG_TIMEOUT_TH	(500) //ms

#ifdef TRUSTZONE_SEC
#ifdef FREERTOS
/* Trustzone config. */
//
/* FreeRTOS includes. */
//#include "secure_port_macros.h"
#else
#if (__ARM_FEATURE_CMSE & 1) == 0
#error "Need ARMv8-M security extensions"
#elif (__ARM_FEATURE_CMSE & 2) == 0
#error "Compile with --cmse"
#endif
#include "arm_cmse.h"
//#include "veneer_table.h"
//
#endif
#endif

#include "WE2_device.h"

#include "spi_master_protocol.h"
#include "hx_drv_spi.h"
#include "spi_eeprom_comm.h"
#include "board.h"
#include "xprintf.h"
#include "tflm_yolo11_od.h"
#include "board.h"
#include "WE2_core.h"
#include "hx_drv_scu.h"
#include "hx_drv_swreg_aon.h"
#ifdef IP_sensorctrl
#include "hx_drv_sensorctrl.h"
#endif
#ifdef IP_xdma
#include "hx_drv_xdma.h"
#include "sensor_dp_lib.h"
#endif
#ifdef IP_cdm
#include "hx_drv_cdm.h"
#endif
#ifdef IP_gpio
#include "hx_drv_gpio.h"
#endif
#include "hx_drv_pmu_export.h"
#include "hx_drv_pmu.h"
#include "powermode.h"
//#include "dp_task.h"
#include "BITOPS.h"

#include "common_config.h"
#include "cisdp_sensor.h"
#include "event_handler.h"
#include "cvapp_yolo11n_ob.h"
#include "memory_manage.h"
#include "hx_drv_watchdog.h"

// I2C slave output to host MCU (ESP32-S3).
// Disabled by default for the "UART-only" setup (define VST_I2C_STATE_TX to enable).
#ifdef VST_I2C_STATE_TX
#include "hx_drv_iic.h"
#endif

// Optional UART output to host MCU (ESP32-S3).
// NOTE: This uses the console UART peripheral (ID 0). [to be verified]
#ifdef VST_UART_STATE_TX
#include "hx_drv_uart.h"
#endif


#ifdef EPII_FPGA
#define DBG_APP_LOG             (1)
#else
#define DBG_APP_LOG             (0)
#endif
#if DBG_APP_LOG
    #define dbg_app_log(fmt, ...)       xprintf(fmt, ##__VA_ARGS__)
#else
    #define dbg_app_log(fmt, ...)
#endif

#define TOTAL_STEP_TICK 1
#define TOTAL_STEP_TICK_DBG_LOG 0

#if TOTAL_STEP_TICK
#define CPU_CLK	0xffffff+1
#endif

#define GROVE_VISION_AI_II

static uint8_t 	g_xdma_abnormal, g_md_detect, g_cdm_fifoerror, g_wdt1_timeout, g_wdt2_timeout,g_wdt3_timeout;
static uint8_t 	g_hxautoi2c_error, g_inp1bitparer_abnormal;
static uint32_t g_dp_event;
static uint8_t 	g_frame_ready;
static uint32_t g_cur_jpegenc_frame;
static uint8_t 	g_time;
static uint8_t g_spi_master_initial_status;
static uint32_t g_use_case;
/*volatile*/ uint32_t jpeg_addr, jpeg_sz;
struct_algoResult algoresult;
struct_fm_algoResult  algoresult_fm;
struct_hp_algoResult  algoresult_pl;
struct_fl_fr_enroll_algoResult  algoresult_fl_fr_enroll;
struct_fl_fr_algoResult  algoresult_fl_fr_infer;
struct_yolov8_ob_algoResult algoresult_yolo11n_ob;
struct_yolov8_ob_algoResult algoresult_yolofastest_ob;
struct_yolov8_pose_algoResult algoresult_yolo11_pose;
static uint32_t g_trans_type;
static uint32_t judge_case_data;
void app_start_state(APP_STATE_E state);
void model_change(void);
void pinmux_init();

// --- Minimal I2C slave "detection state" protocol ---
// The host reads 1 byte from an I2C slave address:
// - 0: none
// - 1: hornet present (class 3)
// - 2: other class present (any class != 3)
// Use 0x63 to avoid collisions while debugging bus visibility.
// Once proven visible, we can switch back to 0x62.
#ifdef VST_I2C_STATE_TX
static const uint8_t kI2cSlaveAddressSlv0 = 0x63;
static volatile uint8_t g_i2c_detection_state = 0;
static uint8_t g_i2c_tx_buf_slv0[1] = {0};
#endif
static const float kMinDetectionConfidence = 0.60f;

#ifdef VST_UART_STATE_TX
static DEV_UART* g_uart_state_tx_dev = NULL;
static uint32_t g_last_uart_tx_frame = 0;

static void uart_state_tx_init_once(void) {
    if (g_uart_state_tx_dev != NULL) {
        return;
    }
    // Use UART1 for the external Grove/UART connector (PB6/PB7 on the module schematic). [to be verified]
    g_uart_state_tx_dev = hx_drv_uart_get_dev(USE_DW_UART_1);
    if (g_uart_state_tx_dev != NULL) {
        // Keep baudrate consistent with existing UART tooling in this scenario. [to be verified]
        g_uart_state_tx_dev->uart_open(UART_BAUDRATE_921600);
    }
}

static void uart_state_tx_send_byte(uint8_t value) {
    uart_state_tx_init_once();
    if (g_uart_state_tx_dev == NULL) {
        return;
    }
    // Framed state message to avoid false positives from UART noise on the host:
    // 'V' 'S' 'T' 'S' + state(1)
    const uint8_t msg[5] = {'V', 'S', 'T', 'S', value};
    (void)g_uart_state_tx_dev->uart_write((const char*)msg, sizeof(msg));
    g_last_uart_tx_frame = g_cur_jpegenc_frame;
}
#endif

#ifdef VST_UART_JPEG_TX
// JPEG capture policy:
// - LED/state decision uses kMinDetectionConfidence (0.60).
// - JPEG send decision mirrors the T-SIM positive filter so GV2 only CRCs/sends useful candidates.
static const float kMinCaptureConfidence = 0.745f;
static const uint8_t kCaptureClassIdx = 3;

// Binary framing to the host MCU:
// Header: 'V' 'S' 'T' 'J' + state(1) + class_idx(1) + conf_u8(1) + bbox_x/y/w/h_u16_le + len_u32_le(4) + crc32_u32_le(4)
static const uint8_t kJpegMagic[4] = {'V', 'S', 'T', 'J'};

// Frame-based rate limit: send at most ~1 JPEG per N frames.
// This approximates 3 images/sec without relying on EVT_INDEX_SENSOR_RTC_FIRE. [to be verified]
static const uint32_t kMinFramesBetweenJpegs = 3;
static const uint32_t kMaxUartJpegPayload = 16U * 1024U;
static uint32_t g_last_jpeg_sent_frame = 0;
static uint8_t g_uart_jpeg_copy[16U * 1024U];

static uint8_t clamp_conf_to_u8(float conf) {
    if (conf <= 0.0f) return 0;
    if (conf >= 1.0f) return 255;
    return (uint8_t)(conf * 255.0f);
}

static void uart_send_bytes(const uint8_t* data, uint32_t len) {
    uart_state_tx_init_once();
    if (g_uart_state_tx_dev == NULL || data == NULL || len == 0) return;
    // Pace writes so the UART driver/FIFO can drain larger 4X JPEG payloads.
    uint32_t pos = 0;
    while (pos < len) {
        uint32_t chunk = (len - pos) > 128 ? 128 : (len - pos);
        (void)g_uart_state_tx_dev->uart_write((const char*)(data + pos), chunk);
        pos += chunk;
        if (pos < len) {
            board_delay_ms(2);
        }
    }
}

static void uart_send_u32_le(uint32_t v) {
    uint8_t b[4];
    b[0] = (uint8_t)(v & 0xFF);
    b[1] = (uint8_t)((v >> 8) & 0xFF);
    b[2] = (uint8_t)((v >> 16) & 0xFF);
    b[3] = (uint8_t)((v >> 24) & 0xFF);
    uart_send_bytes(b, 4);
}

static void uart_send_u16_le(uint16_t v) {
    uint8_t b[2];
    b[0] = (uint8_t)(v & 0xFF);
    b[1] = (uint8_t)((v >> 8) & 0xFF);
    uart_send_bytes(b, 2);
}

static uint16_t clamp_u32_to_u16(uint32_t v) {
    return v > 65535U ? 65535U : (uint16_t)v;
}
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

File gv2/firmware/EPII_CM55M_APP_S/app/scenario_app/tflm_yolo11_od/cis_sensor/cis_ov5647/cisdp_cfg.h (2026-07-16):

/*
 * cisdp_cfg.h
 *
 *  Created on: 20240122
 *      Author: 901912
 *
 *      HW5X5
 *      RGB: R = W*H byte, G = W*H byte, B = W*H byte
 *      YUV422: Y= W*H byte, U = ((W*H)>>1) byte, V = ((W*H)>>1) byte
 *      YUV420: Y= W*H byte, U = ((W*H)>>2) byte, V = ((W*H)>>2) byte
 *
 *      JPEG
 *      RAW8(YUV400) x4 Compress = ((613+ (W/16)*(H/16)* 64 + 35) >>2 ) <<2 byte
 *      RAW8(YUV400) x10 Compress = ((613+ (W/16)*(H/16)* 24 + 35) >>2 ) <<2 byte
 *      YUV422 x4 Compress = ((623+ (W/16)*(H/16)* 128 + 35) >>2 ) <<2 byte
 *      YUV422 x10 Compress = ((623+ (W/16)*(H/16)* 50 + 35) >>2 ) <<2  byte
 *      YUV420 x4 Compress = ((623+ (W/16)*(H/16)* 96 + 35) >>2 ) <<2  byte
 *      YUV420 x10 Compress = ((623+ (W/16)*(H/16)* 38 + 35) >>2 ) <<2  byte
 *
 *      CDM
 *      Hot Pixel No Pack + No Meta Data: High= W*H byte, Low= W*H byte, Hot Pixel = W*H byte
 *      Hot Pixel Pack + No Meta Data: High= W*H byte, Low= W*H byte, Hot Pixel = W*H/8 byte
 *      Hot Pixel No Pack + Meta Data: High= W*H byte, Low= W*H byte, Hot Pixel = W*H+3*4+H+W+(H<<1) byte
 *      Hot Pixel Pack + Meta Data: High= W*H byte, Low= W*H byte, Hot Pixel = (W*H>>3)+3*4+H+W+(H<<1) byte
 */

#ifndef APP_SCENARIO_CISDP_CFG_H_
#define APP_SCENARIO_CISDP_CFG_H_

#include "hx_drv_gpio.h"
#include "hx_drv_inp.h"

typedef enum
{
	APP_DP_RES_RGB640x480_INP_SUBSAMPLE_1X,
	APP_DP_RES_RGB640x480_INP_SUBSAMPLE_2X,
	APP_DP_RES_RGB640x480_INP_SUBSAMPLE_4X,
	APP_DP_RES_YUV640x480_INP_SUBSAMPLE_1X,
	APP_DP_RES_YUV640x480_INP_SUBSAMPLE_2X,
	APP_DP_RES_YUV640x480_INP_SUBSAMPLE_4X,
}APP_DP_INP_SUBSAMPLE_E;

#define OV5647_SENSOR_I2CID			(0x36)
#define OV5647_MIPI_CLOCK_FEQ		(220) //MHz
#define OV5647_MIPI_LANE_CNT		(2)
#define OV5647_MIPI_DPP				(10) //depth per pixel
#define OV5647_MIPITX_CNTCLK_EN		(1)  //continuous clock output enable
#define OV5647_MIPI_CTRL_OFF		(0x01) //MIPI OFF
#define OV5647_MIPI_CTRL_ON			(0x14) //MIPI ON
#define OV5647_LANE_NB				(2)
#define SENSORDPLIB_SENSOR_OV5647	(SENSORDPLIB_SENSOR_HM2130)
#define OV5647_SUPPORT_BINNING
#define DYNAMIC_ADDRESS

#ifdef OV5647_SUPPORT_BINNING
#define OV5647_SENSOR_WIDTH			640
#define OV5647_SENSOR_HEIGHT 		480
#define OV5647_INP_CROP_WIDTH   	640
#define OV5647_INP_CROP_HEIGHT  	480
#define OV5647_INP_OUT_WIDTH		640
#define OV5647_INP_OUT_HEIGHT		480
#define OV5647_HW2x2_CROP_WIDTH		640
#define OV5647_HW2x2_CROP_HEIGHT	480
#define OV5647_HW5x5_CROP_WIDTH		640
#define OV5647_HW5x5_CROP_HEIGHT	480
#else
#define OV5647_SENSOR_WIDTH 		2592
#define OV5647_SENSOR_HEIGHT 		1944
#define OV5647_INP_CROP_WIDTH   	2592
#define OV5647_INP_CROP_HEIGHT  	1944
#define OV5647_INP_OUT_WIDTH 		648
#define OV5647_INP_OUT_HEIGHT 		486
#define OV5647_HW2x2_CROP_WIDTH 	640
#define OV5647_HW2x2_CROP_HEIGHT 	480
#define OV5647_HW5x5_CROP_WIDTH 	640
#define OV5647_HW5x5_CROP_HEIGHT 	480
#endif	// OV5647_SUPPORT_BINNING

#ifdef TRUSTZONE_SEC
#define EXT_RAM_START   BASE_ADDR_SRAM0_ALIAS
#define MAX_SRAM_ADDR	(BASE_ADDR_SRAM1_ALIAS+1024*1024-1)
#else
#ifndef TRUSTZONE
#define EXT_RAM_START   BASE_ADDR_SRAM0_ALIAS
#define MAX_SRAM_ADDR	(BASE_ADDR_SRAM1_ALIAS+1024*10242-1)
#else
#define EXT_RAM_START   BASE_ADDR_SRAM0
#define MAX_SRAM_ADDR	(BASE_ADDR_SRAM1+1024*1024-1)
#endif
#endif

#define FREE_RAM_START				(BOOT2NDLOADER_BASE)
#define CIS_MIRROR_SETTING			(0x00) //0x00: off/0x01:H-Mirror/0x02:V-Mirror/0x03:HV-Mirror
#define CIS_I2C_ID					OV5647_SENSOR_I2CID
#define CIS_ENABLE_MIPI_INF			(0x01) //0x00: off/0x01: on
#define CIS_MIPI_LANE_NUMBER		(0x02)
#define CIS_ENABLE_HX_AUTOI2C		(0x00) //0x00: off/0x01: on/0x2: on and XSLEEP KEEP HIGH
#define DEAULT_XHSUTDOWN_PIN		AON_GPIO2

/*
 * HM11B1/HM2170 1-bit parser setting
 */
#define SCLK_72M_UTG  					(5) 		//8*24/72 if < 5, set 5
#define SCLK_36M_UTG  					(6) 		//8*24/36
#define SCLK_9M_UTG  					(20)		//ceil(8*24/9.375 = 20.48) = 20
#define SCLK_UTG	 					(SCLK_72M_UTG)
/*
* HM2170 1-bit parser setting: PACK MODE
* REG_INP_RX_LBUF_INSERT_H_FPORCH = freq(inp_cclk) * sensor_hblank_time / 2
*/
#define SCLK_9M_FPORCH					(2047)
#define SCLK_72M_FPORCH					(542)
#define RX_LBUF_INSERT_H_FPORCH			(SCLK_72M_FPORCH)


/*
 * DP SENCTRL CFG
 */
#define SENCTRL_SENSOR_TYPE			SENSORDPLIB_SENSOR_OV5647
#define SENCTRL_STREAM_TYPE			SENSORDPLIB_STREAM_NONEAOS
#define SENCTRL_SENSOR_WIDTH 		OV5647_SENSOR_WIDTH
#define SENCTRL_SENSOR_HEIGHT 		OV5647_SENSOR_HEIGHT
#define SENCTRL_SENSOR_CH	 		3

/*
 * DP INP CFG
 *
 * SENSOR --> INP_CROP --> INP_BINNING --> INP_SUBSAMPLE
 *
 * CROP DISABLE: DP_INP_CROP_START_X/DP_INP_CROP_START_Y/DP_INP_CROP_WIDTH/DP_INP_CROP_HEIGHT all 0
 */
#define DP_INP_CASE					2
#if(DP_INP_CASE == 1)
#define DP_INP_SUBSAMPLE			INP_SUBSAMPLE_DISABLE
#elif(DP_INP_CASE == 2)
#define DP_INP_SUBSAMPLE			INP_SUBSAMPLE_4TO2
#elif(DP_INP_CASE == 3)
#define DP_INP_SUBSAMPLE			INP_SUBSAMPLE_8TO2
#else
#define DP_INP_SUBSAMPLE			INP_SUBSAMPLE_DISABLE
#endif

#define DP_INP_BINNING				INP_BINNING_DISABLE
#define DP_INP_CROP_START_X			0
#define DP_INP_CROP_START_Y			0
#define DP_INP_CROP_WIDTH          	0
#define DP_INP_CROP_HEIGHT         	0
#if (DP_INP_CASE == 1)
#define DP_INP_OUT_WIDTH 		    SENCTRL_SENSOR_WIDTH
#define DP_INP_OUT_HEIGHT 		    SENCTRL_SENSOR_HEIGHT
#elif(DP_INP_CASE == 2)
#define DP_INP_OUT_WIDTH 		    320
#define DP_INP_OUT_HEIGHT 		    240
#elif(DP_INP_CASE == 3)
#define DP_INP_OUT_WIDTH 		    160
#define DP_INP_OUT_HEIGHT 		    120
#else
#define DP_INP_OUT_WIDTH 		    SENCTRL_SENSOR_WIDTH
#define DP_INP_OUT_HEIGHT 		    SENCTRL_SENSOR_HEIGHT
#endif

#define DP_INP_1X_SUBSAMPLE			INP_SUBSAMPLE_DISABLE
#define DP_INP_1X_OUT_WIDTH 	    640
#define DP_INP_1X_OUT_HEIGHT	    480



/*
 * DP HW2X2 CFG
 *
 * LIMITATION:
 * 2X2 SUBSAMPLE LT,LB,RT,RBBINNING (WIDTH/2, HEIGHT/2, MIN:2X2, MAX:640X480)
 * 1/3 SUBSAMPLE (WIDTH/3, HEIGHT/3, MIN:3X3, MAX:639X480)
 */
#define DP_HW2X2_PATH				HW2x2_PATH_THROUGH
#define DP_HW2X2_PROCESS_MODE		HW2x2_MODE_UNITY
#define DP_HW2X2_CROP_START_X		0
#define DP_HW2X2_CROP_START_Y		0
#define DP_HW2X2_CROP_WIDTH			DP_INP_OUT_WIDTH
#define DP_HW2X2_CROP_HEIGHT		DP_INP_OUT_HEIGHT
#define DP_HW2X2_ROUND_MODE			HW2x2_ROUNDMODE_FLOOR
#define DP_HW2X2_OUT_WIDTH          (DP_INP_OUT_WIDTH)
#define DP_HW2X2_OUT_HEIGHT         (DP_INP_OUT_HEIGHT)
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

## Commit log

2026-05-04 Initial VST-BASE integration structure
    [T-SIM7080G-S#-PINS.csv, huge_app.csv]
2026-06-27 SOLAR OPTIMZE
    [power_uptime_dataset.csv]
2026-06-27 Update t-sim-motor-shield submodule
2026-07-16 Keep status LED on for USB power
2026-07-16 GV2 firmware
    [ICVSBContent.cfg, ICVSBKey1_2LvCert.cfg, OEMSBContent.cfg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]
2026-07-16 T-SIM FIRMWARE
    [huge_app.csv]
